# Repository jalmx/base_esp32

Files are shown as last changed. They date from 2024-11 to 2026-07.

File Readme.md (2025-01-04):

# Base for ESP32 for DevKit V4

## Schematic

This board is a base to connect different components to test. Make easy life

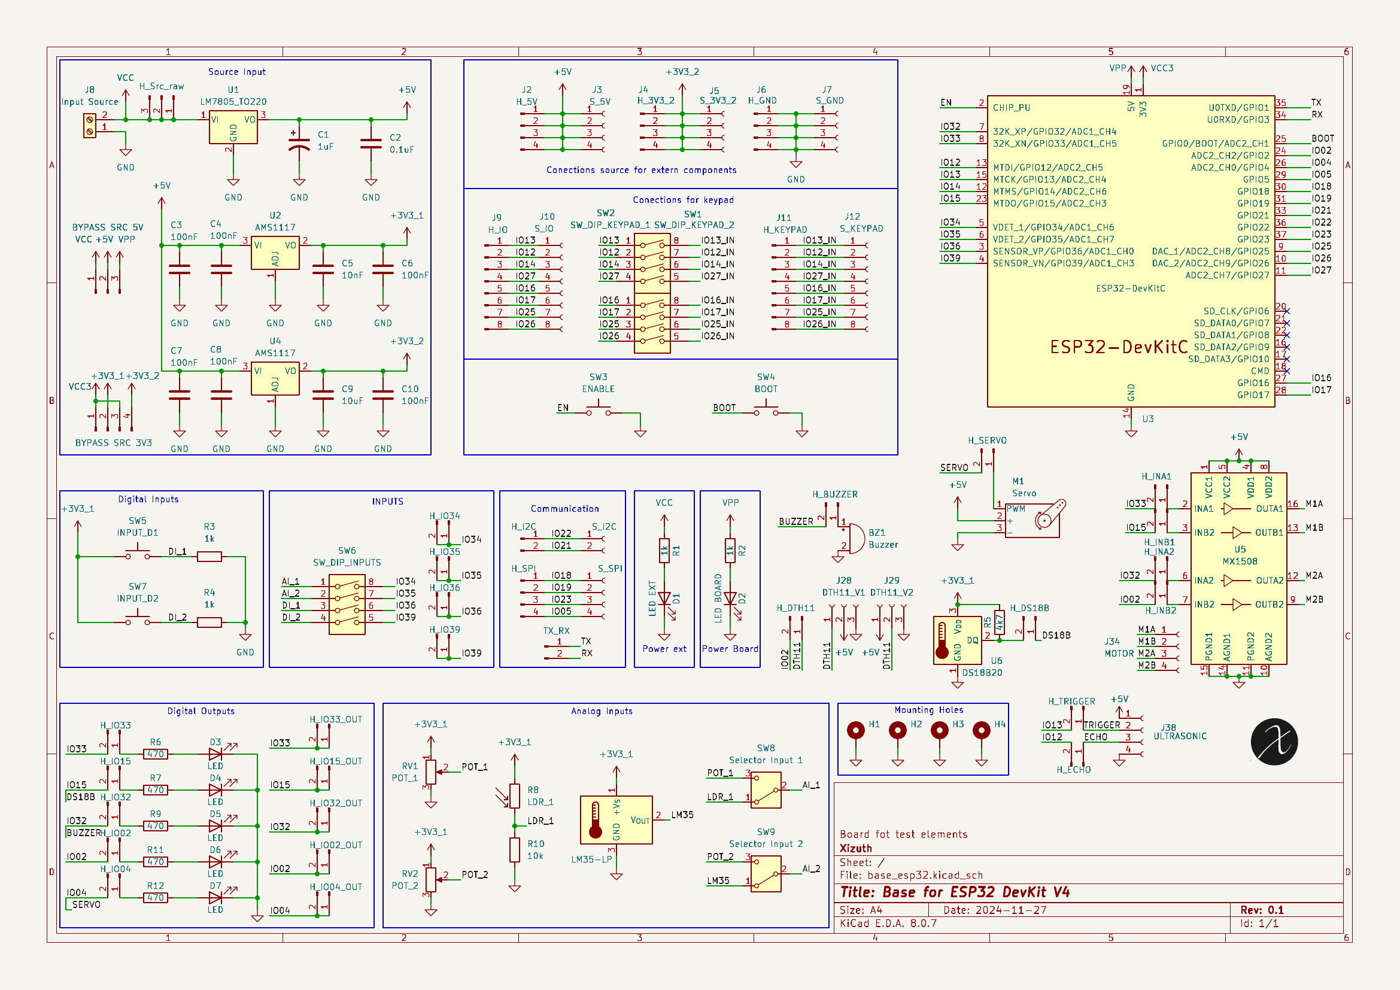
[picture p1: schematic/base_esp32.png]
schematic


## Silkscreen

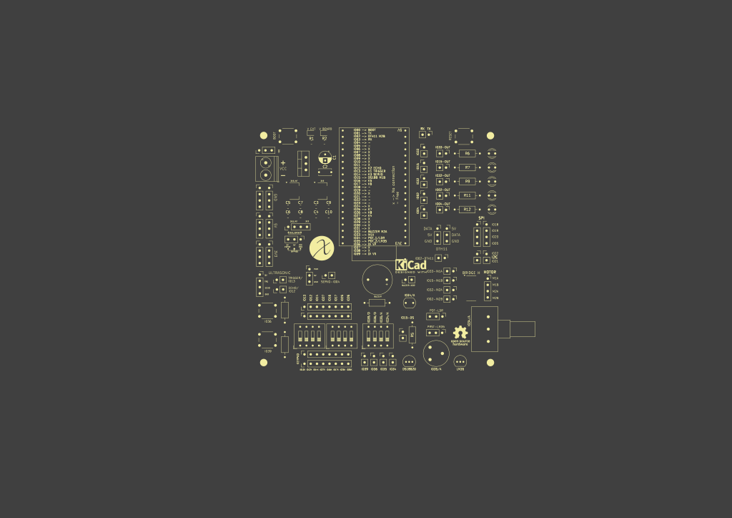
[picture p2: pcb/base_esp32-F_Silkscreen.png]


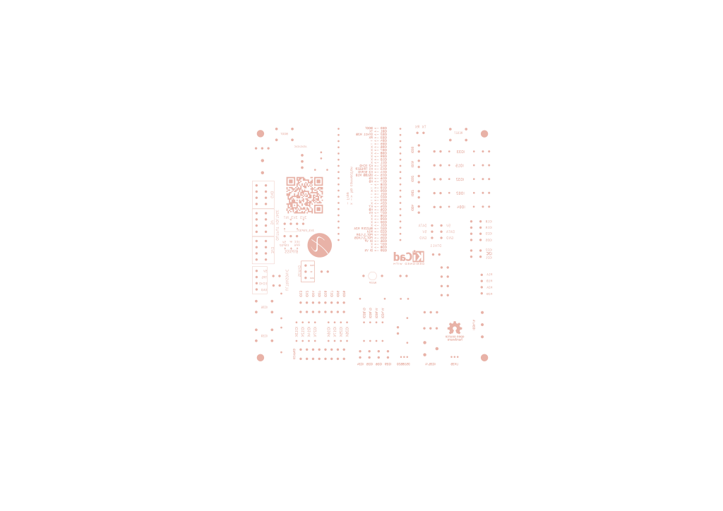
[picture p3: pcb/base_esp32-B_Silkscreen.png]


## 3D

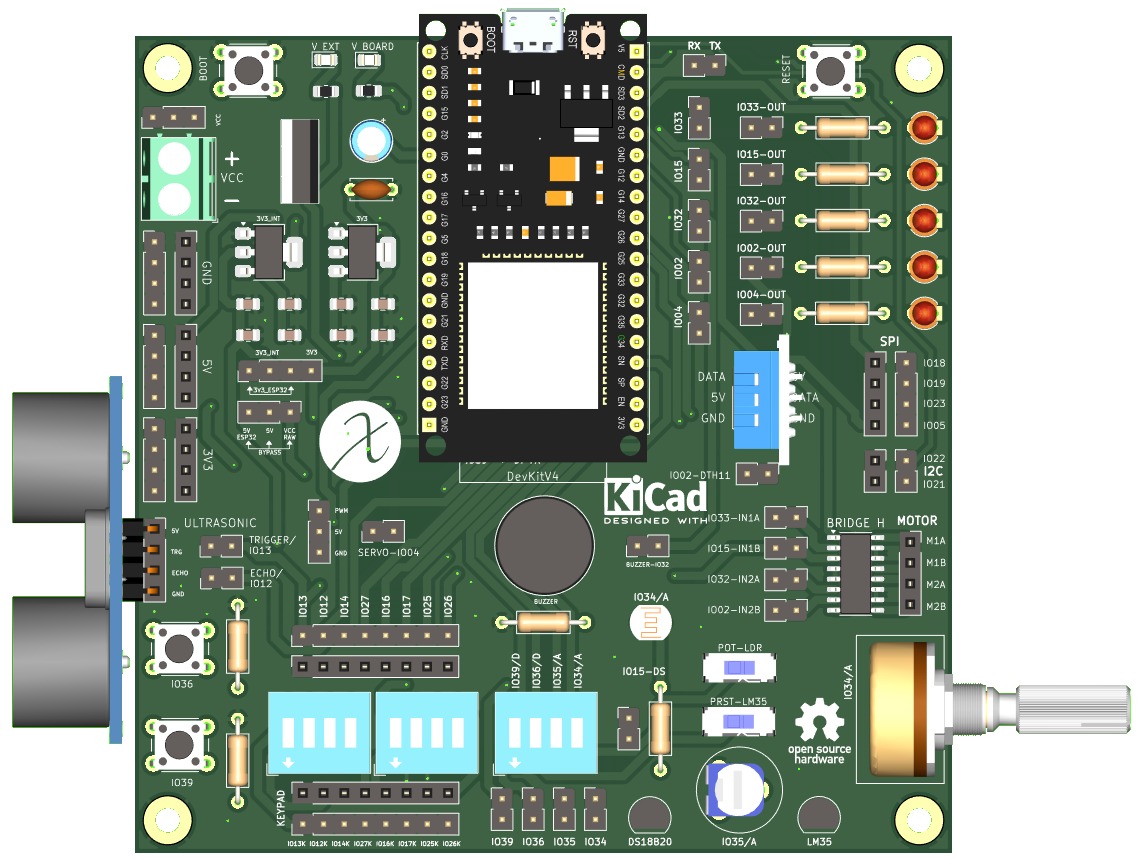
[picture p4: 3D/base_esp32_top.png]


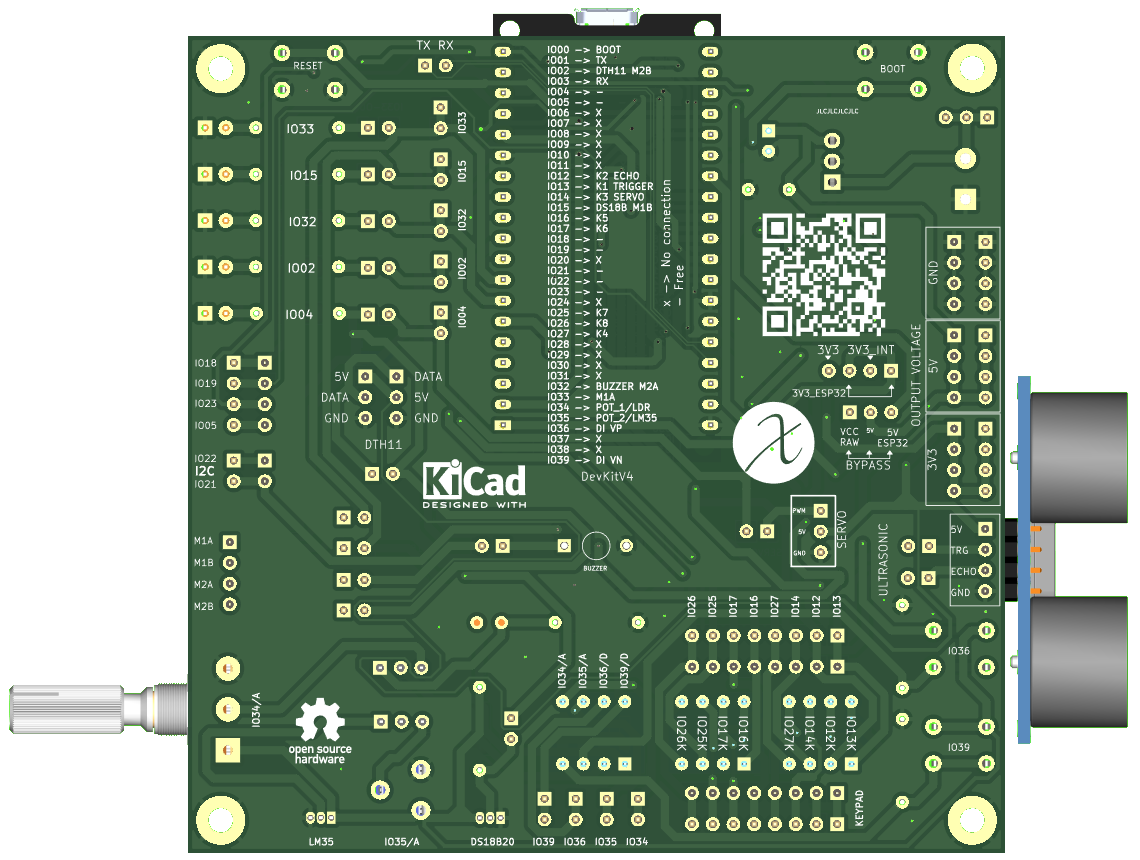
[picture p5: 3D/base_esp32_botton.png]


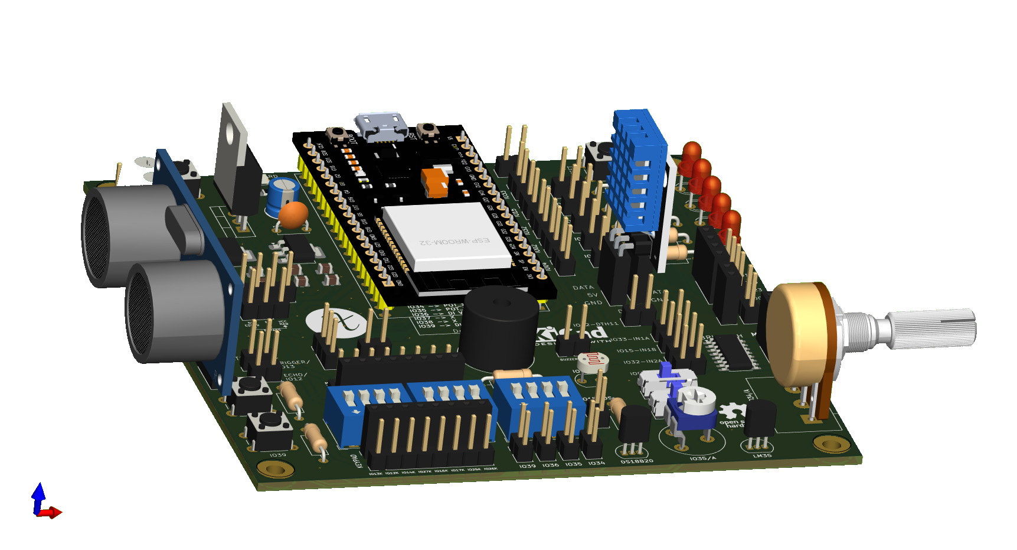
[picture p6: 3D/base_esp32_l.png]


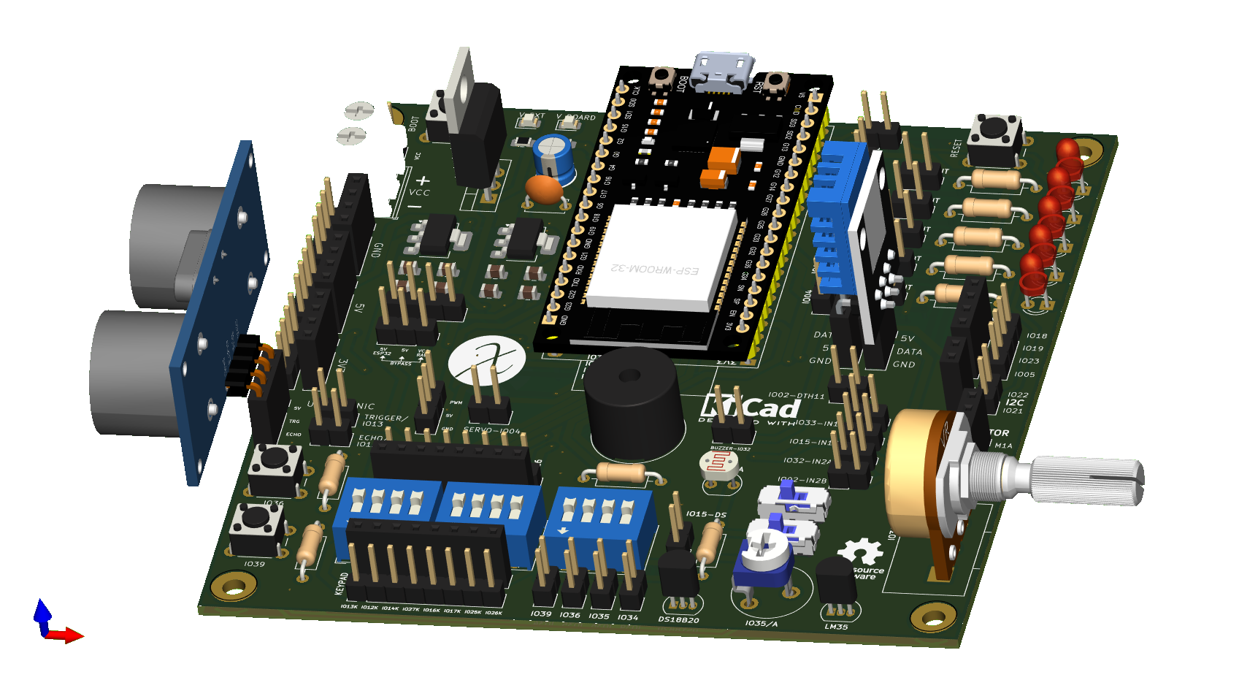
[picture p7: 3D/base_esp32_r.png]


## Ray

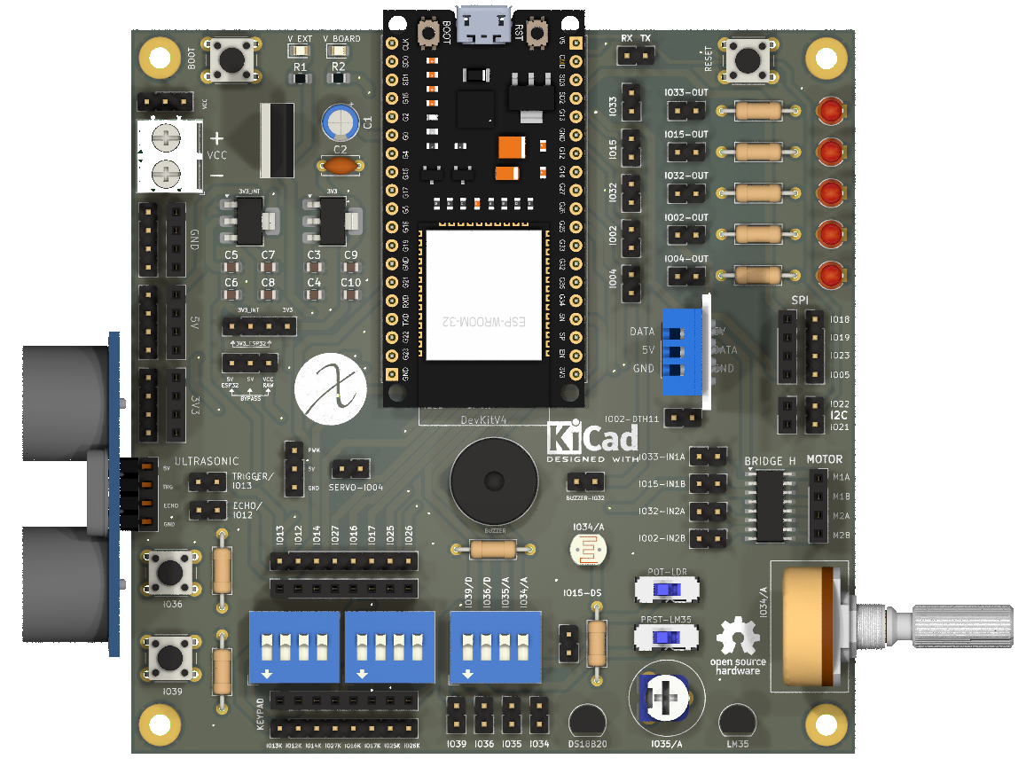
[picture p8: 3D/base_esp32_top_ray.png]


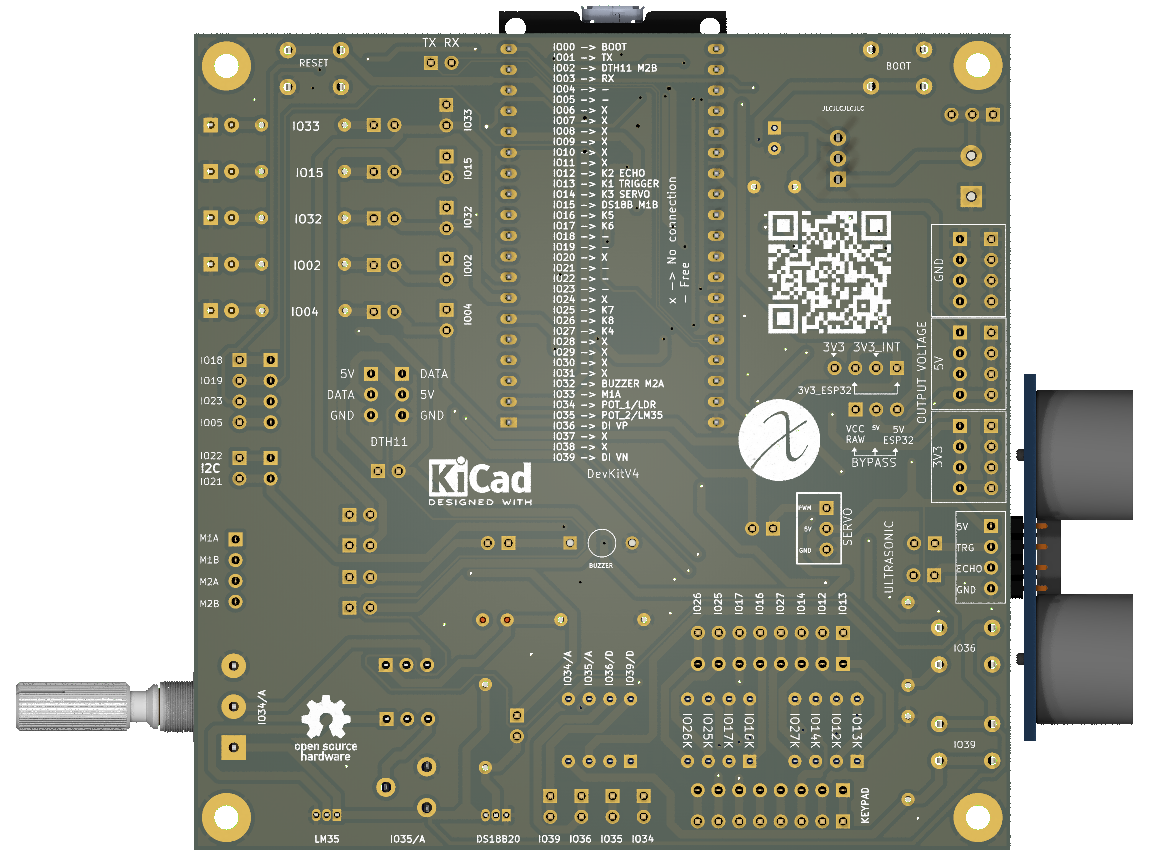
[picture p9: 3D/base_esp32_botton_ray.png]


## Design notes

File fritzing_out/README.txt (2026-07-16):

KiCad2Fritzing conversion output
Source board: /media/data/Projects/base_esp32/base_esp32.kicad_pcb

Generated files:
  Intermediate model: board_model.json
  Connector model: fritzing_connectors.json
  Fritzing part definition: base_esp32.fzp
  SVG views: icon.svg, breadboard.svg, schematic.svg, pcb.svg
  Fritzing shareable part: base_esp32.fzpz (ready to import)
  Validation report: artifact_validation.json

To import into Fritzing:
  1. Open Fritzing
  2. Right-click in the 'Mine' bin → Import...
  3. Select base_esp32.fzpz

Next step: refine SVG geometry from real board footprint data.

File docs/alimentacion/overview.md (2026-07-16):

# Visión general - Alimentación

## Árbol de potencia (Power Tree)

```
                    ┌─────────────────┐
                    │   ENTRADAS      │
                    │  ┌───────────┐  │
                    │  │ Jack DC   │  │  7-12V DC
                    │  │ 2.1mm     │──┤
                    │  └───────────┘  │
                    │        │        │
                    │  ┌───────────┐  │
                    │  │ USB Micro │  │  5V USB
                    │  │    -B     │──┤
                    │  └───────────┘  │
                    └────────┬────────┘
                             │
                    ┌────────▼────────┐
                    │  Diodo ORing    │  1N5819 Schottky
                    │  (Protección    │  Evita backfeed
                    │   polaridad)    │
                    └────────┬────────┘
                             │
                    ┌────────▼────────┐
                    │   LM7805CT      │  Regulador lineal 5V
                    │   TO-220        │  1.5A max
                    │  + Disipador    │  Dropout ~2V
                    └────────┬────────┘
                             │
              ┌──────────────┼──────────────┐
              │              │              │
       ┌──────▼──────┐ ┌─────▼─────┐ ┌─────▼─────┐
       │  +5V Rail   │ │  A9013    │ │  MX1508   │
       │  (Main)     │ │  Current  │ │  VMotor   │
       │             │ │  Sense    │ │           │
       └──────┬──────┘ └─────┬─────┘ └─────┬─────┘
              │              │             │
       ┌──────▼──────┐       │       ┌─────▼─────┐
       │ AMS1117-3.3 │       │       │ Terminal  │
       │  3.3V 800mA │       │       │  Block    │
       └──────┬──────┘       │       │  (Motor   │
              │              │       │  Power)   │
       ┌──────▼──────┐       │       └───────────┘
       │  +3.3V Rail │       │
       │  (Logic)    │       │
       └─────────────┘       │
                             │
                    ┌────────▼────────┐
                    │     SERVO       │  5V directo
                    │   Connector     │  (desde +5V Rail)
                    └─────────────────┘
```

## Rails de alimentación

| Rail | Voltaje | Corriente max | Origen | Consumidores |
|---|---|---|---|---|
| **VIN** | 7-12V | 1.5A | Jack/USB | LM7805 input |
| **+5V** | 5.0V | 1.5A | LM7805 | MX1508, Servo, Terminal, A9013, LED 5V |
| **+3.3V** | 3.3V | 800mA | AMS1117 | ESP32, Sensores, LEDs 3.3V, Pull-ups |
| **VMOTOR** | 5.0V | 2A | +5V Rail | MX1508 VM pin (separado por track ancho) |

## Esquema de protecciones

```
VIN (7-12V)
    │
    ├─► D1 (1N5819) ──► LM7805 ──► +5V
    │                    │
    │                    ├─► C_bulk 100µF
    │                    ├─► C_dec 100nF
    │                    ├─► LED_5V + 1kΩ
    │                    ├─► A9013 VCC
    │                    ├─► MX1508 VM
    │                    ├─► Servo VCC
    │                    └─► Terminal Block
    │
    └─► D2 (1N5819) ──► USB 5V ──► (Diodo ORing con Jack)
```

## Cálculos térmicos

### LM7805 (TO-220)

| Parámetro | Valor |
|---|---|
| V_in max | 12V |
| V_out | 5V |
| I_out max | 1.5A (datasheet) |
| I_typical | 500mA (ESP32 + sensores + LEDs) |
| P_dis = (Vin-Vout)×I | (12-5)×0.5 = **3.5W** |
| θ_JA (sin heatsink) | ~50°C/W |
| ΔT (sin heatsink) | 3.5×50 = **175°C** ❌ |
| θ_JA (con heatsink 10°C/W) | 3.5×10 = **35°C** ✅ |
| θ_JA (4 vias térmicas + pour) | ~25°C/W = **87.5°C** ⚠️ |

**Recomendación**: Usar disipador pequeño o limitar Vin a 9V max para uso continuo.

### AMS1117-3.3 (SOT-223)

| Parámetro | Valor |
|---|---|
| V_in | 5V |
| V_out | 3.3V |
| I_out max | 800mA |
| I_typical | 200mA (ESP32 TX + sensores) |
| P_dis | (5-3.3)×0.2 = **0.34W** |
| θ_JA (SOT-223 + vias) | ~40°C/W |
| ΔT | 0.34×40 = **13.6°C** ✅ |

### MX1508

- Pad térmico expuesto soldado a polygon VCC_MOTOR + vias a GND
- Corriente motor típica: 500mA-1A
- Protección térmica interna (150°C shutdown)

## Secuencia de encendido

```
1. VIN aplicado (Jack o USB)
         │
         ▼
2. Diodo ORing conduce
         │
         ▼
3. LM7805 enciende → +5V sube
         │
         ├─► LED 5V enciende
         ├─► A9013 alimentado
         ├─► MX1508 VM alimentado
         └─► Servo VCC alimentado
         │
         ▼
4. AMS1117 enciende → +3.3V sube
         │
         ├─► LED 3.3V enciende
         ├─► ESP32 sale de reset (EN HIGH)
         └─► Sensores alimentados
         │
         ▼
5. ESP32 boot → firmware inicia
```

## Puntos de test (Test Points)

| TP | Net | Ubicación | Uso |
|----|-----|---|-----|
| TP1 | VIN | Cerca Jack | Verificar entrada |
| TP2 | +5V | Cerca LM7805 out | Verificar 5V |
| TP3 | +3.3V | Cerca AMS1117 out | Verificar 3.3V |
| TP4 | GND | Múltiples | Referencia |
| TP5 | IMON_OUT | Cerca A9013 | Medir corriente |
| TP6 | VMOTOR | Cerca MX1508 | Verificar motor power |

## Medidas típicas (multímetro)

| Punto | Esperado | Tolerancia |
|---|---|---|
| Jack DC | 7-12V | ±5% |
| USB 5V | 4.75-5.25V | ±5% |
| +5V Rail | 4.9-5.1V | ±2% |
| +3.3V Rail | 3.25-3.35V | ±1.5% |
| Dropout LM7805 | ~2V | - |
| Dropout AMS1117 | ~1.1V | - |
| Corriente reposo (+5V) | ~50mA | - |
| Corriente reposo (+3.3V) | ~80mA | - |
| Corriente WiFi TX (+3.3V) | +150mA pico | - |

## Mejoras planificadas (v0.5)

Ver [Cambios planificados](../contribuir/guia.md#cambios-planificados)

- [ ] Añadir PTC/Polyfuse en entrada VIN
- [ ] TVS diodo en entrada (protección ESD/surge)
- [ ] LED indicador "Power Good" (AND de 5V y 3.3V)
- [ ] Jumper medición corriente serie en +5V/+3.3V

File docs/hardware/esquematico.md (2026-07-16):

# Esquemático

## Visión general

El esquemático está organizado en **hojas jerárquicas** por bloques funcionales:

```
base_esp32.kicad_sch
├── Portada (Title Block)
├── Hoja principal: Conexiones ESP32
├── Power_5V: LM7805 + entrada DC/USB
├── Power_3V3: AMS1117 3.3V
├── Power_Monitor: A9013 current sense
├── Motor_Driver: MX1508
├── Sensors: DS18B20, LM35, LDR
├── Actuators: Buzzer, LEDs, Servo, RGB
├── Inputs: DIP, Push, SPDT, Pot
├── Connectors: Headers, Terminal, Servo
└── Mounting: 4× Mounting holes
```

## Hoja principal: ESP32 DevKit V4

### Socket pinout (J1-J2, headers 2×19)

| Pin ESP32 | Función Base | Componente conectado |
|---|---|---|
| **GPIO0** | Boot/LED | LED D1 (pull-up) |
| **GPIO2** | LED Built-in / RGB | LED D2 + RGB WS2812B |
| **GPIO4** | User LED | LED D3 |
| **GPIO5** | User LED | LED D4 |
| **GPIO12** | Motor IN1 | MX1508 IN1 |
| **GPIO13** | Motor IN2 | MX1508 IN2 |
| **GPIO14** | Motor IN3 | MX1508 IN3 |
| **GPIO15** | Motor IN4 / ADC2_CH3 | MX1508 IN4 + Pot |
| **GPIO16** | Buzzer | Buzzer pasivo |
| **GPIO17** | DS18B20 | 1-Wire temp sensor |
| **GPIO18** | Servo PWM | Conector servo |
| **GPIO19** | I2C SCL | Header expansion |
| **GPIO21** | I2C SDA | Header expansion |
| **GPIO22** | SPI MISO | Header expansion |
| **GPIO23** | SPI MOSI | Header expansion |
| **GPIO25** | ADC2_CH8 / DAC1 | LM35 / User |
| **GPIO26** | ADC2_CH9 / DAC2 | LDR / User |
| **GPIO27** | ADC2_CH7 | User |
| **GPIO32** | ADC1_CH4 | User |
| **GPIO33** | ADC1_CH5 | User |
| **GPIO34** | ADC1_CH6 (input only) | Potenciómetro |
| **GPIO35** | ADC1_CH7 (input only) | User |
| **GPIO36** | ADC1_CH0 (input only) | LM35 |
| **GPIO39** | ADC1_CH3 (input only) | LDR |

> **Nota**: GPIO6-11 conectados a flash interno (no usar). GPIO34-39 solo entrada.

## Hoja Power_5V: LM7805

```
VIN (7-12V) ──┬──┬──► Jack DC (J_PWR)
              │  └──► USB 5V (via diodo Schottky)
              ▼
         ┌─────────┐
         │ LM7805  │──► +5V Rail
         │ TO-220  │     │
         └────┬────┘     ├─► Motor Driver (MX1508 VCC)
              │          ├─► Servo VCC
              │          ├─► Terminal Block (Motor Power)
              │          └─► A9013 Sense Input
              ▼
           GND
```

**Componentes clave:**
- **C1**: 470µF electrolítico (bulk input)
- **C2**: 100nF cerámico (decoupling input)
- **C3**: 100µF electrolítico (bulk output)
- **C4**: 100nF cerámico (decoupling output)
- **D1**: Diodo Schottky 1N5819 (protección USB/Jack)
- **D2**: LED Power 5V + R (1kΩ)
- **JP1**: Jumper selección fuente (Jack vs USB)

## Hoja Power_3V3: AMS1117

```
+5V Rail ──┬──► AMS1117-3.3 ──► +3.3V Rail
           │        │
           │        ├─► C5: 100µF (output bulk)
           │        └─► C6: 100nF (decoupling)
           │
           └──► LED 3.3V + R (1kΩ)
```

**Salida**: 800mA max (suficiente para ESP32 + sensores)

## Hoja Power_Monitor: A9013

```
+5V Rail ──► A9013 (Hall Effect) ──► GPIO34 (ADC1_CH6)
                    │
                    └─► Sensitivity: 400mV/A
                        Offset: 2.5V @ 0A
                        Range: ±5A
```

**Fórmula conversión:**
```cpp
float current = (adc_voltage - 2.5) / 0.4;  // Amperios
```

## Hoja Motor_Driver: MX1508

```
GPIO12 ──► IN1 ──┐
GPIO13 ──► IN2 ──┤   MX1508 (Dual H-Bridge)
GPIO14 ──► IN3 ──┤   │ OUT1+OUT2 = Motor A
GPIO15 ──► IN4 ──┘   │ OUT3+OUT4 = Motor B
                     ▼
              +5V Rail (VM)
              GND
              Terminal Block: MOT_A+, MOT_A-, MOT_B+, MOT_B-
```

**Especificaciones MX1508:**
- Voltaje: 2-10V
- Corriente: 1.5A cont / 2.5A pico por canal
- PWM: Hasta 20kHz
- Protección: Térmica, under-voltage

## Hoja Sensors

### DS18B20 (1-Wire)
```
GPIO17 ──► Data (pull-up 4.7kΩ a 3.3V)
VDD ──► 3.3V
GND ──► GND
```
**Dirección**: Parasite power o VDD mode (configurable por jumper)

### LM35 (Analógico)
```
GPIO36 (ADC1_CH0) ──► Vout
VDD ──► 3.3V
GND ──► GND
```
**Fórmula**: `Temp(°C) = ADC_mV / 10`

### LDR + Divisor tensión
```
GPIO39 (ADC1_CH3) ──► Punto medio
              ┌─────┴─────┐
              ▼           ▼
           LDR          10kΩ
              │           │
             3.3V        GND
```

## Hoja Actuators

### Buzzer pasivo
```
GPIO16 ──► Buzzer (+)
GND ─────► Buzzer (-)
```
**Frecuencia**: Control por PWM/tone()

### LEDs Usuario (×4)
```
GPIO0  ──► LED D1 (R=330Ω) ──► GND  (Boot indicator)
GPIO2  ──► LED D2 (R=330Ω) ──► GND  (Built-in / RGB)
GPIO4  ──► LED D3 (R=330Ω) ──► GND
GPIO5  ──► LED D4 (R=330Ω) ──► GND
```

### LED RGB (WS2812B)
```
GPIO2 ──► DIN (data)
3.3V ───► VDD
GND ────► VSS
```
**Nota**: Comparte GPIO2 con LED D2 - usar uno a la vez

### Conector Servo (3 pines estándar)
```
GPIO18 ──► Signal
5V  ─────► VCC (from 5V rail)
GND ─────► GND
```

## Hoja Inputs

### DIP Switch ×4 (SW1)
```
GPIO27 ──► SW1-1
GPIO32 ──► SW1-2
GPIO33 ──► SW1-3
GPIO35 ──► SW1-4
Común ───► GND (pull-up interno ESP32)
```

### Push Button (SW2)
```
GPIO25 ──► SW2 (momentary)
Común ───► GND (pull-up interno)
```

### SPDT Switch (SW3)
```
GPIO26 ──► SW3-COM
        ├──► SW3-NO (3.3V via R pull-up)
        └──► SW3-NC (GND)
```

### Potenciómetro 10k (RV1)
```
GPIO34 (ADC1_CH6) ──► Wiper
3.3V ────────────────► End 1
GND ────────────────► End 2
```

## Hoja Connectors

### Headers ESP32 (J1, J2 - 2×19)
- Pitch 2.54mm
- Macho en PCB, Hembra en DevKit
- Todas las señales GPIO, Power, GND

### Terminal Block 2×2 (J_TERM)
```
Pin 1: Motor A+
Pin 2: Motor A-
Pin 3: Motor B+
Pin 4: Motor B-
```
**Rating**: 10A, 250V, wire 12-24 AWG

### Conector Servo (J_SERVO)
- 3 pines 2.54mm (Signal, VCC, GND)
- Compatible estándar Futaba/JR

### Mounting Holes (×4)
- Diámetro 3.2mm (M3)
- Plated para conexión GND opcional
- Esquinas PCB (100×80mm)

## Referencias cruzadas

- [PCB Layout](pcb.md) - Implementación física
- [Componentes](componentes.md) - BOM completa
- [Pinout ESP32](pinout.md) - Mapeo detallado
- [Alimentación](../alimentacion/overview.md) - Análisis power tree

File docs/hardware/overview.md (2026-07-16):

# Visión general del hardware

## Arquitectura del sistema

```
┌─────────────────────────────────────────────────────────────┐
│                      ESP32 DevKit V4                        │
│  ┌─────────┐  ┌─────────┐  ┌─────────┐  ┌─────────┐        │
│  │  GPIO   │  │  ADC    │  │  PWM    │  │  Comm   │        │
│  │  0-39   │  │  18 ch  │  │  16 ch  │  │ I2C/SPI │        │
│  └────┬────┘  └────┬────┘  └────┬────┘  └────┬────┘        │
└───────┼────────────┼────────────┼────────────┼──────────────┘
        │            │            │            │
  ┌─────┴─────┐ ┌────┴────┐ ┌─────┴─────┐ ┌────┴────┐
  │  Power    │ │ Sensors │ │ Actuators │ │  I/O    │
  │  5V/3.3V  │ │ DS18B20 │ │ MX1508    │ │ Switches│
  │  Monitor  │ │ LM35    │ │ Servo     │ │ Potenci │
  │  A9013    │ │ LDR     │ │ Buzzer    │ │ LEDs    │
  └───────────┘ └─────────┘ └───────────┘ └─────────┘
```

## Vista 3D de la placa

=== "Superior"
    Top

=== "Inferior"
    Bottom

=== "Lateral Izquierda"
    Left

=== "Lateral Derecha"
    Right

=== "Render Superior"
    Ray Top

=== "Render Inferior"
    Ray Bottom

## Bloques funcionales

| Bloque | Componentes clave | Página |
|---|---|---|
| **Alimentación** | LM7805, AMS1117, A9013, jack DC, USB | [Alimentación](../alimentacion/overview.md) |
| **MCU** | ESP32 DevKit V4 socket | [Pinout](pinout.md) |
| **Motor DC** | MX1508 (2 canales H-bridge) | [Actuadores](../perifericos/actuadores.md) |
| **Sensores** | DS18B20, LM35, LDR | [Sensores](../perifericos/sensores.md) |
| **Actuadores** | Buzzer, 4×LED, Servo, LED RGB | [Actuadores](../perifericos/actuadores.md) |
| **Entradas** | DIP×4, Push, SPDT, Pot 10k | [Entradas](../perifericos/entradas.md) |
| **Conectividad** | Headers ESP32, Terminal tornillo, Servo | [Pinout](pinout.md) |

## Esquemático completo

Esquemático

## PCB Layout

=== "Capa Superior (F.Cu)"
    Top Copper

=== "Capa Inferior (B.Cu)"
    Bottom Copper

=== "Silkscreen Superior"
    Top Silk

=== "Silkscreen Inferior"
    Bottom Silk

=== "Máscara Superior"
    Top Mask

=== "Máscara Inferior"
    Bottom Mask

## Decisiones de diseño clave

1. **Alimentación dual**: 5V para motor/servo, 3.3V para ESP32 y sensores
2. **Monitor corriente**: A9013 en rail principal para protección
3. **Driver MX1508**: SMD, compacto, 1.5A/canal, PWM hasta 20kHz
4. **Socket ESP32**: Permite cambio de módulo, reduce riesgo soldadura
5. **Headers estándar**: Pitch 2.54mm compatible breadboard/dupont
6. **Terminal tornillo**: Conexión robusta para motor/alimentación externa
7. **Test points**: Verificación rails de alimentación sin soldar

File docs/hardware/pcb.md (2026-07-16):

# PCB Layout

## Especificaciones físicas

| Parámetro | Valor |
|---|---|
| **Dimensiones** | 100mm × 80mm |
| **Capas** | 2 (Top/Bottom) |
| **Material** | FR-4, 1.6mm |
| **Cobre** | 35µm (1oz) |
| **Via mínimo** | 0.3mm / 0.6mm pad |
| **Track mínimo** | 0.15mm (6mil) |
| **Clearance** | 0.15mm (6mil) |
| **Huecos montaje** | 4× M3 (3.2mm plated) |

## Stackup

```
┌─────────────────────────────────────┐
│  Top Silkscreen (F.SilkS)           │
│  Top Solder Mask (F.Mask)           │
│  Top Copper (F.Cu) ◄── Señales + Power │
├─────────────────────────────────────┤  Core FR-4 1.4mm
│  Bottom Copper (B.Cu) ◄── GND Pour  │
│  Bottom Solder Mask (B.Mask)        │
│  Bottom Silkscreen (B.SilkS)        │
└─────────────────────────────────────┘
```

## Capas de cobre

=== "Top Copper (F.Cu)"
    Top Copper
    - Ruteo principal señales
    - Polygons: +3.3V, +5V, VCC_MOTOR
    - Pads SMD componentes

=== "Bottom Copper (B.Cu)"
    Bottom Copper
    - **Ground Pour** completa (GND net)
    - Algunas señales de cruce
    - Pads THT

## Planos de alimentación (Polygons)

### Top Layer Polygons

| Net | Área | Props |
|-----|---|---|
| **+5V** | Zona inferior izq | Thermal relief vias |
| **+3.3V** | Zona central | Zona central | Thermal relief |
| **VCC_MOTOR** | Debajo MX1508 | Direct pour, sin relief |
| **GND** | Relleno resto | Via stitching |

### Bottom Layer
- **GND Pour** completo con **via stitching** cada 5mm
- Conecta a GND pads THT y vias térmicas

## Reglas de diseño (Design Rules)

| Regla | Valor | Aplicación |
|---|---|---|
| Clearance | 0.15mm (6mil) | General |
| Track width (signal) | 0.2mm (8mil) | GPIO, comms |
| Track width (power 5V) | 0.5mm (20mil) | LM7805, MX1508 |
| Track width (power 3.3V) | 0.4mm (16mil) | AMS1117, ESP32 |
| Track width (motor) | 1.0mm (40mil) | Terminal block ↔ MX1508 |
| Via size | 0.3/0.6mm | Signal |
| Via power | 0.5/1.0mm | Power polygons |
| Thermal relief | 0.25mm gap, 4 spokes | Polygon connects |

## Decisiones de layout críticas

### 1. Separación dominios de potencia
```
┌────────────────────────────────────────┐
│  +5V (Motor)    │  +3.3V (Logic)       │
│  ┌──────────┐   │  ┌──────────┐        │
│  │ LM7805   │   │  │ AMS1117  │        │
│  │ MX1508   │   │  │ ESP32    │        │
│  │ Terminal │   │  │ Sensors  │        │
│  └──────────┘   │  └──────────┘        │
│        │        │        │             │
│        └────────┴────────┘             │
│                 GND (common)           │
└────────────────────────────────────────┘
```
- **GND común** (star ground en conector alimentación)
- Polygons separados en Top, unidos por vias en GND
- Evita loops de corriente motor en ground logic

### 2. Ruteo señales sensibles
- **ADC traces** (LM35, LDR, Pot): Cortas, lejos de PWM motor
- **1-Wire (DS18B20)**: Pull-up cerca GPIO, track ancho 0.3mm
- **I2C/SPI**: Paralelas, ground guard entre líneas
- **PWM Motor**: Tracks anchas, ground shield adyacente

### 3. Disipación térmica
- **LM7805**: Pad TO-220 con 4 vias térmicas a GND pour bottom
- **AMS1117**: Pad SOT-223 con vias térmicas
- **MX1508**: Pad expuesto conectado a VCC_MOTOR polygon + vias a GND

### 4. Conector ESP32
- Headers 2×19 alineados borde PCB
- Señales GPIO ruteadas perpendicular al conector
- Minimiza longitud stubs

## Silkscreen (F.SilkS / B.SilkS)

=== "Top Silkscreen"
    Top Silk

=== "Bottom Silkscreen"
    Bottom Silk

**Elementos clave:**
- ✅ Referencias componentes (R1, C1, U1, J1...)
- ✅ Polaridad LED, diodos, electrolíticos
- ✅ Pin 1 en conectores e ICs
- ✅ Etiquetas funcionales: "5V", "3.3V", "GND", "MOTOR", "SERVO"
- ✅ **NUEVO v0.4**: Nombres reguladores junto a footprint
- ✅ Logo Xizuth + QR code repositorio
- ✅ Versión PCB (v0.4) y fecha

## Solder Mask & Paste

=== "Top Mask"
    Top Mask

=== "Bottom Mask"
    Bottom Mask

=== "Top Paste"
    Top Paste

=== "Bottom Paste"
    Bottom Paste

## Edge Cuts

Edge Cuts

- Rectángulo 100×80mm
- Esquinas redondeadas R=2mm
- 4 cutouts para mounting holes M3
- Sin cutouts internos

## Fabricación - Archivos Gerber

Ver [Fabricación > Archivos Gerber](../fabricacion/gerber.md) para lista completa y visualizador.

## Validación DRC

```bash
# Ejecutar DRC en KiCad 8/9
# Inspect > Design Rule Checker
# Run DRC
# Errors: 0 | Warnings: 0 (esperado)
```

**Checks críticos:**
- [ ] Clearance violations
- [ ] Track width vs current
- [ ] Via count thermal relief
- [ ] Unconnected nets
- [ ] Footprint courtyard overlaps
- [ ] Silk over pads
- [ ] Missing thermal reliefs

## Exportaciones disponibles

| Formato | Ubicación | Uso |
|---|---|-----|
| **KiCad PCB** | `base_esp32.kicad_pcb` | Edición |
| **Gerber ZIP** | `gerber/base_esp32_v4.zip` | Fabricación |
| **STEP 3D** | `step/base_esp32.step` | Mechanical CAD |
| **SVG Layers** | `pcb/*.svg` | Documentación |
| **PNG Renders** | `3D/*.png` | Visualización |
| **BOM** | `fabricacion/bom.csv` | Compras |
| **Pick&Place** | `fabricacion/pnp.csv` | Assembly SMT |

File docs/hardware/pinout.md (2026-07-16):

# Pinout ESP32 DevKit V4

## Pinout visual

ESP32 DevKit V4 Pinout

## Mapeo Base ESP32 → ESP32 DevKit V4

| Base ESP32 Pin | GPIO | Función Base | Tipo | Notas |
|---|---|---|---|---|
| **J1-1** | GPIO36 (VP) | ADC1_CH0 | Input only | LM35 Temp |
| **J1-2** | GPIO39 (VN) | ADC1_CH3 | Input only | LDR |
| **J1-3** | GPIO34 | ADC1_CH6 | Input only | Potenciómetro |
| **J1-4** | GPIO35 | ADC1_CH7 | Input only | SW_DIP-4 |
| **J1-5** | GPIO32 | ADC1_CH4 / Touch | I/O | SW_DIP-2, LED_USR? |
| **J1-6** | GPIO33 | ADC1_CH5 / Touch | I/O | SW_DIP-3 |
| **J1-7** | GPIO25 | ADC2_CH8 / DAC1 | I/O | Buzzer |
| **J1-8** | GPIO26 | ADC2_CH9 / DAC2 | I/O | SW_SPDT, LDR alt |
| **J1-9** | GPIO27 | ADC2_CH7 / Touch | I/O | SW_DIP-1 |
| **J1-10** | GPIO14 | ADC2_CH6 / Touch | I/O | Motor IN3 |
| **J1-11** | GPIO12 | ADC2_CH5 / Touch | I/O | Motor IN1 (boot strapping!) |
| **J1-12** | GPIO13 | ADC2_CH4 / Touch | I/O | Motor IN2 |
| **J1-13** | GPIO15 | ADC2_CH3 / Touch | I/O | Motor IN4, Pot alt (strap!) |
| **J1-14** | GPIO2 | ADC2_CH2 / Touch | I/O | LED Built-in / RGB DIN |
| **J1-15** | GPIO0 | ADC2_CH1 / Touch | I/O | LED D1 / Boot (strap!) |
| **J1-16** | GPIO4 | ADC2_CH0 / Touch | I/O | LED D3 |
| **J1-17** | GPIO16 | - | I/O | (Libre) |
| **J1-18** | GPIO17 | - | I/O | DS18B20 1-Wire |
| **J1-19** | GPIO5 | - | I/O | LED D4 |
| **J1-20** | GPIO18 | - | I/O | Servo PWM |
| **J1-21** | GPIO19 | - | I/O | I2C SCL / SPI MISO |
| **J1-22** | GPIO21 | - | I/O | I2C SDA |
| **J1-23** | GPIO22 | - | I/O | Libre / SPI MISO alt |
| **J1-24** | GPIO23 | - | I/O | SPI MOSI |
| **J1-25** | GND | - | Power | Ground |
| **J1-26** | VIN | - | Power | 5V Input (from LM7805) |
| **J1-27** | 3V3 | - | Power | 3.3V Output (from AMS1117) |
| **J1-28** | EN | - | Input | Enable (reset) |
| **J1-29** | GPIO3 (RX0) | UART0_RX | I/O | Serial Debug |
| **J1-30** | GPIO1 (TX0) | UART0_TX | I/O | Serial Debug |
| **J1-31** | GPIO18 | - | I/O | (Duplicate J1-20) |
| **J1-32** | GPIO19 | - | I/O | (Duplicate J1-21) |
| **J1-33** | GPIO21 | - | I/O | (Duplicate J1-22) |
| **J1-34** | GPIO22 | - | I/O | (Duplicate J1-23) |
| **J1-35** | GPIO23 | - | I/O | (Duplicate J1-24) |
| **J1-36** | GND | - | Power | Ground |
| **J1-37** | VIN | - | Power | 5V Input |
| **J1-38** | 3V3 | - | Power | 3.3V Output |

## Strapping Pins (¡Cuidado al arranque!)

| GPIO | Estado por defecto | Función strap | Uso en Base | Precaución |
|---|---|---|---|---|
| **GPIO0** | Pull-up | Boot mode | LED D1 | **LOW = Download boot** - LED pull-up OK |
| **GPIO2** | Pull-down | Boot/SDIO | LED Built-in / RGB | **HIGH = SDIO boot** - Pull-down interno OK |
| **GPIO12** | Pull-down | Flash voltage | Motor IN1 | **HIGH = 1.8V flash** - Motor driver pull-down OK |
| **GPIO15** | Pull-up | Boot logging | Motor IN4 / Pot | **LOW = Silent boot** - Pot divider cuidado |

> ⚠️ **Regla de oro**: No conectar cargas que fuercen estado contrario al strap en estos pines durante reset.

## Pines solo entrada (Input Only)

| GPIO | ADC Canal | Uso en Base |
|---|---|---|
| **GPIO34** | ADC1_CH6 | Potenciómetro |
| **GPIO35** | ADC1_CH7 | SW_DIP-4 |
| **GPIO36** | ADC1_CH0 | LM35 |
| **GPIO39** | ADC1_CH3 | LDR |

*No tienen pull-up/pull-down interno. Usar resistencias externas si necesario.*

## Pines con funciones especiales

| GPIO | Función especial | Uso Base |
|---|---|---|
| **GPIO25** | DAC1 | Buzzer (PWM/tone) |
| **GPIO26** | DAC2 | Libre / SW_SPDT |
| **GPIO17** | - | DS18B20 (1-Wire) |
| **GPIO18** | - | Servo (PWM 50Hz) |
| **GPIO19** | SPI0_MISO / I2C | I2C SCL |
| **GPIO21** | I2C_SDA | I2C SDA |
| **GPIO22** | SPI0_MISO | Libre |
| **GPIO23** | SPI0_MOSI | Libre |

## Periféricos disponibles (no usados en Base)

| Periférico | Pines disponibles | Notas |
|---|---|---|
| **UART1** | GPIO9/10 (flash) / GPIO16/17 | GPIO16/17 libres |
| **UART2** | GPIO16/17 | GPIO16 libre, GPIO17 = DS18B20 |
| **I2C** | Cualquier GPIO | GPIO19/21 usados, otros libres |
| **SPI** | Cualquier GPIO (VSPI/HSPI) | GPIO18/19/21/22/23 parcialmente usados |
| **PWM** | 16 canales (cualquier GPIO) | 4 usados motor, 1 servo, 1 buzzer |
| **ADC2** | GPIO0,2,4,12-15,25-27 | **No usable con WiFi activo** |
| **Touch** | GPIO0,2,4,12-15,25-27,32-33 | 10 canales disponibles |

## Headers de expansión en Base

### J_I2C (4 pines)
| Pin | Señal |
|-----|---|
| 1 | 3.3V |
| 2 | GND |
| 3 | SDA (GPIO21) |
| 4 | SCL (GPIO19) |

### J_SPI (6 pines)
| Pin | Señal |
|-----|---|
| 1 | 3.3V |
| 2 | GND |
| 3 | MOSI (GPIO23) |
| 4 | MISO (GPIO19/22) |
| 5 | SCK (GPIO18) |
| 6 | CS (GPIO5/22) |

### J_GPIO (10 pines)
| Pin | GPIO | Nota |
|-----|---|---|
| 1 | 3.3V | |
| 2 | GND | |
| 3 | GPIO16 | Libre |
| 4 | GPIO17 | DS18B20 |
| 5 | GPIO22 | Libre |
| 6 | GPIO23 | Libre |
| 7 | GPIO25 | Buzzer |
| 8 | GPIO26 | SW_SPDT |
| 9 | GPIO27 | SW_DIP-1 |
| 10 | GPIO32 | SW_DIP-2 |

## Referencia rápida Programación

```cpp
// Definiciones pines Base ESP32
#define PIN_LED_D1       0   // Boot LED
#define PIN_LED_BUILTIN  2   // Built-in / RGB
#define PIN_LED_D3       4
#define PIN_LED_D4       5
#define PIN_MOTOR_IN1    12
#define PIN_MOTOR_IN2    13
#define PIN_MOTOR_IN3    14
#define PIN_MOTOR_IN4    15
#define PIN_BUZZER       25
#define PIN_DS18B20      17
#define PIN_SERVO        18
#define PIN_I2C_SDA      21
#define PIN_I2C_SCL      19
#define PIN_SW_DIP1      27
#define PIN_SW_DIP2      32
#define PIN_SW_DIP3      33
#define PIN_SW_DIP4      35
#define PIN_SW_PUSH      25  // Comparte con Buzzer!
#define PIN_SW_SPDT      26
#define PIN_POT          34
#define PIN_LM35         36
#define PIN_LDR          39
#define PIN_IMON         34  // Comparte con Pot!

// ADC2 pins (no usar con WiFi)
#define ADC2_PINS {0, 2, 4, 12, 13, 14, 15, 25, 26, 27}
```

## Recursos adicionales

- [Espressif ESP32 Datasheet](https://www.espressif.com/sites/default/files/documentation/esp32_datasheet_en.pdf)
- [ESP32 Technical Reference Manual](https://www.espressif.com/sites/default/files/documentation/esp32_technical_reference_manual_en.pdf)
- [Pinout interactivo](https://www.espressif.com/sites/default/files/documentation/esp32-wroom-32e_esp32-wrover-32e_datasheet_en.pdf)

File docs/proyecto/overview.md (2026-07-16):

# Visión general del proyecto

## ¿Qué es Base ESP32?

**Base ESP32** es una placa de desarrollo (shield/baseboard) diseñada específicamente para el módulo **ESP32 DevKit V4** (ESP32-WROOM-32E). Su objetivo es proporcionar una plataforma completa y lista para usar que permita:

- **Aprender** programación de sistemas embebidos e IoT
- **Prototipar** rápidamente proyectos con sensores y actuadores
- **Enseñar** conceptos de electrónica y firmware en entornos educativos
- **Desarrollar** proof-of-concepts sin necesidad de breadboards

## Público objetivo

| Perfil | Uso |
|---|-----|
| **Estudiantes** | Prácticas de laboratorio, TFG, proyectos finales |
| **Makers** | Prototipado rápido, domótica, robótica ligera |
| **Docentes** | Material didáctico para asignaturas de IoT/embebidos |
| **Ingenieros** | Validación de conceptos, testing de firmware |

## Especificaciones rápidas

| Parámetro | Valor |
|---|---|
| **Dimensiones PCB** | 100mm × 80mm (aprox) |
| **Capas** | 2 capas (FR-4) |
| **Alimentación entrada** | 7-12V DC (jack) / 5V USB |
| **Corriente máxima 5V** | 1.5A (LM7805) |
| **Corriente máxima 3.3V** | 800mA (AMS1117) |
| **Temperatura operación** | -40°C a +85°C |

## Versiones de hardware

| Versión | Fecha | Cambios principales |
|---|---|---|
| **v0.1** | Nov 2024 | Diseño inicial, componentes básicos |
| **v0.2** | Ene 2025 | Añadido monitor corriente, ajustes silkscreen |
| **v0.3** | Abr 2025 | Cambio driver motor a MX1508, LED RGB |
| **v0.4** | Jul 2026 | Optimización layout, nuevos footprints |

> **Nota**: Ver [Historia y versiones](historia.md) para changelog detallado.

## Repositorio y archivos

```
base_esp32/
├── *.kicad_sch          # Esquemático KiCad
├── *.kicad_pcb          # Layout PCB KiCad
├── *.kicad_pro          # Proyecto KiCad
├── gerber/              # Archivos de fabricación
├── 3D/                  # Renders 3D
├── pcb/                 # Exportaciones capas PCB
├── assets/              # Imágenes, pinouts, logos
├── datasheets/          # Datasheets componentes
├── models/              # Modelos 3D STEP
├── docs/                # Esta documentación
└── README.md            # README principal
```

## Comunidad y soporte

- **Issues**: [GitHub Issues](https://github.com/Xizuth/base_esp32/issues)
- **Discusiones**: [GitHub Discussions](https://github.com/Xizuth/base_esp32/discussions)
- **Email**: jalm_x@hotmail.com (Josef Leyva)

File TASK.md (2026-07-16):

# Tareas pendientes - Documentación Base ESP32

## Completado

- [x] Instalar mkdocs-material 9.7.6
- [x] Crear `mkdocs.yml` (Material theme, nav completa, extensions)
- [x] Crear symlinks imágenes (`docs/images/`)
- [x] Crear estructura directorios (`proyecto/`, `hardware/`, `alimentacion/`, `perifericos/`, `practicas/`, `ensamblaje/`, `fabricacion/`, `kicad/`, `recursos/`, `contribuir/`, `about/`)
- [x] **docs/index.md** - Página principal
- [x] **docs/proyecto/** - overview.md, historia.md, licencia.md
- [x] **docs/hardware/** - overview.md, esquematico.md, pcb.md, componentes.md, pinout.md
- [x] **docs/alimentacion/** - overview.md, reguladores.md, proteccion.md
- [x] **docs/perifericos/** - leds.md, buzzer.md, sensores.md, actuadores.md, entradas.md, monitoreo.md
- [x] **docs/practicas/** - index.md + 12 prácticas (beginner 01-04, intermediate 05-08, advanced 09-12)
- [x] **docs/ensamblaje/** - index.md, componentes.md, soldadura.md, paso-a-paso.md, verificacion.md
- [x] **docs/fabricacion/** - gerber.md, fabricacion.md, fritzing.md
- [x] **docs/kicad/** - instalacion.md, estructura.md, modificacion.md, librerias.md

---

## Pendiente

### Páginas de docs faltantes

- [ ] **docs/recursos/datasheets.md** - Tabla con datasheets de cada componente, enlaces oficiales
- [ ] **docs/recursos/enlaces.md** - Enlaces útiles: tutoriales, herramientas, comunidades ESP32
- [ ] **docs/recursos/tools.md** - Herramientas: IDE, multímetro, osciloscopio, programadores
- [ ] **docs/contribuir/guia.md** - Guía de contribución: fork, branch naming, PRs, convenciones commits
- [ ] **docs/about/creditos.md** - Créditos, autores, licencias de dependencias, logos

### Archivos raíz

- [ ] **Readme.md** - Reescribir completamente:
  - Badges (License, Build Status, Spanish)
  - Descripción en español + inglés
  - Sección Features (componentes, periféricos, prácticas)
  - Imágenes destacadas (3D top, schematic)
  - Quick Start (cómo clonar, abrir en KiCad, fabricar)
  - Link a documentación (`https://xizuth.github.io/base_esp32/`)
  - Dev section (mkdocs build, preview)
  - Tabla de contenidos

- [ ] **.gitignore** - Reescribir con reglas completas:
  - KiCad: `*.kicad_sch-bak`, `*.kicad_pcb-bak`, `fp-info-cache`, `*-backups/`, `*.bak`, `*.lck`, `*.tmp`, `_autosave-*`
  - Python: `venv/`, `__pycache__/`, `*.pyc`, `.env`
  - MkDocs: `site/`
  - OS: `.DS_Store`, `Thumbs.db`, `Desktop.ini`
  - IDEs: `.vscode/`, `.idea/`, `*.swp`, `*.swo`, `*~`
  - Build: `*.o`, `*.elf`, `*.bin`, `build/`

### Verificación

- [ ] Ejecutar `mkdocs build --strict -d /tmp/mkdocs-test` para verificar que no hay errores de compilación

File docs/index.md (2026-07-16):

# Base ESP32 DevKit V4

!!! info "Placa de entrenamiento para IoT y sistemas embebidos"
    Una placa base diseñada para facilitar el aprendizaje y prototipado con el módulo **ESP32 DevKit V4**. Incluye reguladores de voltaje, drivers de motor, sensores, actuadores y múltiples conectores para expansión.

## Características principales

| Categoría | Detalles |
|---|---|
| **MCU** | ESP32 DevKit V4 (ESP32-WROOM-32E) |
| **Alimentación** | 5V (LM7805) + 3.3V (AMS1117) con protección |
| **Motor** | Driver MX1508 dual H-bridge (2 canales) |
| **Sensores** | DS18B20 (temp), LM35 (temp), LDR (luz) |
| **Actuadores** | Buzzer, 4 LEDs, conector servo |
| **Entradas** | 4× DIP switch, pulsador, SPDT, potenciómetro |
| **Conectores** | 40+ pines header, terminal tornillo, servo |
| **Monitoreo** | Sensor de corriente A9013 |

## Vistas de la placa

=== "3D Superior"
    3D Top

=== "3D Inferior"
    3D Bottom

=== "3D Lateral"
    3D Side

=== "Render Raytraced"
    3D Ray

## Silkscreen PCB

=== "Frontal"
    Silkscreen Top

=== "Trasera"
    Silkscreen Bottom

## Esquemático

Esquemático

## Inicio rápido

```bash
# Clonar repositorio
git clone https://github.com/Xizuth/base_esp32.git
cd base_esp32

# Instalar dependencias de documentación
pip install -r requirements.txt

# Ver documentación local
mkdocs serve
```

## Enlaces útiles

- [Documentación completa](https://xizuth.github.io/base_esp32)
- [Repositorio GitHub](https://github.com/Xizuth/base_esp32)
- [Reportar issue](https://github.com/Xizuth/base_esp32/issues)
- [Datasheet ESP32](https://www.espressif.com/sites/default/files/documentation/esp32-wroom-32e_esp32-wrover-32e_datasheet_en.pdf)

## Licencia

Este proyecto está bajo licencia **MIT**. Ver [LICENSE.md](../LICENSE.md) para detalles.

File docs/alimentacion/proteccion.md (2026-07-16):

# Alimentación - Protecciones

## Protecciones implementadas

| Protección | Componente | Ubicación | Función |
|---|---|---|---|
| **Polaridad inversa** | 1N5819 (D1) | Entrada Jack DC | Bloquea Vin negativo |
| **Oring USB/Jack** | 1N5819 (D2) | Entrada USB 5V | Previene backfeed |
| **Descarga C_OUT** | 1N5819 (D3) | LM7805 OUT→IN | Protege regulador al apagar |
| **Térmica LM7805** | Interno | Silicio | Shutdown @ 150°C |
| **Térmica AMS1117** | Interno | Silicio | Shutdown @ 150°C |
| **Térmica MX1508** | Interno | Silicio | Shutdown @ 150°C |
| **Límite corriente MX1508** | Interno | Driver | ~2.5A peak/canal |

---

## Esquemas de protección

### 1. Diodo polaridad inversa (Jack DC)
```
JACK DC (+) ──►│──► Vin_net
         D1 (1N5819)
JACK DC (-) ──────► GND

Si Vin inverso: D1 bloqueado → 0V en circuito → Sin daño
Caída: Vf ≈ 0.3V (Schottky) vs 0.7V (Si)
```

### 2. ORing USB / Jack DC
```
JACK DC (+) ──►│──┐
         D1     │
               ├──► Vin_net → LM7805 IN
USB 5V (+) ──►│──┘
         D2 (1N5819)

Comportamiento:
- Solo Jack (9-12V): D1 ON, D2 OFF (5V USB < Vin - Vf)
- Solo USB (5V): D2 ON, D1 OFF (Jack = 0V)
- Ambos: El de mayor voltaje gana (típicamente Jack)
```

### 3. Diodo descarga capacitor salida (LM7805)
```
LM7805 OUT ──►│──► LM7805 IN
         D3 (1N5819)

Al apagar Vin:
- C_OUT (100µF) se descarga por D3 hacia IN
- Evita que V_OUT > V_IN + Vf (daña regulador)
- Crítico si C_OUT grande y carga inductiva
```

---

## Protecciones NO implementadas (planificadas v0.5+)

| Protección | Componente sugerido | Ubicación | Prioridad |
|---|---|---|---|
| **PTC Resettable Fuse** | 500mA-1A (0805/1206) | Serie Vin | Alta |
| **TVS Diode** | SMAJ12A / SMAJ5.0A | Entrada Vin / +5V Rail | Alta |
| **Power Good LED** | AND lógico (5V && 3.3V) | Indicador visual | Media |
| **Current Sense Jumper** | 0Ω / Header 2p | Serie +5V, +3.3V | Media |
| **Reverse USB** | MOSFET ideal diode | Entrada USB | Baja |

### PTC Fuse (Polyswitch) - Recomendado
```
Vin ──► [PTC 1A] ──► LM7805 IN

Ejemplos:
- 0.5A hold / 1A trip: 0ZCG0050FF2C (1206)
- 1A hold / 2A trip: 0ZCG0100FF2C (1206)
- 1.5A hold / 3A trip: 0ZCG0150FF2C (1206)

Auto-rearme tras enfriar. Sin reemplazar fusible.
```

### TVS Diode (Protección transitorios/ESD)
```
Entrada Jack:
Vin ──►┬──► LM7805 IN
       │
      TVS (SMAJ12A para 12V max, o SMAJ5.0A para 5V USB)
       │
      GND

Rail +5V:
+5V ──►┬──► Carga
       │
      TVS (SMAJ5.0A o SMAJ6.0A)
       │
      GND

Especificaciones TVS:
- VRWM (Stand-off): ≥ Voltaje nominal rail
- VBR (Breakdown): VRWM × 1.1-1.2
- Vc (Clamping): < 2× VRWM
- Ppk (Pico potencia): ≥ 400W (SMA) / 600W (SMB)
```

---

## Análisis fallos (FMEA)

| Modo fallo | Causa | Efecto | Detección | Mitigación actual | Mejora |
|---|---|---|---|---|---|
| Vin polaridad inversa | Usuario error | Quema LM7805, MCU | D1 bloquea | 1N5819 Serie | ✅ OK |
| USB backfeed a Jack | PC conectada + Jack | Daña fuente Jack | D2 bloquea | 1N5819 ORing | ✅ OK |
| C_OUT descarga en LM7805 | Apagado brusco | Daña regulador | D3 descarga | 1N5819 OUT→IN | ✅ OK |
| Sobrecorriente +5V | Cortocircuito carga | Caída voltaje, calor | Térmica LM7805 | Interno 150°C | ⚠️ Lento |
| Pico corriente motor | Arranque motor | Brownout ESP32 | Monitor A9013 | Cap 100µF + 100nF | ⚠️ Margen |
| ESD conector usuario | Manipulación | Daña GPIO/ESD | Ninguna | Diodos internos ESP32 | ❌ Falta TVS |
| Sobretensión Vin | Fuente errónea | Quema LM7805 | Ninguna | Ninguna | ❌ Falta TVS |

---

## Mejoras v0.5 planificadas

```mermaid
graph LR
    A[Jack DC] --> B[TVS SMAJ12A]
    B --> C[PTC 1.5A]
    C --> D[D1 1N5819]
    D --> E[LM7805]
    E --> F[+5V Rail]
    F --> G[TVS SMAJ5.0A]
    F --> H[MX1508]
    F --> I[Servo]
    F --> J[Terminal Block]
    E --> K[D3 1N5819]
    K --> C
    USB_5V --> L[D2 1N5819]
    L --> C
    
    F --> M[+5V Monitor LED + AND Gate]
    GND --> N[GND Monitor]
    M & N --> O[PG LED Verde]
```

---

## Testing protecciones

### Test polaridad inversa
```bash
# 1. Conectar Jack con polaridad inversa (centro negativo)
# 2. Medir Vin_net → Debe ser 0V
# 3. Verificar LM7805 no calienta
# 4. Reconectar correcto → Funciona normal
```

### Test ORing
```bash
# 1. Solo Jack 9V → +5V Rail = 5V ✓
# 2. Solo USB → +5V Rail = ~4.7V (drop D2) ✓
# 3. Jack 9V + USB → +5V Rail = 5V (Jack gana) ✓
# 4. Desconectar Jack → Transición suave a USB ✓
```

### Test térmico LM7805
```bash
# 1. Cargar +5V Rail con 1A (resistencia 5Ω 5W)
# 2. Medir temp LM7805 (termocupla o IR)
# 3. Debe estabilizarse < 100°C con disipador PCB
# 4. Sin disipador → Apagado térmico ~2-3 min
```

### Test brownout motor
```cpp
void testMotorBrownout() {
  float v5v_before = readV5V();  // Divisor tensión + ADC
  motorA(255);  // Full PWM
  delay(100);
  float v5v_during = readV5V();
  motorA(0);
  
  Serial.printf("5V: %.2fV → %.2fV (drop %.2fV)\n", 
                v5v_before, v5v_during, v5v_before - v5v_during);
  // Drop > 0.3V = riesgo brownout ESP32
}
```

---

## Referencias

- [1N5819 Datasheet](https://www.onsemi.com/pdf/datasheet/1n5819-d.pdf)
- [LM7805 Thermal Design](https://www.ti.com/lit/an/slva118/slva118.pdf)
- [TVS Diode Selection Guide](https://www.littelfuse.com/~/media/electronics/datasheets/tvs_diode_arrays/littelfuse_tvs_selection_guide.pdf)
- [PTC Resettable Fuses](https://www.littelfuse.com/products/circuit-protection/ptc-resettable-fuses.aspx)

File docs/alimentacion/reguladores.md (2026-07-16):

# Reguladores de voltaje

## LM7805CT - Regulador 5V

### Datos técnicos

| Parámetro | Valor |
|---|---|
| **Tipo** | Regulador lineal positivo (LDO no) |
| **Voltaje salida** | 5.0V fijo |
| **Corriente máxima** | 1.5A |
| **Voltaje entrada** | 7-35V (recomendado 7-12V) |
| **Dropout voltage** | ~2.0V @ 1A |
| **Regulación línea** | 10mV típico |
| **Regulación carga** | 50mV típico |
| **Corriente quiescente** | 4-8mA |
| **Protecciones** | Térmica, cortocircuito, SOA |
| **Encapsulado** | TO-220-3 (vertical) |
| **Temperatura** | 0-125°C (junction) |

### Circuito en la Base ESP32

```
           ┌──────────────┐
VIN (7-12V)─►│ IN     OUT │──► +5V Rail
           │  LM7805CT   │
           │     GND     │
           └──────┬──────┘
                  │
                  ▼
              GND Plane
```

**Componentes asociados:**
- **C_IN1**: 470µF 25V Electrolítico (bulk, cerca pin IN)
- **C_IN2**: 100nF 0805 Cerámico (decoupling HF, pegado a pin IN)
- **C_OUT1**: 100µF 10V Electrolítico (bulk, cerca pin OUT)
- **C_OUT2**: 100nF 0805 Cerámico (decoupling HF, pegado a pin OUT)
- **D_PROT**: 1N5819 Schottky (pin OUT → IN, protección descarga C_OUT)
- **LED_5V**: LED 3mm Rojo + 1kΩ (indicador visual)

### Disipación térmica

**Cálculo potencia disipada:**
```
P_D = (V_IN - V_OUT) × I_OUT + V_IN × I_Q
```

| Escenario | V_IN | I_OUT | P_D | ΔT (θ_JA=25°C/W) |
|---|---|---|-----|---|
| **Typical** | 9V | 300mA | 1.2W | 30°C |
| **Worst case** | 12V | 800mA | 5.6W | 140°C ❌ |
| **USB only** | 5V | 500mA | 0W (dropout) | - |

**Soluciones implementadas:**
1. **4 vias térmicas** bajo pad GND del TO-220 → GND pour bottom
2. **Copper pour** +5V en top layer actúa como heatsink lateral
3. **Recomendación**: Vin ≤ 9V para uso continuo, disipador externo si >500mA sostenido

### Selección de capacitores

| Posición | Valor | Tipo | Por qué |
|---|---|---|---|
| Input Bulk | 470µF | Electrolítico 25V | Reservorio energía, ripple bajo |
| Input HF | 100nF | X7R 0805 25V | Filtro ruido alta frecuencia |
| Output Bulk | 100µF | Electrolítico 10V | Estabilidad, respuesta transitoria |
| Output HF | 100nF | X7R 0805 10V | Ruido switching, ESP32 TX bursts |

> **Nota**: LM7805 requiere capacitor salida ≥ 0.1µF para estabilidad. 100µF + 100nF da margen amplio.

---

## AMS1117-3.3 - Regulador 3.3V

### Datos técnicos

| Parámetro | Valor |
|---|---|
| **Tipo** | Regulador lineal LDO (Low Dropout) |
| **Voltaje salida** | 3.3V fijo (versión adjustable existe) |
| **Corriente máxima** | 800mA (1A peak) |
| **Voltaje entrada** | 3.8-12V (max 15V) |
| **Dropout voltage** | 1.1V típico @ 800mA |
| **Regulación línea** | 0.2% típico |
| **Regulación carga** | 0.4% típico |
| **Corriente quiescente** | 5mA típico |
| **Protecciones** | Térmica, current limit |
| **Encapsulado** | SOT-223-4 (Tab = GND) |
| **Temperatura** | -40 a +125°C |

### Circuito en la Base ESP32

```
       +5V Rail ──►│ IN    OUT │──► +3.3V Rail
                   │ AMS1117  │
                   │  GND TAB │
                   └────┬─────┘
                        │
                        ▼
                    GND Plane (tab soldered)
```

**Componentes asociados:**
- **C_IN**: 10µF 0805 + 100nF 0805 (cerca pin IN)
- **C_OUT**: 100µF 6.3V Electrolítico + 100nF 0805 (cerca pin OUT)
- **LED_3V3**: LED 3mm Verde + 1kΩ

### Disipación térmica

| Escenario | V_IN | I_OUT | P_D | ΔT (θ_JA=40°C/W) |
|---|---|---|-----|---|
| **Typical** | 5V | 200mA | 0.34W | 14°C ✅ |
| **WiFi TX** | 5V | 500mA | 0.85W | 34°C ✅ |
| **Max** | 5V | 800mA | 1.36W | 54°C ⚠️ |

**Gestión térmica SOT-223:**
- **Tab (pin 2)** = GND, soldado a **GND pour** top + bottom
- **4 vias térmicas** bajo tab → GND plane bottom
- Copper pour +3.3V en top actúa como spreader lateral
- Suficiente para 500mA continuo sin heatsink externo

### ¿Por qué AMS1117 y no otro LDO?

| LDO | I_max | Dropout @500mA | Costo | Disponibilidad |
|-----|---|---|---|---|
| **AMS1117-3.3** | 800mA | 1.1V | $0.15 | Muy alta (LCSC/JLC) |
| LM1117-3.3 | 800mA | 1.2V | $0.20 | Alta |
| MCP1700-3.3 | 250mA | 1.7V | $0.30 | Media |
| AP2112-3.3 | 600mA | 0.9V | $0.25 | Media |
| TPS7A47 | 1A | 0.3V | $1.50 | Baja |

**Ganador**: AMS1117 por relación costo/rendimiento/disponibilidad en fabricantes chinos.

---

## Comparativa y selección

```
                    LM7805 (5V)          AMS1117 (3.3V)
                    ┌─────────────┐      ┌─────────────┐
Topología           │ Lineal std  │      │ LDO         │
Dropout             │ ~2V         │      │ ~1.1V       │
Eficiencia @9V→5V   │ 55%         │      │ N/A         │
Eficiencia @5V→3.3V │ N/A         │      │ 66%         │
Corriente max       │ 1.5A        │      │ 800mA       │
Costo unitario      │ $0.10       │      │ $0.15       │
Encapsulado         │ TO-220 THT  │      │ SOT-223 SMD │
Disipación          │ Fácil (THT) │      │ Requiere PCB│
Ruido salida        │ Bajo        │      │ Muy bajo    │
```

## Datasheets

- [LM7805 Datasheet (TI)](https://www.ti.com/lit/ds/symlink/lm7805.pdf)
- [AMS1117 Datasheet (Advanced Monolithic)](https://www.diodes.com/assets/Datasheets/AMS1117.pdf)
- [MX1508 Datasheet](../datasheets/MX1515H_C5119046.pdf)

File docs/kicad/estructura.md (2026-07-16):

# KiCad - Estructura del proyecto

## Archivos principales

```
base_esp32/
├── base_esp32.kicad_pro      # Configuración proyecto
├── base_esp32.kicad_sch      # Esquemático
├── base_esp32.kicad_pcb      # PCB Layout
├── base_esp32.kicad_prl      # Reglas locales (DRC)
├── sym-lib-table             # Tabla librerías símbolos
├── fp-lib-table              # Tabla librerías footprints
├── fp-info-cache             # Cache footprints (auto)
├── ESP32_devkit_v1.bak       # Backup librería símbolos
├── ESP32_devkit_v1.kicad_sym # Librería símbolos ESP32
├── MX1508.kicad_sym          # Símbolo MX1508
├── MX1508.kicad_mod          # Footprint MX1508
└── logo_footprint/           # Footprints branding
    ├── logo_x.kicad_mod
    └── qr.kicad_mod
```

---

## `base_esp32.kicad_pro` (Configuración)

```json
{
  "board": {
    "design_settings": {
      "defaults": {
        "board_outline_line_width": 0.15,
        "copper_line_width": 0.2,
        "copper_text_size": 1.5,
        "copper_text_thickness": 0.3,
        "courtyard_line_width": 0.05,
        "dimension_precision": 4,
        "dimension_units": 3,
        "edge_cut_line_width": 0.15,
        "fabrication_line_width": 0.15,
        "fabrication_text_size": 1,
        "fabrication_text_thickness": 0.15,
        "other_line_width": 0.15,
        "other_text_size": 1,
        "other_text_thickness": 0.15,
        "pads_to_mask_clearance": 0.051,
        "pcb_text_size": 1.5,
        "pcb_text_thickness": 0.3,
        "silk_line_width": 0.15,
        "silk_text_size": 1,
        "silk_text_thickness": 0.15,
        "solder_mask_clearance": 0.051,
        "solder_mask_min_width": 0.25,
        "zone_45_only": false,
        "zone_clearance": 0.508,
        "zone_line_width": 0.15
      },
      "diff_pair_dimensions": [],
      "drc_exclusions": [],
      "net_classes": [
        {"name": "Default", "bus_width": 12, "clearance": 0.15, "diff_pair_gap": 0.25, "diff_pair_via_gap": 0.25, "diff_pair_width": 0.2, "line_style": 0, "microvia_diameter": 0.3, "microvia_drill": 0.15, "pcb_color": "rgba(0, 0, 0, 0.000)", "schematic_color": "rgba(0, 0, 0, 0.000)", "track_width": 0.2, "via_diameter": 0.6, "via_drill": 0.3, "wire_width": 0.2},
        {"name": "Power_5V", "bus_width": 12, "clearance": 0.2, "diff_pair_gap": 0.25, "diff_pair_via_gap": 0.25, "diff_pair_width": 0.2, "line_style": 0, "microvia_diameter": 0.3, "microvia_drill": 0.15, "pcb_color": "rgba(255, 0, 0, 0.000)", "schematic_color": "rgba(255, 0, 0, 0.000)", "track_width": 0.5, "via_diameter": 1.0, "via_drill": 0.5, "wire_width": 0.2},
        {"name": "Power_3V3", "bus_width": 12, "clearance": 0.2, "diff_pair_gap": 0.25, "diff_pair_via_gap": 0.25, "diff_pair_width": 0.2, "line_style": 0, "microvia_diameter": 0.3, "microvia_drill": 0.15, "pcb_color": "rgba(0, 255, 0, 0.000)", "schematic_color": "rgba(0, 255, 0, 0.000)", "track_width": 0.4, "via_diameter": 1.0, "via_drill": 0.5, "wire_width": 0.2},
        {"name": "Motor_Power", "bus_width": 12, "clearance": 0.3, "diff_pair_gap": 0.25, "diff_pair_via_gap": 0.25, "diff_pair_width": 0.2, "line_style": 0, "microvia_diameter": 0.3, "microvia_drill": 0.15, "pcb_color": "rgba(255, 128, 0, 0.000)", "schematic_color": "rgba(255, 128, 0, 0.000)", "track_width": 1.0, "via_diameter": 1.0, "via_drill": 0.5, "wire_width": 0.2}
      ],
      "rule_area": 100000000,
      "rule_severity": {
        "clearance": "error",
        "copper_edge_clearance": "error",
        "courtyards_overlap": "warning",
        "diff_pair_gap_out_of_range": "error",
        "diff_pair_unbalanced_length": "error",
        "drill_out_of_range": "error",
        "duplicate_footprints": "warning",
        "extra_footprint": "warning",
        "footprint_courtyard_overlap": "warning",
        "footprint_type_mismatch": "warning",
        "hole_clearance": "error",
        "hole_near_hole": "error",
        "invalid_outline": "error",
        "item_on_disabled_layer": "error",
        "items_not_allowed": "error",
        "length_out_of_range": "error",
        "malformed_courtyard": "error",
        "microvia_drill_out_of_range": "error",
        "missing_courtyard": "ignore",
        "missing_footprint": "error",
        "net_conflict": "error",
        "no_connect_connected": "warning",
        "npth_inside_courtyard": "warning",
        "padstack_zero_drill": "error",
        "silkscreen_over_copper": "warning",
        "skew_out_of_range": "error",
        "through_hole_pad_without_hole": "error",
        "too_many_vias": "warning",
        "track_width": "error",
        "unconnected_items": "error",
        "unresolved_variable": "error",
        "via_dangling": "warning",
        "zone_has_no_outline": "warning"
      },
      "technology": 0,
      "track_widths": [0.2, 0.25, 0.3, 0.4, 0.5, 0.6, 0.8, 1.0, 1.2, 1.5, 2.0],
      "via_diameters": [0.6, 0.8, 1.0, 1.2, 1.5],
      "via_drills": [0.3, 0.4, 0.5, 0.6],
      "zone_clearances": [0.508, 0.254, 0.2, 0.15]
    },
    "layer_presets": [],
    "layers": {
      "0": {"name": "F.Cu", "type": 0, "visible": true},
      "31": {"name": "B.Cu", "type": 0, "visible": true},
      "32": {"name": "B.Adhes", "type": 1, "visible": false},
      "33": {"name": "F.Adhes", "type": 1, "visible": false},
      "34": {"name": "B.Paste", "type": 2, "visible": true},
      "35": {"name": "F.Paste", "type": 2, "visible": true},
      "36": {"name": "B.SilkS", "type": 3, "visible": true},
      "37": {"name": "F.SilkS", "type": 3, "visible": true},
      "38": {"name": "B.Mask", "type": 4, "visible": true},
      "39": {"name": "F.Mask", "type": 4, "visible": true},
      "40": {"name": "Dwgs.User", "type": 5, "visible": true},
      "41": {"name": "Cmts.User", "type": 5, "visible": true},
      "42": {"name": "Eco1.User", "type": 5, "visible": false},
      "43": {"name": "Eco2.User", "type": 5, "visible": false},
      "44": {"name": "Edge.Cuts", "type": 6, "visible": true},
      "45": {"name": "Margin", "type": 7, "visible": false},
      "46": {"name": "B.CrtYd", "type": 8, "visible": false},
      "47": {"name": "F.CrtYd", "type": 8, "visible": false},
      "48": {"name": "B.Fab", "type": 9, "visible": false},
      "49": {"name": "F.Fab", "type": 9, "visible": false},
      "50": {"name": "In1.Cu", "type": 0, "visible": false},
      "51": {"name": "In2.Cu", "type": 0, "visible": false}
    },
    "physical_stackup": {
      "copper_finish": "HASL",
      "copper_finishes": ["HASL", "ENIG", "OSP", "Immersion Tin", "Immersion Silver"],
      "dielectric_constraints": [],
      "board_thickness": 1.6,
      "board_thicknesses": [0.8, 1.0, 1.2, 1.6, 2.0, 2.4],
      "copper_thickness": 35,
      "copper_thicknesses": [17, 35, 70, 105],
      "material": "FR4",
      "materials": ["FR4", "FR4 High Tg", "Rogers", "Aluminum"],
      "solder_mask": "Green",
      "solder_masks": ["Green", "Red", "Blue", "Black", "White", "Yellow", "Matte Green", "Matte Black"],
      "silkscreen": "White",
      "silkscreens": ["White", "Black", "Yellow"],
      "finished_copper_thickness": 42,
      "finished_copper_thicknesses": [35, 42, 70, 105],
      "prepreg_thicknesses": [],
      "core_thicknesses": []
    }
  },
  "libraries": {
    "symbol_lib_table": [],
    "footprint_lib_table": []
  },
  "metadata": {
    "version": 1,
    "generator": "KiCad Schematic Editor",
    "generator_version": "9.0"
  },
  "project": {
    "files": [],
    "meta": {
      "filename": "base_esp32.kicad_pro",
      "version": 1
    },
    "name": "base_esp32"
  },
  "schematic": {
    "annotation": {
      "annotate_start_num": 1,
      "direction": 0,
      "hierarchical_prefix_separator": "/",
      "hierarchical_sheet_prefix": "1",
      "use_hierarchical_reference": true
    },
    "drawing": {
      "default_text_size": 1.27,
      "inter_sheet_ref_prefix": "#",
      "inter_sheet_ref_suffix": "",
      "inter_sheet_ref_size": 1.27,
      "label_size_ratio": 0.375,
      "pin_symbol_size": 1.27,
      "text_offset": 0.0
    },
    "legacy_lib_order": false,
    "net_name_format": "",
    "ngspice": {
      "fix_sim_value": false,
      "model_mode": 1,
      "use_ngspice": false
    },
    "page_settings": [
      {"page": "1", "width": 297, "height": 210, "left_margin": 20, "right_margin": 10, "top_margin": 10, "bottom_margin": 10, "orientation": "L"}
    ],
    "text_variables": {}
  }
}
```

---

## `sym-lib-table` (Librerías símbolos)

```
(sym_lib_table
  (lib (name "project_symbols") (type "KiCad") (uri "${KIPRJMOD}/ESP32-DevKitC.kicad_sym") (options "") (descr "Project symbols"))
  (lib (name "MX1508") (type "KiCad") (uri "${KIPRJMOD}/MX1508.kicad_sym") (options "") (descr "MX1508 Motor Driver"))
  (lib (name "power") (type "KiCad") (uri "${KICAD_SYMBOL_DIR}/power.kicad_sym") (options "") (descr "Power symbols"))
  (lib (name "Device") (type "KiCad") (uri "${KICAD_SYMBOL_DIR}/Device.kicad_sym") (options "") (descr "Passive devices"))
  (lib (name "Connector") (type "KiCad") (uri "${KICAD_SYMBOL_DIR}/Connector.kicad_sym") (options "") (descr "Connectors"))
  (lib (name "Regulator") (type "KiCad") (uri "${KICAD_SYMBOL_DIR}/Regulator.kicad_sym") (options "") (descr "Voltage regulators"))
  (lib (name "Sensor") (type "KiCad") (uri "${KICAD_SYMBOL_DIR}/Sensor.kicad_sym") (options "") (descr "Sensors"))
  (lib (name "Switch") (type "KiCad") (uri "${KICAD_SYMBOL_DIR}/Switch.kicad_sym") (options "") (descr "Switches"))
  (lib (name "LED") (type "KiCad") (uri "${KICAD_SYMBOL_DIR}/LED.kicad_sym") (options "") (descr "LEDs"))
  (lib (name "Buzzer") (type "KiCad") (uri "${KICAD_SYMBOL_DIR}/Buzzer.kicad_sym") (options "") (descr "Buzzers"))
  (lib (name "Motor") (type "KiCad") (uri "${KICAD_SYMBOL_DIR}/Motor.kicad_sym") (options "") (descr "Motor drivers"))
  (lib (name "MCU_ESP32") (type "KiCad") (uri "${KICAD_SYMBOL_DIR}/MCU_ESP32.kicad_sym") (options "") (descr "ESP32 MCU"))
  (lib (name "Interface_USB") (type "KiCad") (uri "${KICAD_SYMBOL_DIR}/Interface_USB.kicad_sym") (options "") (descr "USB interfaces"))
  (lib (name "Amplifier") (type "KiCad") (uri "${KICAD_SYMBOL_DIR}/Amplifier.kicad_sym") (options "") (descr "Amplifiers"))
  (lib (name "Opto") (type "KiCad") (uri "${KICAD_SYMBOL_DIR}/Opto.kicad_sym") (options "") (descr "Optocouplers"))
  (lib (name "Transistor") (type "KiCad") (uri "${KICAD_SYMBOL_DIR}/Transistor.kicad_sym") (options "") (descr "Transistors"))
  (lib (name "Diode") (type "KiCad") (uri "${KICAD_SYMBOL_DIR}/Diode.kicad_sym") (options "") (descr "Diodes"))
  (lib (name "Crystal") (type "KiCad") (uri "${KICAD_SYMBOL_DIR}/Crystal.kicad_sym") (options "") (descr "Crystals"))
```

---

## `fp-lib-table` (Librerías footprints)

```
(fp_lib_table
  (lib (name "project_footprints") (type "KiCad") (uri "${KIPRJMOD}/my_symbols.pretty") (options "") (descr "Project footprints"))
  (lib (name "logo_footprint") (type "KiCad") (uri "${KIPRJMOD}/logo_footprint") (options "") (descr "Logo and QR footprints"))
  (lib (name "Connector") (type "KiCad") (uri "${KICAD_FOOTPRINT_DIR}/Connector.pretty") (options "") (descr "Connectors"))
  (lib (name "Package_TO_SOT_THT") (type "KiCad") (uri "${KICAD_FOOTPRINT_DIR}/Package_TO_SOT_THT.pretty") (options "") (descr "TO/SOT THT"))
  (lib (name "Package_TO_SOT_SMD") (type "KiCad") (uri "${KICAD_FOOTPRINT_DIR}/Package_TO_SOT_SMD.pretty") (options "") (descr "TO/SOT SMD"))
  (lib (name "Package_DIP") (type "KiCad") (uri "${KICAD_FOOTPRINT_DIR}/Package_DIP.pretty") (options "") (descr "DIP packages"))
  (lib (name "Package_SO") (type "KiCad") (uri "${KICAD_FOOTPRINT_DIR}/Package_SO.pretty") (options "") (descr "SO packages"))
  (lib (name "Package_QFP") (type "KiCad") (uri "${KICAD_FOOTPRINT_DIR}/Package_QFP.pretty") (options "") (descr "QFP packages"))
  (lib (name "Resistor_SMD") (type "KiCad") (uri "${KICAD_FOOTPRINT_DIR}/Resistor_SMD.pretty") (options "") (descr "SMD Resistors"))
  (lib (name "Resistor_THT") (type "KiCad") (uri "${KICAD_FOOTPRINT_DIR}/Resistor_THT.pretty") (options "") (descr "THT Resistors"))
  (lib (name "Capacitor_SMD") (type "KiCad") (uri "${KICAD_FOOTPRINT_DIR}/Capacitor_SMD.pretty") (options "") (descr "SMD Capacitors"))
  (lib (name "Capacitor_THT") (type "KiCad") (uri "${KICAD_FOOTPRINT_DIR}/Capacitor_THT.pretty") (options "") (descr "THT Capacitors"))
  (lib (name "LED_SMD") (type "KiCad") (uri "${KICAD_FOOTPRINT_DIR}/LED_SMD.pretty") (options "") (descr "SMD LEDs"))
  (lib (name "LED_THT") (type "KiCad") (uri "${KICAD_FOOTPRINT_DIR}/LED_THT.pretty") (options "") (descr "THT LEDs"))
  (lib (name "Diode_SMD") (type "KiCad") (uri "${KICAD_FOOTPRINT_DIR}/Diode_SMD.pretty") (options "") (descr "SMD Diodes"))
  (lib (name "Diode_THT") (type "KiCad") (uri "${KICAD_FOOTPRINT_DIR}/Diode_THT.pretty") (options "") (descr "THT Diodes"))
  (lib (name "Potentiometer") (type "KiCad") (uri "${KICAD_FOOTPRINT_DIR}/Potentiometer.pretty") (options "") (descr "Potentiometers"))
  (lib (name "Switch") (type "KiCad") (uri "${KICAD_FOOTPRINT_DIR}/Switch.pretty") (options "") (descr "Switches"))
  (lib (name "Buzzer") (type "KiCad") (uri "${KICAD_FOOTPRINT_DIR}/Buzzer.pretty") (options "") (descr "Buzzers"))
  (lib (name "Terminal_Block") (type "KiCad") (uri "${KICAD_FOOTPRINT_DIR}/Terminal_Block.pretty") (options "") (descr "Terminal blocks"))
  (lib (name "MountingHole") (type "KiCad") (uri "${KICAD_FOOTPRINT_DIR}/MountingHole.pretty") (options "") (descr "Mounting holes"))
  (lib (name "Mechanical") (type "KiCad") (uri "${KICAD_FOOTPRINT_DIR}/Mechanical.pretty") (options "") (descr "Mechanical"))
  (lib (name "TestPoint") (type "KiCad") (uri "${KICAD_FOOTPRINT_DIR}/TestPoint.pretty") (options "") (descr "Test points"))
  (lib (name "RF_Module") (type "KiCad") (uri "${KICAD_FOOTPRINT_DIR}/RF_Module.pretty") (options "") (descr "RF Modules"))
  (lib (name "Housings_DIP") (type "KiCad") (uri "${KICAD_FOOTPRINT_DIR}/Housings_DIP.pretty") (options "") (descr "DIP housings"))
```

---

## Hoja esquemática principal (Jerarquía)

```
base_esp32.kicad_sch
├── Portada (Title Block)
├── Main Sheet
│   ├── Power_Input (Jack DC, USB, ORing)
│   ├── Power_5V (LM7805)
│   ├── Power_3V3 (AMS1117)
│   ├── Power_Monitor (A9013)
│   ├── MCU_ESP32 (Socket 2x19)
│   ├── Motor_Driver (MX1508)
│   ├── Sensors (DS18B20, LM35, LDR)
│   ├── Actuators (Buzzer, LEDs, RGB, Servo)
│   ├── Inputs (DIP, Push, SPDT, Pot)
│   ├── Connectors (Headers, Term Block, Servo)
│   └── Mounting (4x M3)
```

---

## Net naming convention

| Patrón | Ejemplo | Uso |
|---|---|-----|
| `+5V` | `+5V` | Rail potencia 5V |
| `+3V3` | `+3V3` | Rail potencia 3.3V |
| `GND` | `GND` | Tierra |
| `GPIO<num>` | `GPIO12` | Pines GPIO directos |
| `<FUNC>_<num>` | `MOT_A_IN1` | Función específica |
| `ADC<num>` | `ADC1_CH0` | Canales ADC |
| `I2C_<SIG>` | `I2C_SDA` | Bus I2C |
| `SPI_<SIG>` | `SPI_MOSI` | Bus SPI |
| `UART_<SIG>` | `UART_TX` | Bus UART |

---

## Versionado KiCad

| Archivo | Formato | Compatibilidad |
|---|---|---|
| `.kicad_pro` | JSON | KiCad 7+ |
| `.kicad_sch` | S-expr | KiCad 6+ |
| `.kicad_pcb` | S-expr | KiCad 6+ |
| `.kicad_sym` | S-expr | KiCad 6+ |
| `.kicad_mod` | S-expr | KiCad 6+ |

> **Nota**: KiCad 9 (2024) usa mismo formato. Compatible hacia adelante.

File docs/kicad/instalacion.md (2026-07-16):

# KiCad - Instalación y configuración

## Instalación

### Windows
```bash
# Chocolatey
choco install kicad

# O instalador oficial
# https://kicad.org/download/windows/
```

### Linux (Ubuntu/Debian)
```bash
# PPA oficial (versión estable)
sudo add-apt-repository ppa:kicad/kicad-8.0-releases
sudo apt update
sudo apt install kicad

# Flatpak (última versión)
flatpak install flathub org.kicad.KiCad
```

### macOS
```bash
# Homebrew
brew install --cask kicad

# O descargar .dmg desde kicad.org
```

### Verificar versión
```bash
kicad --version
# Requerido: 8.0+ (para este proyecto)
# Recomendado: 9.0 (actual estable 2024)
```

---

## Estructura del proyecto KiCad

```
base_esp32/
├── base_esp32.kicad_pro        # Configuración proyecto
├── base_esp32.kicad_sch        # Esquemático
├── base_esp32.kicad_pcb        # PCB Layout
├── base_esp32.kicad_prl        # Reglas locales (DRC, net classes)
├── sym-lib-table               # Tabla librerías símbolos (global)
├── fp-lib-table                # Tabla librerías footprints (global)
├── ESP32_devkit_v1.kicad_sym   # Símbolo custom ESP32 DevKit
├── MX1508.kicad_sym            # Símbolo custom MX1508
├── logo_x.kicad_mod            # Footprint logo Xizuth
├── qr.kicad_mod                # Footprint QR code
└── my_symbols.pretty/          # Librería footprints local
```

---

## Abrir proyecto

1. **KiCad → File → Open Project** → `base_esp32.kicad_pro`
2. Se abren: **Project Manager**, **Schematic Editor**, **PCB Editor**

### Ventanas principales
| Editor | Atajo | Uso |
|---|---|-----|
| Schematic | `Ctrl+E` | Esquemático |
| PCB | `Ctrl+P` | Layout PCB |
| Symbol Editor | - | Crear/editar símbolos |
| Footprint Editor | - | Crear/editar footprints |
| 3D Viewer | `Alt+3` | Vista 3D PCB |

---

## Librerías personalizadas

### Símbolos (`.kicad_sym`)

**ESP32-DevKitC-V4** (`assets/ESP32-DEVKIT-V1/ESP32-DevKitC.kicad_sym`):
- 38 pines (2×19)
- Unidades separadas: Power, GPIO, ADC, Comm, Strapping
- Campos: Reference, Value, Footprint, Datasheet, ki_keywords

**MX1508** (`MX1508.kicad_sym`):
- 8 pines SOP-8
- Unidades: Power, Logic, H-Bridge A, H-Bridge B
- Pin thermal pad marcado

### Footprints (`.kicad_mod`)

**Logo Xizuth** (`logo_footprint/logo_x.kicad_mod`):
- Gráficos vectoriales en silkscreen
- Posición: Esquina PCB

**QR Code** (`logo_footprint/qr.kicad_mod`):
- Enlaza a GitHub repo
- Generado: `qrencode -o qr.svg "https://github.com/Xizuth/base_esp32"`

### Añadir al proyecto
```
Preferences → Manage Symbol Libraries → Project Specific Libraries → +
  → Nickname: "project_symbols" → Path: "${KIPRJMOD}/ESP32-DevKitC.kicad_sym"

Preferences → Manage Footprint Libraries → Project Specific Libraries → +
  → Nickname: "project_footprints" → Path: "${KIPRJMOD}/my_symbols.pretty"
```

---

## Modificar el diseño

### 1. Cambiar componente (ej. Driver motor)

**Esquemático:**
1. Abrir `base_esp32.kicad_sch`
2. Seleccionar `U_MOT` (MX1508) → `Delete`
3. `A` (Add Symbol) → Buscar "L293D" o nuevo driver
4. Colocar → Conectar pines (wires `W`)
5. Anotar: `Tools → Annotation → Annotate Schematic`

**PCB:**
1. Abrir `base_esp32.kicad_pcb`
2. `Tools → Update PCB from Schematic` (`F8`)
   - ✓ Re-link footprints to schematic symbols
   - ✓ Update net classes
   - ✓ Delete footprints with no symbols
3. Nuevo footprint aparece en "Unplaced" → Colocar → Routear

### 2. Añadir conector (ej. Qwiic I2C)

**Esquemático:**
1. `A` → "Connector:Conn_01x04" → Colocar cerca I2C
2. Conectar: SDA→GPIO21, SCL→GPIO19, 3.3V, GND
3. Valor: "QWIIC" → Referencia: "J_QWIIC"

**PCB:**
1. `F8` → Update PCB
2. Footerprint: "Connector_PinHeader_2.54mm:PinHeader_1x04_P2.54mm_Vertical"
3. Colocar borde PCB → Routear pistas 0.2mm

### 3. Cambiar regulador (ej. AMS1117 → LM1117)

**Esquemático:**
1. Cambiar Value: "AMS1117" → "LM1117-3.3"
2. Verificar footprint compatible (SOT-223)
3. Si distinto: `E` (Properties) → Footprint → Seleccionar correcto

**PCB:**
1. `F8` → Update
2. Si footprint cambió: `Delete` viejo → Colocar nuevo → Routear

---

## Reglas de diseño (Design Rules)

### Net Classes (Clases de red)
```
Design Rules → Net Classes:
  Default:        Clearance 0.15mm, Track 0.2mm, Via 0.3/0.6mm
  Power_5V:       Clearance 0.2mm,  Track 0.5mm,  Via 0.5/1.0mm
  Power_3V3:      Clearance 0.2mm,  Track 0.4mm,  Via 0.5/1.0mm
  Motor_Power:    Clearance 0.3mm,  Track 1.0mm,  Via 0.5/1.0mm
  High_Speed:     Clearance 0.2mm,  Track 0.2mm,  Via 0.3/0.6mm, Diff 100Ω
```

### Reglas personalizadas (`.kicad_prl`)
- Via sizes por net class
- Track widths por net class
- Clearances custom (ej. HV > 2mm)
- Min annular ring, min microvia

---

## DRC (Design Rule Check)

```bash
# En PCB Editor:
Inspect → Design Rule Checker → Run DRC

# Errores típicos a cero:
✓ Clearance violations: 0
✓ Track width violations: 0
✓ Via size violations: 0
✓ Annular ring violations: 0
✓ Unconnected items: 0 (except mounting holes)
✓ Footprint courtyard overlaps: 0
✓ Silkscreen over pads: 0
✓ Edge cuts: 1 closed contour
```

---

## Generar archivos fabricación

### Gerbers
```
File → Fabrication Outputs → Gerbers (.gbr)
  Layers:
    ☑ F.Cu, B.Cu
    ☑ F.SilkS, B.SilkS
    ☑ F.Mask, B.Mask
    ☑ F.Paste, B.Paste (para stencil)
    ☑ Edge.Cuts
  Options:
    ☑ Use Protel filename extensions
    ☑ Generate drill files (separate)
    ☑ Drill origin: Absolute
    ☑ Drill units: Millimeters
    ☑ Drill format: Excellon (decimal)
  Output: gerber/
```

### Drill Files
```
Generate Drill Files:
  ☑ PTH (Plated)
  ☑ NPTH (Non-plated)
  Format: Excellon
  Units: Millimeters
  Zeros format: Decimal
  Map: Gerber + Drill map
```

### BOM
```
Tools → Generate BOM
  Plugin: bom_csv_grouped_by_value
  Output: fabricacion/bom.csv
```

### Pick & Place
```
File → Fabrication Outputs → Footprint Position (.csv)
  ☑ Only SMD
  ☑ Units: mm
  ☑ Format: JLCPCB / PCBWay
  Output: fabricacion/pnp.csv
```

### STEP 3D
```
File → Export → STEP
  ☑ Include: All layers
  ☑ Origin: PCB center
  Output: step/base_esp32.step
```

---

## Atajos útiles

| Acción | Esquemático | PCB |
|---|---|-----|
| Zoom fit | `Home` | `Home` |
| Zoom selection | `Ctrl+Home` | `Ctrl+Home` |
| Grid 0.1/0.5/1mm | `N` / `Shift+N` | `N` / `Shift+N` |
| Add wire | `W` | - |
| Add symbol | `A` | - |
| Add footprint | - | `O` (Footprint) |
| Route track | - | `X` |
| Via while routing | - | `V` |
| Switch layer | - | `PgUp`/`PgDn` |
| Flip selection | - | `F` |
| Rotate 90° | `R` | `R` |
| Move exactly | `Ctrl+M` | `Ctrl+M` |
| Duplicate | `Ctrl+D` | `Ctrl+D` |
| Delete | `Del` | `Del` |
| Undo/Redo | `Ctrl+Z`/`Ctrl+Y` | `Ctrl+Z`/`Ctrl+Y` |
| DRC | - | `F11` |
| Update PCB from Sch | - | `F8` |
| 3D Viewer | - | `Alt+3` |

---

## Buenas prácticas

1. **Commit menudo**: Cada cambio lógico = commit
2. **Net labels**: Usar labels jerárquicos (`GPIO12`, `+5V`, `I2C_SDA`)
3. **Net classes**: Asignar al crear nets nuevos
4. **Polygons**: `B` para regenerar GND pours tras cambios
5. **DRC frecuente**: Cada sesión de routing
6. **3D Viewer**: Verificar clearances mecánicos (connectors, tall components)
7. **Documentación**: Comentar cambios en `to_changes.md`

---

## Proyectos KiCad

### Configuración del proyecto ESP32

```
base_esp32/
├── base_esp32.kicad_pro        # Configuración proyecto
├── base_esp32.kicad_sch        # Esquemático
├── base_esp32.kicad_pcb        # PCB Layout
├── base_esp32.kicad_prl        # Reglas locales (DRC, net classes)
├── sym-lib-table               # Tabla librerías símbolos (global)
├── fp-lib-table                # Tabla librerías footprints (global)
├── ESP32_devkit_v1.kicad_sym   # Símbolo custom ESP32 DevKit
├── MX1508.kicad_sym            # Símbolo custom MX1508
├── logo_x.kicad_mod            # Footprint logo Xizuth
├── qr.kicad_mod                # Footprint QR code
└── my_symbols.pretty/          # Librería footprints local
```

### Configuración de librerías

**Biblioteca específica del proyecto (subdirectorio):**

```bash
mkdir -p kicad_libs/symbols
mkdir -p kicad_libs/footprints

# Añadir en KiCad
Preferences → Manage Symbol Libraries → + → Project Specific Libraries
  Nickname: "my_symbols"
  Path: "${KIPRJMOD}/kicad_libs/symbols"

Preferences → Manage Footprint Libraries → + → Project Specific Libraries
  Nickname: "my_footprints"
  Path: "${KIPRJMOD}/kicad_libs/footprints"
```

**Librería compartida (submódulo git):**

```bash
git submodule add https://github.com/tu-usuario/kicad-common-lib.git kicad_libs/project
```

### Archivos de configuración KiCad

| Archivo | Propósito |
|---|---|
| `kicad.rc` | Config global (colores, atajos) |
| `common.sch` | Símbolos compartidos entre esquemas |
| `common.fp` | Footprints compartidos |

---

## Atajos de teclado esenciales

| Acción | Atajo (Linux/Windows) | Atajo (macOS) |
|---|---|---|
| Nuevo esquema | `Ctrl+N` | `Cmd+N` |
| Abrir esquema | `Ctrl+O` | `Cmd+O` |
| Guardar | `Ctrl+S` | `Cmd+S` |
| Insertar símbolo | `A` (Add) | `A` (Add) |
| Rotar | `R` | `R` |
| Mover | `M` | `M` |
| Escalar | `S` | `S` |
| Eliminar | `Del` | `Del` |
| Conectar pistas | `X` (Track) | `X` (Track) |
| Añadir vía | `V` | `V` |
| Ajustar Board | `Ctrl+B` | `Cmd+B` |
| Design Rule Check | `Ctrl+Shift+C` | `Cmd+Shift+C` |
| 3D Viewer | `Alt+3` | `Ctrl+3` |

---

## Resolución de problemas

### Error: "Failed to load symbol file"
```bash
# Ajustar PATH usando variables de entorno
export KISYSMOD="${KIPRJMOD}/kicad_libs"
```

### Error: "Footprint not found"
```bash
# Repetir con los cuatro entresijos del haystack
 ls -la ${KIPRJMOD}/*

# Ejecutar "Update PCB from Schematic"
F8 → Update
castear
```

### Error: "Symbol library empty"
```bash
# Importar símbolos originales
Preferences → Manage Symbol Libraries → + → Archivo --> choose CSV/JSON
```

### Error: "La capa está bloqueada"
```bash
Design → Layer Settings → desbloquear F.SilkS, F.Cu
```

---

## Administración de librerías

### Exportar librerías del proyecto
```bash
#!/bin/bash

PROJECT_ROOT="/media/data/Projects/base_esp32"
BACKUP_DIR="${PROJECT_ROOT}/backups/kicad"
mkdir -p "${BACKUP_DIR}"

# Exportar símbolos
kicad-cli -p "${PROJECT_ROOT}/base_esp32.kicad_prj" -s "${PROJECT_ROOT}/kicad_libs/symbols" -e "${BACKUP_DIR}/symbols_${DATE}.lib"

# Exportar footprints
kicad-cli -p "${PROJECT_ROOT}/base_esp32.kicad_prj" -f "${PROJECT_ROOT}/kicad_libs/footprints" -e "${BACKUP_DIR}/footprints_${DATE}.mod"

# Exportar esquema y PCB en formato netlist
cd "${PROJECT_ROOT}"
/kicad-cli/sch_export -o "${BACKUP_DIR}/export_${DATE}.net" base_esp32
```

### Importar librerías a nuevo proyecto
```bash
#!/bin/bash

# Desde una librería compartida en otra máquina
cd nuevo_proyecto
cp "${SOURCE}/kicad_libs/symbols/*.sym" "${KIPRJMOD}/"
cp "${SOURCE}/kicad_libs/footprints/*.mod" "${KIPRJMOD}/"

# Actualizar KiCad
kicad --expert -p nuevo
```

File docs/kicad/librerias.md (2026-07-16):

# KiCad - Librerías personalizadas

## Librerías del proyecto

### 1. `ESP32-DevKitC.kicad_sym` - Símbolo ESP32 DevKit V4

**Ubicación:** `assets/ESP32-DEVKIT-V1/ESP32-DevKitC.kicad_sym`

**Estructura:**
```
ESP32-DevKitC (Root)
├── Unit A: Power (Pins 1-6, 25-28, 37-38)
│   VIN, 3V3, GND, EN, VP, VN
├── Unit B: GPIO 0-17
│   GPIO0-17 (Strapping notes)
├── Unit C: GPIO 18-39
│   GPIO18-39 (ADC, Touch, Input-only)
├── Unit D: ADC / Analog
│   ADC1_CH0-7, ADC2_CH0-9
├── Unit E: Communication
│   SPI, I2C, UART, I2S, SDIO
└── Unit F: Special / Strapping
    BOOT, Strapping pins highlighted
```

**Propiedades clave:**
- `Reference`: "U"
- `Value`: "ESP32-DevKitC-V4"
- `Footprint`: "ESP32-DevKitC:ESP32-DevKitC"
- `Datasheet`: "https://www.espressif.com/sites/default/files/documentation/esp32-wroom-32e_esp32-wrover-32e_datasheet_en.pdf"
- `ki_keywords`: "esp32 devkit wifi bluetooth mcu"
- `ki_fp_filters`: "ESP32*"

**Pines strapping marcados** (propiedad `Description`):
- GPIO0: "Boot mode select (LOW=Download)"
- GPIO2: "Boot mode (HIGH=SDIO), MTDI"
- GPIO12: "Flash voltage (LOW=3.3V, HIGH=1.8V)"
- GPIO15: "Boot logging (HIGH=Silent)"

---

### 2. `MX1508.kicad_sym` - Símbolo Driver Motor

**Ubicación:** `MX1508.kicad_sym`

**Unidades:**
```
Unit 1: Power
  VM (Pin 8) - Motor supply
  VCC (Pin 1) - Logic supply
  GND (Pin 4,5) - Ground (2 pines)

Unit 2: Channel A (H-Bridge 1)
  IN1 (Pin 2) - Input A1
  IN2 (Pin 3) - Input A2
  OUT1 (Pin 7) - Output A1
  OUT2 (Pin 6) - Output A2

Unit 3: Channel B (H-Bridge 2)
  IN3 (Pin 9) - Input B1
  IN4 (Pin 10) - Input B2
  OUT3 (Pin 13) - Output B1
  OUT4 (Pin 12) - Output B2

Unit 4: Thermal
  EPAD (Pad central) - Thermal pad (GND/VM)
```

**Footprint asignado:** `MX1508_SOP8` (custom)

---

### 3. `MX1508.kicad_mod` - Footprint MX1508

**Ubicación:** `MX1508.kicad_mod`

**Características:**
- SOP-8 estándar + pad térmico central expuesto
- Pads: 0.65mm pitch, 0.4×0.6mm
- Thermal pad: 3.2×2.2mm (centrado)
- Courtyard: 6.5×5.5mm
- 3D model: `mx1508.step` (opcional)

**Zona térmica PCB:**
```
En PCB: Polygon en F.Cu (VCC_MOTOR) + B.Cu (GND)
  Vías térmicas: 0.3mm drill, 0.6mm pad
  Grid: 1mm bajo pad térmico
  Conectado a: GND pour (Bottom) + VCC_MOTOR pour (Top)
```

---

### 4. `logo_x.kicad_mod` - Logo Xizuth

**Ubicación:** `logo_footprint/logo_x.kicad_mod`

**Contenido:**
- Gráficos vectoriales en `F.SilkS` (Top Silkscreen)
- Dimensiones: ~15×15mm
- Origen: Centro logo
- Layer: `F.SilkS` (visible en PCB)

**Uso:**
1. PCB Editor → `O` (Add Footprint) → "logo_x"
2. Colocar esquina PCB (ej. superior derecha)
3. `F` (Flip) si necesita en Bottom

---

### 5. `qr.kicad_mod` - QR Code GitHub

**Ubicación:** `logo_footprint/qr.kicad_mod`

**Generación:**
```bash
# Generar QR SVG
qrencode -o qr.svg -s 10 -l M "https://github.com/Xizuth/base_esp32"

# Convertir a footprint KiCad
# Opcional: Script python svg2mod.py
```

**Contenido:**
- Módulos en `F.SilkS` (puntos QR)
- Versión compacta 21×21 módulos
- Tamaño: ~10×10mm
- Quiet zone: 4 módulos

---

## Añadir librería al proyecto

### Símbolos (`.kicad_sym`)
```
Preferences → Manage Symbol Libraries
  → Project Specific Libraries tab
  → + (Add)
  → Nickname: "project_symbols"
  → Library Path: "${KIPRJMOD}/ESP32-DevKitC.kicad_sym"
  → Plugin: "KiCad"
  → OK
```

### Footprints (`.kicad_mod` en `.pretty`)
```
Preferences → Manage Footprint Libraries
  → Project Specific Libraries tab
  → + (Add)
  → Nickname: "project_footprints"
  → Library Path: "${KIPRJMOD}/my_symbols.pretty"
  → Plugin: "KiCad"
  → OK
```

> `${KIPRJMOD}` = variable = carpeta del proyecto `.kicad_pro`

---

## Crear nuevo símbolo

### Desde cero (Symbol Editor)
```
1. File → New Symbol Library → "my_lib.kicad_sym"
2. Create new symbol → Name: "Mi_IC"
3. Add pins (Pin tool `P`):
   - Number, Name, Type (Input/Output/Power/Passive)
   - Graphic style: Line/Inverted/Clock/Low level
4. Draw body (Rectangle `R`, Circle `C`, Arc `A`)
5. Add properties (Property tool `P`):
   Reference: "U"
   Value: "Mi_IC"
   Footprint: "Mi_IC_Footprint"
   Datasheet: "URL"
   ki_keywords: "palabras clave"
6. Save library → Add to project
```

### Desde datasheet (Import)
```
1. Symbol Editor → File → Import → "KiCad Symbol" / "Eagle" / "Altium"
2. Seleccionar archivo → Import
3. Revisar pines, asignar footprint
4. Guardar en librería proyecto
```

---

## Crear nuevo footprint

### Desde cero (Footprint Editor)
```
1. File → New Footprint Library → "my_lib.pretty"
2. New Footprint → Name: "Mi_Footprint"
3. Pads (Pad tool `P`):
   - SMD: Type SMD, Shape Rect/Round, Size X/Y
   - THT: Type Through-hole, Shape Circular/Oval, Drill size
   - Number: 1, 2, 3... (match symbol)
4. Courtyard (Draw → Polygon `Ctrl+Shift+P`):
   - Layer: F.CrtYd / B.CrtYd
   - Clearance IPC: 0.25mm (Nivel 1) / 0.5mm (Nivel 2)
5. Silkscreen (Layer F.SilkS):
   - Outline, Pin 1 marker, Reference designator
5. Properties:
   - Description: "Mi footprint description"
   - Tags: "palabras clave"
   - 3D Model: Add .step/.wrl (opcional)
6. Save → Add library to project
```

### Estándares IPC-7351 (Niveles)

| Nivel | Densidad | Clearance courtyard | Uso |
|---|---|---|-----|
| **L (Least)** | Baja | 0.50mm | Prototipos, mano |
| **N (Nominal)** | Media | 0.25mm | **Producción estándar** |
| **M (Most)** | Alta | 0.10mm | Alta densidad, automático |

**Recomendado:** Nivel N (Nominal)

---

## 3D Models

### Formatos soportados
- `.step` / `.stp` (STEP AP214 - preferido)
- `.wrl` (VRML 2.0 - legacy)
- `.stl` (Solo visualización, sin colores)

### Añadir a footprint
```
Footprint Editor → Footprint Properties → 3D Models → +
  → File: "model.step"
  → Offset X/Y/Z: 0, 0, 0 (ajustar)
  → Rotation X/Y/Z: 0, 0, 0
  → Scale: 1, 1, 1
  → Opacity: 1.0
```

### Fuentes modelos 3D
| Fuente | URL | Licencia |
|---|-----|---|
| **KiCad 3D Models** | https://github.com/KiCad/kicad-packages3D | CC-BY-SA 4.0 |
| **SnapEDA** | https://www.snapeda.com/ | Gratis registro |
| **LCSC/JLCPCB** | https://lcsc.com/ | Gratis |
| **GrabCAD** | https://grabcad.com/ | Varias |
| **Fabricante** | Web del fabricante | Ver datasheet |

---

## Mejores prácticas librerías

| Práctica | Por qué |
|---|---|
| **Nombres descriptivos** | `Conn_01x04_P2.54mm_Vertical` vs `J1` |
| **Prefijos consistentes** | `Resistor_`, `Capacitor_`, `IC_`, `Conn_` |
| **Unidades métricas** | mm para todo (KiCad nativo mm) |
| **Origen en centro** | Para SMD: centro cuerpo; THT: pin 1 o centro |
| **Pin 1 marcado** | Círculo, muesca, chanfle en silkscreen |
| **Courtyard IPC** | Nivel N para producción |
| **3D model aligned** | Verificar en 3D Viewer (`Alt+3`) |
| **Versionar librerías** | Commit `.kicad_sym` y `.pretty` en repo |

---

## Compartir librerías

### Git submodule (recomendado)
```bash
git submodule add https://github.com/tu-usuario/kicad-libs.git libs/kicad-libs
# En proyecto:
Preferences → Libraries → ${KIPRJMOD}/../libs/kicad-libs/symbols
```

### Copia local (simple)
```bash
cp -r /ruta/a/librerias/* ./mis_libs/
# En KiCad: ${KIPRJMOD}/mis_libs/
```

### KiCad Library Convention (KLC)
Seguir [KLC](https://github.com/KiCad/kicad-library-conventions) para contribuir upstream:
- Nomenclatura, estructura, metadatos, 3D models
- Requerido para merge en librería oficial KiCad

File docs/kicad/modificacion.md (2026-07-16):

# KiCad - Modificar el diseño

## Flujo de trabajo típico

```
1. Esquemático → 2. PCB → 3. DRC → 4. Fabricación
     ↑              ↑
     └──────────────┘ (Iterar)
```

---

## Cambios comunes

### 1. Cambiar valor componente (ej. R 1k → 4.7k)

**Esquemático:**
1. Click derecho en R → `E` (Properties)
2. Cambiar `Value`: `1k` → `4.7k`
3. `OK`

**PCB:** *No requiere cambio* (footprint mismo)

---

### 2. Cambiar componente por otro equivalente (ej. LM7805 → L7805CV)

**Esquemático:**
1. Click en U_5V → `E` → Change Symbol
3. Buscar "L7805" / "LM7805" → Seleccionar
4. Verificar pines coinciden (IN/GND/OUT)
5. `OK`

**PCB:**
1. `F8` (Update PCB from Schematic)
2. `Update` → Footprint debe ser mismo (TO-220)
3. Si footprint distinto: `Delete` viejo → colocar nuevo → `X` (route)

---

### 3. Añadir nuevo componente (ej. Sensor BMP280 I2C)

**Esquemático:**
1. `A` → Buscar "BMP280" (o genérico "Sensor_I2C")
2. Colocar cerca J_I2C
3. Conectar: SDA→GPIO21, SCL→GPIO19, 3.3V, GND
4. `Value`: "BMP280" → `Reference`: "U_BMP"
5. Anotar: `Tools → Annotation → Annotate`

**PCB:**
1. `F8` → Update PCB
2. Footprint aparece en "Unplaced" (lista derecha)
3. Click → `M` (Move) → Colocar cerca J_I2C
3. `X` (Route) → Conectar pistas 0.2mm
4. `B` → Regenerar GND pour

---

### 4. Cambiar footprint (ej. 0805 → 0603)

**Esquemático:**
1. Click componente → `E` → `Footprint` → Browse
2. Filtrar "0603" → Seleccionar `Resistor_SMD:R_0603_1608Metric`
3. `OK`

**PCB:**
1. `F8` → Update
2. KiCad detecta cambio → Pregunta "Replace footprint?"
3. `Update` → Componente se mueve a "Unplaced"
4. Colocar nuevo → Routear

---

### 5. Mover conector / añadir header

**Esquemático:**
1. Añadir símbolo `Conn_01x04` → Conectar nets
3. Valor: "J_I2C_EXT" → Ref: "J_I2C_EXT"

**PCB:**
1. `F8` → Update
2. Footprint: `Connector_PinHeader_2.54mm:PinHeader_1x04_P2.54mm_Vertical`
3. Colocar en borde PCB (Edge.Cuts margin 5mm)
4. Routear: `X` → pistas 0.2mm → `V` (via si cruza)

---

## Edición de pistas y zonas

### Ampliar pista potencia
```
1. Click pista → `E` (Properties)
2. Net Class: "Power_5V" (0.5mm) → OK
3. O: `Ctrl+E` (Global Edit) → Tracks → Width → 0.5mm → Filter: Net="+5V"
```

### Añadir via stitching GND
```
1. Route track GND → `V` (add via) → continua en B.Cu
2. O: `Place → Add Filled Zone` → GND → dibuja área → `B` (fill)
```

### Modificar zone GND pour
```
1. Click zone outline → `E`
3. Net: GND → Layer: B.Cu (o F.Cu)
4. Clearance: 0.5mm → Min width: 0.2mm
5. Thermal relief: 0.25mm gap, 4 spokes
6. `B` (Fill zones) para regenerar
```

---

## Cambios estructurales

### Añadir capa (4 capas → requiere PCB nuevo)
```
File → Board Setup → Board Stackup
  Layers: 4 → Add In1.Cu, In2.Cu
  Materials: FR4, 1.6mm total
  Impedance controlled: configure diff pairs
```
> **Nota**: Cambio mayor, requiere re-routeo completo

### Cambiar tamaño PCB
```
1. Edge.Cuts layer activo
2. Click línea borde → `E` → Edit coordinates
3. O: `Ctrl+M` (Move Exact) → ΔX, ΔY
4. `B` → Regenerar zones
5. Revisar DRC (mounting holes, connectores)
```

### Añadir mounting hole
```
PCB Editor:
  Place → Footprint → "MountingHole" → "MountingHole_3.2mm_M3"
  Colocar 4 esquinas (5mm margen)
  Properties → Net: "GND" (opcional, plated)
```

---

## Validación post-cambios

### Checklist obligatorio
```
□ DRC: 0 Errors, 0 Warnings (except courtyards opcional)
□ Netlist: Esquemático ↔ PCB coinciden (F8 → no cambios)
□ ERC: Esquemático sin errores (Inspect → ERC)
□ BOM: Genera sin warnings (Tools → Generate BOM)
□ 3D Viewer: No colisiones mecánicas (Alt+3)
□ Gerbers: Visualizar en gerber-viewer (online)
```

### Test eléctrico mental
```
□ Power nets: +5V, +3V3, GND separados, sin shorts
□ MCU: Todos GPIOs usados tienen net asignada
□ Strapping pins: GPIO0,2,12,15 no forzados a nivel incorrecto
□ Decoupling: 100nF cerca cada IC VCC/GND
□ High current: Pistas motor ≥1mm, vias stitching
□ Analog: ADC traces lejos de PWM/Clock
□ Mounting: Holes no tocan pistas (clearance 1mm)
```

---

## Git workflow para cambios

```bash
# 1. Rama para cambio
git checkout -b feat/nuevo-sensor-bmp280

# 2. Editar en KiCad, commit frecuente
git add base_esp32.kicad_sch base_esp32.kicad_pcb
git commit -m "feat: add BMP280 I2C sensor
- Added U_BMP symbol connected to I2C bus
- Footprint: LGA-8 2x2mm
- Routed on top layer near J_I2C"

# 3. Generar fabricación
# File → Fabrication Outputs → Gerbers → gerber_v0.5.zip

# 4. Commit artefacts (opcional, o en release)
git add fabricacion/gerber_v0.5.zip fabricacion/bom_v0.5.csv
git commit -m "chore: fab files v0.5"

# 5. Push y PR
git push origin feat/nuevo-sensor-bmp280
# Crear PR → Review → Merge → Tag v0.5
```

---

## Backup y recuperación

### Backup automático (KiCad)
```
Preferences → Preferences → Common → Auto-save
  ✓ Create backup files
  ✓ Auto-save interval: 5 min
  ✓ Max backup files: 10
```

### Backup manual (antes de cambios grandes)
```bash
cp base_esp32.kicad_sch base_esp32.kicad_sch.backup
cp base_esp32.kicad_pcb base_esp32.kicad_pcb.backup
cp base_esp32.kicad_pro base_esp32.kicad_pro.backup
```

### Restaurar
```bash
# Si corrupto:
cp base_esp32.kicad_sch.backup base_esp32.kicad_sch
# O desde git:
git restore base_esp32.kicad_sch
```

---

## Migración versiones KiCad

| De → A | Acción |
|---|---|
| 6 → 7 | Abrir → Guardar (auto-migra) |
| 7 → 8 | Abrir → Guardar (auto-migra) |
| 8 → 9 | Abrir → Guardar (auto-migra) |
| 5 → 6+ | Exportar netlist → Importar en nuevo |

> **Siempre**: Backup antes de abrir en versión mayor

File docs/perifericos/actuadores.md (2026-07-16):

# Actuadores

## Motor DC - MX1508

### Hardware
```
MX1508 Dual H-Bridge
┌─────────────────────────────────────────────────────────────┐
│  GPIO12 ──► IN1 ──┐                                        │
│  GPIO13 ──► IN2 ──┤       Canal A (Motor 1)                │
│                   ├──── OUT1 ──► MOT_A+                     │
│                   ├──── OUT2 ──► MOT_A-                     │
│  GPIO14 ──► IN3 ──┤                                        │
│  GPIO15 ──► IN4 ──┤       Canal B (Motor 2)                │
│                   ├──── OUT3 ──► MOT_B+                     │
│                   ├──── OUT4 ──► MOT_B-                     │
│                      VM ──► +5V Rail (desde LM7805)        │
│                      VCC ──► +5V Rail (lógica)             │
│                      GND ──► GND                            │
└─────────────────────────────────────────────────────────────┘

Terminal Block (J_TERM):
Pin 1: MOT_A+  │  Pin 2: MOT_A-
Pin 3: MOT_B+  │  Pin 4: MOT_B-
```

### Control básico (un motor)
```cpp
#define MOT_A_IN1 12
#define MOT_A_IN2 13

void motorA(int speed) {  // -255 a 255
  if(speed > 0) {
    analogWrite(MOT_A_IN1, speed);
    analogWrite(MOT_A_IN2, 0);
  } else if(speed < 0) {
    analogWrite(MOT_A_IN1, 0);
    analogWrite(MOT_A_IN2, -speed);
  } else {
    analogWrite(MOT_A_IN1, 0);
    analogWrite(MOT_A_IN2, 0);  // Coast
  }
  // Para brake: analogWrite ambos = 255 (o 128 para brake suave)
}

void setup() {
  pinMode(MOT_A_IN1, OUTPUT);
  pinMode(MOT_A_IN2, OUTPUT);
  // PWM setup
  ledcAttachPin(MOT_A_IN1, 0);
  ledcAttachPin(MOT_A_IN2, 1);
  ledcSetup(0, 20000, 8);  // 20kHz, 8-bit
  ledcSetup(1, 20000, 8);
}

void loop() {
  motorA(200);  delay(2000);  // Forward
  motorA(0);    delay(500);   // Stop
  motorA(-200); delay(2000);  // Reverse
  motorA(0);    delay(500);
}
```

### Control dos motores (diferencial)
```cpp
#define MOT_A_IN1 12
#define MOT_A_IN2 13
#define MOT_B_IN3 14
#define MOT_B_IN4 15

// Canales PWM: 0,1,2,3
void setMotor(int motor, int speed) {  // motor: 0=A, 1=B
  int in1 = motor ? 2 : 0;
  int in2 = motor ? 3 : 1;
  
  if(speed > 0) { ledcWrite(in1, speed); ledcWrite(in2, 0); }
  else if(speed < 0) { ledcWrite(in1, 0); ledcWrite(in2, -speed); }
  else { ledcWrite(in1, 0); ledcWrite(in2, 0); }
}

void moveRobot(int left, int right) {  // -255 a 255
  setMotor(0, left);
  setMotor(1, right);
}

// Movimientos básicos
void forward(int s) { moveRobot(s, s); }
void backward(int s) { moveRobot(-s, -s); }
void turnLeft(int s) { moveRobot(-s, s); }
void turnRight(int s) { moveRobot(s, -s); }
void stopRobot() { moveRobot(0, 0); }
```

### PWM Frequency - Importante!
```cpp
// MX1508 soporta hasta ~20-50kHz
// ESP32: 20kHz buen compromiso (audible whisper vs eficiencia)

#define PWM_FREQ 20000  // 20 kHz - fuera rango auditivo humano
#define PWM_RES 8       // 8-bit = 0-255

ledcSetup(channel, PWM_FREQ, PWM_RES);
```

### Corriente y protección
- **Límite interno**: ~2.5A pico por canal
- **Térmico**: Shutdown @ 150°C
- **Medir corriente**: Usar A9013 en rail +5V (ver [Monitoreo](../perifericos/monitoreo.md))

---

## Servo - Control directo

### Hardware
```
GPIO18 ──► Signal (Naranja/Blanco)
+5V Rail ──► VCC (Rojo)  ← Desde LM7805 (terminal block)
GND ─────► GND (Marrón/Negro)

Header 3 pines estándar (pitch 2.54mm)
Compatible: SG90, MG90S, MG996R, etc.
```

### Control con ESP32Servo
```cpp
#include <ESP32Servo.h>

Servo myservo;
#define SERVO_PIN 18

void setup() {
  myservo.setPeriodHertz(50);  // 50Hz estándar
  myservo.attach(SERVO_PIN, 500, 2500);  // min/max µs
}

void loop() {
  // Barrido
  for(int pos=0; pos<=180; pos++) {
    myservo.write(pos);
    delay(15);
  }
  for(int pos=180; pos>=0; pos--) {
    myservo.write(pos);
    delay(15);
  }
  
  // Posiciones específicas
  myservo.write(0);   delay(1000);
  myservo.write(90);  delay(1000);
  myservo.write(180); delay(1000);
}
```

### Control sin librería (PWM directo)
```cpp
#define SERVO_PIN 18
#define PWM_CH 4

void setup() {
  ledcAttachPin(SERVO_PIN, PWM_CH);
  ledcSetup(PWM_CH, 50, 16);  // 50Hz, 16-bit (0-65535)
}

void servoWrite(int angle) {  // 0-180
  // 0.5ms = 0°, 2.5ms = 180° @ 50Hz (periodo 20ms)
  // duty = (pulse_ms / 20ms) * 65535
  int pulse_us = map(angle, 0, 180, 500, 2500);
  uint32_t duty = (pulse_us * 65535) / 20000;
  ledcWrite(PWM_CH, duty);
}
```

### Múltiples servos
```cpp
// ESP32 soporta hasta 16 canales PWM independientes
Servo servo[4];
int pins[4] = {18, 19, 21, 22};  // GPIOs disponibles

void setup() {
  for(int i=0; i<4; i++) {
    servo[i].setPeriodHertz(50);
    servo[i].attach(pins[i]);
  }
}
```

---

## Buzzer
Ver [Buzzer](../perifericos/buzzer.md) - GPIO25

---

## LEDs
Ver [LEDs](../perifericos/leds.md) - GPIO0,2,4,5 + RGB en GPIO2

---

## Resumen pines actuadores

| Función | GPIO | PWM Channel | Notas |
|---|---|---|---|
| Motor A IN1 | 12 | 0 | PWM 20kHz |
| Motor A IN2 | 13 | 1 | PWM 20kHz |
| Motor B IN3 | 14 | 2 | PWM 20kHz |
| Motor B IN4 | 15 | 3 | PWM 20kHz |
| Servo | 18 | 4 | 50Hz |
| Buzzer | 25 | 5 | tone()/PWM |
| LED D1 | 0 | 6 | PWM opcional |
| LED D2 | 2 | 7 | Compartido RGB |
| LED D3 | 4 | 8 | PWM opcional |
| LED D4 | 5 | 9 | PWM opcional |
| RGB | 2 | - | FastLED/NeoPixel (GPIO bit-bang) |

> **Total canales PWM usados**: 10 de 16 disponibles (ESP32)

---

## Prácticas sugeridas

| Práctica | Actuadores | Nivel |
|---|---|---|
| **06-Motor Control** | Motor DC velocidad/dirección | Intermediate |
| **10-Servo** | Servo barrido/posiciones | Intermediate |
| **07-Buzzer** | Buzzer melodías | Beginner |
| **12-Communication** | Motor + Servo coordinados | Advanced |
| **Robot Chasis** | 2 Motores diferencial + Servo sensor | Advanced |

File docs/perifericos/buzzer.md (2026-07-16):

# Buzzer

## Especificaciones

| Parámetro | Valor |
|---|---|
| **Tipo** | Buzzer pasivo (piezoeléctrico) |
| **Modelo** | SS-12D1305-G2 (o equivalente) |
| **Voltaje** | 3-5V (drive directo GPIO) |
| **Corriente** | ~15mA @ 3.3V |
| **Frecuencia resonante** | ~2.7 kHz |
| **SPL** | 85dB @ 10cm |
| **Encapsulado** | THT 12mm, pitch 7.5mm |
| **Pines** | 2 pines (sin polaridad) |

## Conexión en la Base

```
GPIO25 (DAC1) ──► Buzzer Pin 1
GND ─────────────► Buzzer Pin 2
```

**Nota**: GPIO25 también es DAC1 y ADC2_CH8. Compartido con sensor LM35 (ADC).

## Teoría: Buzzer pasivo vs activo

| Tipo | Drive | Frecuencia | Control |
|---|---|---|---|
| **Activo** | DC (HIGH/LOW) | Fija interna | Solo ON/OFF |
| **Pasivo** | AC (PWM/tonos) | Variable | Control total frecuencia |

**El nuestro es PASIVO** → Requiere señal alterna (PWM, tone(), DAC)

## Programación

### Método 1: `tone()` - Arduino core (Recomendado)
```cpp
#define BUZZER_PIN 25

void setup() {
  // tone() usa hardware timer, no bloquea
}

void loop() {
  // Nota única
  tone(BUZZER_PIN, 440, 500); // 440Hz (La4) por 500ms
  delay(600);
  
  // Melodía simple
  int melody[] = {262, 294, 330, 349, 392, 440, 494, 523}; // Do Re Mi Fa Sol La Si Do
  for(int n : melody) {
    tone(BUZZER_PIN, n, 200);
    delay(250);
  }
  noTone(BUZZER_PIN);
  delay(1000);
}
```

### Método 2: PWM con `ledc` (Más control)
```cpp
#define BUZZER_PIN 25
#define PWM_CHANNEL 0

void playTone(uint16_t freq, uint16_t duration_ms) {
  if(freq == 0) {
    ledcWrite(PWM_CHANNEL, 0);
    return;
  }
  ledcSetup(PWM_CHANNEL, freq, 8); // 8-bit resolution
  ledcWrite(PWM_CHANNEL, 128);     // 50% duty cycle
  delay(duration_ms);
  ledcWrite(PWM_CHANNEL, 0);
}

void setup() {
  ledcAttachPin(BUZZER_PIN, PWM_CHANNEL);
}

void loop() {
  playTone(440, 300);  // La4
  playTone(523, 300);  // Do5
  playTone(659, 300);  // Mi5
  delay(1000);
}
```

### Método 3: DAC (Waveform arbitraria)
```cpp
#define BUZZER_PIN 25  // DAC1

void playSineWave(uint16_t freq, uint16_t duration_ms) {
  const uint16_t samples = 100;
  uint32_t period_us = 1000000 / freq;
  uint32_t start = micros();
  
  while(micros() - start < duration_ms * 1000) {
    for(int i=0; i<samples; i++) {
      // Seno: 0-255 centrado en 127
      uint8_t val = 127 + 127 * sin(2 * PI * i / samples);
      dacWrite(BUZZER_PIN, val);
      delayMicroseconds(period_us / samples);
    }
  }
  dacWrite(BUZZER_PIN, 0);
}
```

### Melodía completa (RTTTL / notas)
```cpp
#include "pitches.h"  // Definiciones NOTE_C4, NOTE_D4, etc.

#define BUZZER_PIN 25

// Melodía: Star Wars Imperial March (simplificada)
int melody[] = {
  NOTE_G3, NOTE_G3, NOTE_G3, NOTE_DS3, NOTE_AS3,
  NOTE_G3, NOTE_DS3, NOTE_AS3, NOTE_G3,
  NOTE_D4, NOTE_D4, NOTE_D4, NOTE_DS4, NOTE_AS3,
  NOTE_FS3, NOTE_DS3, NOTE_AS3, NOTE_G3
};

int durations[] = {
  500, 500, 500, 350, 150,
  500, 350, 150, 1000,
  500, 500, 500, 350, 150,
  500, 350, 150, 1000
};

void playMelody() {
  for(int i=0; i<sizeof(melody)/sizeof(int); i++) {
    tone(BUZZER_PIN, melody[i], durations[i] * 0.9);
    delay(durations[i]);
  }
  noTone(BUZZER_PIN);
}
```

## Prácticas sugeridas

| Práctica | Descripción | Nivel |
|---|---|---|
| **01-Beep** | Beep simple 1s on/off | Beginner |
| **02-Scale** | Tocar escala mayor | Beginner |
| **03-Melody** | Tocar canción completa | Intermediate |
| **04-Alarm** | Alarma con sensor (temp > 30°C) | Intermediate |
| **05-Morse** | Código morse por buzzer | Intermediate |
| **06-DTMF** | Tonos teléfono (DTMF) | Advanced |
| **07-Synthesis** | Síntesis aditiva simple | Advanced |

## Consideraciones de hardware

### Driver transistor (opcional, para más volumen)
```
GPIO25 ──[1kΩ]──► Base (BC547/2N2222)
          Colector ──► Buzzer ──► 5V
          Emisor ──────► GND
```
- Permite usar 5V rail → más volumen
- Aísla GPIO de corriente inductiva buzzer
- **No implementado en v0.4** (drive directo GPIO suficiente)

### Filtrado EMI
- Buzzer piezoeléctrico = carga capacitiva ~10-20nF
- No genera EMI significativa
- Si se usa transistor: añadir diodo flyback en colector

## Datasheet

- [SS-12D1305-G2 Datasheet](../datasheets/SS-12D1305-G2.PDF)
- [Buzzer Pasivo Genérico](https://components101.com/sites/default/files/component_pin/Piezo-Buzzer.pdf)

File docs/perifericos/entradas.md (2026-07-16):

# Entradas

## Resumen

| Entrada | Tipo | GPIO | Pull | Activo | Notas |
|---|---|---|---|---|---|
| **DIP Switch ×4** | Digital | GPIO27,32,33,35 | Interno ↑ | LOW | Configuración modo |
| **Push Button** | Digital | GPIO25 | Interno ↑ | LOW | Usuario / Reset sw |
| **SPDT Switch** | Digital | GPIO26 | Externo | HIGH/LOW | 3 posiciones |
| **Potenciómetro** | Analógico | GPIO34 (ADC1_CH6) | - | 0-3.3V | 10kΩ lineal |

---

## DIP Switch 4 posiciones (SW_DIP)

### Hardware
```
GPIO27 ──► SW1-1 ──► GND
GPIO32 ──► SW1-2 ──► GND
GPIO33 ──► SW1-3 ──► GND
GPIO35 ──► SW1-4 ──► GND

Pull-up: Interno ESP32 (GPIO_PULLUP_ENABLE)
```

### Lectura
```cpp
#define DIP1 27
#define DIP2 32
#define DIP3 33
#define DIP4 35

void setup() {
  pinMode(DIP1, INPUT_PULLUP);
  pinMode(DIP2, INPUT_PULLUP);
  pinMode(DIP3, INPUT_PULLUP);
  pinMode(DIP4, INPUT_PULLUP);
  // GPIO34,35,36,39 son INPUT_ONLY - no tienen pull-up interno
  // Para GPIO35: usar pull-up EXTERNO 10kΩ a 3.3V si necesario
}

uint8_t readDIP() {
  uint8_t val = 0;
  val |= (!digitalRead(DIP1)) << 0;  // Bit 0
  val |= (!digitalRead(DIP2)) << 1;  // Bit 1
  val |= (!digitalRead(DIP3)) << 2;  // Bit 2
  val |= (!digitalRead(DIP4)) << 3;  // Bit 3
  return val;  // 0x00 a 0x0F
}

// Uso: seleccionar modo programa
void loop() {
  uint8_t mode = readDIP();
  switch(mode) {
    case 0x01: modoBlink(); break;
    case 0x02: modoPWM(); break;
    case 0x03: modoSensor(); break;
    case 0x0F: modoTest(); break;
    default: modoDefault(); break;
  }
}
```

### Aplicaciones típicas
| Valor DIP (binario) | Hex | Función sugerida |
|---|-----|---|
| 0000 | 0x0 | Modo normal / Usuario |
| 0001 | 0x1 | Blink LED test |
| 0010 | 0x2 | PWM Demo |
| 0011 | 0x3 | Leer sensores |
| 0100 | 0x4 | Motor test |
| 0101 | 0x5 | Servo test |
| 0110 | 0x6 | Buzzer melodía |
| 0111 | 0x7 | Comunicación serial |
| 1000 | 0x8 | Deep sleep test |
| 1111 | 0xF | Factory test completo |

---

## Push Button (SW_PUSH)

### Hardware
```
GPIO25 ──► SW_PUSH ──► GND
           │
           └── Pull-up interno (INPUT_PULLUP)
```

**¡Comparte GPIO25 con BUZZER!**
- No usar buzzer y botón simultáneamente
- O diseñar firmware que alterne

### Lectura con debounce
```cpp
#define BTN_PIN 25

// Debounce simple
bool readButton() {
  static uint32_t lastPress = 0;
  static bool lastState = HIGH;
  bool current = digitalRead(BTN_PIN);
  
  if(current != lastState) {
    if(millis() - lastPress > 50) {  // 50ms debounce
      lastPress = millis();
      lastState = current;
      return !current;  // true = presionado (LOW)
    }
  }
  return false;
}

// Detectar flanco (press event)
bool buttonPressed() {
  static bool lastReading = HIGH;
  bool current = digitalRead(BTN_PIN);
  bool pressed = (lastReading == HIGH && current == LOW);
  lastReading = current;
  return pressed;
}
```

### Interrupción (wake from sleep)
```cpp
#define BTN_PIN 25

void IRAM_ATTR buttonISR() {
  // Mínimo código en ISR
  buttonFlag = true;
}

void setup() {
  pinMode(BTN_PIN, INPUT_PULLUP);
  attachInterrupt(BTN_PIN, buttonISR, FALLING);
  
  // Configurar wake-up desde deep sleep
  esp_sleep_enable_ext0_wakeup(GPIO_NUM_25, 0); // LOW = wake
}

void loop() {
  if(buttonFlag) {
    buttonFlag = false;
    Serial.println("Botón presionado!");
    // Acción...
  }
  
  // Deep sleep ejemplo
  if(shouldSleep) {
    esp_deep_sleep_start();
  }
}
```

---

## SPDT Switch (SW_SPDT)

### Hardware
```
        3.3V (via 10kΩ pull-up)
           │
           ▼
GPIO26 ───┼───► SW_SPDT Centro (COM)
           │
      ┌────┴────┐
      ▼         ▼
   NO (NC)   NC (NO)
      │         │
     GND       3.3V (via pull-down 10kΩ)
```

**Estados:**
| Posición | GPIO26 | Descripción |
|---|---|---|
| **Arriba** | HIGH (3.3V) | Conectado a 3.3V vía pull-down |
| **Centro** | FLOAT (evitar) | No conectado - ruido |
| **Abajo** | LOW (GND) | Conectado a GND |

### Implementación recomendada (evitar float)
```
Usar SPDT "ON-ON" (sin centro) o leer solo extremos:

        3.3V
         │
      10kΩ
         │
GPIO26 ───┼───► SW_SPDT Pin 1
         │
        SW_SPDT Pin 2 ───► GND
         │
        SW_SPDT Pin 3 ───► (no conectado)
```
Con ON-ON: Pos1=HIGH, Pos2=LOW, sin estado float.

### Lectura
```cpp
#define SPDT_PIN 26

// Con pull-up interno + switch a GND (configuración simple)
pinMode(SPDT_PIN, INPUT_PULLUP);
// Pos1 (switch abierto): HIGH
// Pos2 (switch a GND): LOW

bool readSPDT() {
  return digitalRead(SPDT_PIN);  // true = Pos1, false = Pos2
}
```

---

## Potenciómetro 10kΩ (RV_POT)

### Hardware
```
3.3V ────────► Pin 1 (Extremo)
              │
GPIO34 (ADC1_CH6) ──► Pin 2 (Cursor/Wiper)
              │
GND ─────────► Pin 3 (Extremo)
```

**GPIO34 = ADC1_CH6 = INPUT ONLY** (sin pull-up/down, sin output)

### Lectura
```cpp
#define POT_PIN 34  // ADC1_CH6

void setup() {
  Serial.begin(115200);
  analogReadResolution(12);    // 0-4095
  analogSetAttenuation(ADC_11db); // Rango ~0-3.3V
}

void loop() {
  int raw = analogRead(POT_PIN);
  float voltage = raw * 3.3 / 4095.0;
  float percentage = (raw / 4095.0) * 100.0;
  
  Serial.printf("Pot: raw=%d V=%.2f %%%.1f\n", raw, voltage, percentage);
  delay(100);
}
```

### Filtrado (ruido ADC)
```cpp
// Promedio móvil simple
#define POT_SAMPLES 16
int potBuffer[POT_SAMPLES];
int potIndex = 0;
long potSum = 0;

int readPotFiltered() {
  potSum -= potBuffer[potIndex];
  potBuffer[potIndex] = analogRead(POT_PIN);
  potSum += potBuffer[potIndex];
  potIndex = (potIndex + 1) % POT_SAMPLES;
  return potSum / POT_SAMPLES;
}
```

### Mapeo a rangos útiles
```cpp
// Map a 0-255 (PWM)
int pwmVal = map(readPotFiltered(), 0, 4095, 0, 255);

// Map a 0-180 (Servo)
int servoAng = map(readPotFiltered(), 0, 4095, 0, 180);

// Map a frecuencia (Buzzer)
int freq = map(readPotFiltered(), 0, 4095, 100, 5000);

// Map a delay (Blink)
int delayMs = map(readPotFiltered(), 0, 4095, 50, 2000);
```

---

## Tabla completa GPIOs Entradas

| GPIO | Entrada | Tipo | Pull | ADC | Touch | Strapping |
|---|---|---|---|-----|---|---|
| 25 | Push Button / Buzzer | Digital/Out | ↑ | ADC2_CH8 | Sí | - |
| 26 | SPDT Switch | Digital | ↑/↓ | ADC2_CH9 | Sí | - |
| 27 | DIP-1 | Digital | ↑ | ADC2_CH7 | Sí | - |
| 32 | DIP-2 | Digital | ↑ | ADC1_CH4 | Sí | - |
| 33 | DIP-3 | Digital | ↑ | ADC1_CH5 | Sí | - |
| 34 | Potenciómetro | Analog | - | ADC1_CH6 | No | - |
| 35 | DIP-4 | Digital | Ext ↑ | ADC1_CH7 | No | - |

> **Nota**: GPIO34,35,36,39 son **INPUT ONLY**. No pueden ser output, no tienen pull-up/down interno.
> - GPIO35 (DIP-4): Requiere pull-up **externo** 10kΩ a 3.3V para lectura fiable
> - GPIO34 (Pot): No necesita pull, divisor de tensión del potenciómetro define voltaje

---

## Prácticas sugeridas

| Práctica | Entradas usadas | Nivel |
|---|---|---|
| **03-Analog Read** | Potenciómetro | Beginner |
| **04-Interrupts** | Push Button | Beginner |
| **08-Switches** | DIP Switch + SPDT | Intermediate |
| **11-Sensor Fusion** | Todas + Sensores | Advanced |

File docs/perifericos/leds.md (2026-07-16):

# LEDs

## Resumen

| LED | Referencia | GPIO | Color | Resistencia | Función |
|-----|---|---|---|---|---|
| **D1** | LED_USR1 | GPIO0 | Rojo | 330Ω | Usuario / Boot indicator |
| **D2** | LED_USR2 | GPIO2 | Azul | 330Ω | Built-in / RGB Data |
| **D3** | LED_USR3 | GPIO4 | Verde | 330Ω | Usuario |
| **D4** | LED_USR4 | GPIO5 | Amarillo | 330Ω | Usuario |
| **RGB** | LED_RGB | GPIO2 | WS2812B | - | Direccionable (comparte GPIO2) |
| **PWR5V** | LED_5V | - | Rojo | 1kΩ | Indicador rail 5V |
| **PWR3V3** | LED_3V3 | - | Verde | 1kΩ | Indicador rail 3.3V |

---

## LEDs Usuario (D1-D4)

### Hardware
```
GPIOx ──► [330Ω] ──► Ánodo LED ──► Cátodo ──► GND

GPIO0 ──► D1 (Rojo)
GPIO2 ──► D2 (Azul) ──┐
GPIO4 ──► D3 (Verde)  │
GPIO5 ──► D4 (Amarillo)│
                      └── Comparten GPIO2 con RGB
```
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

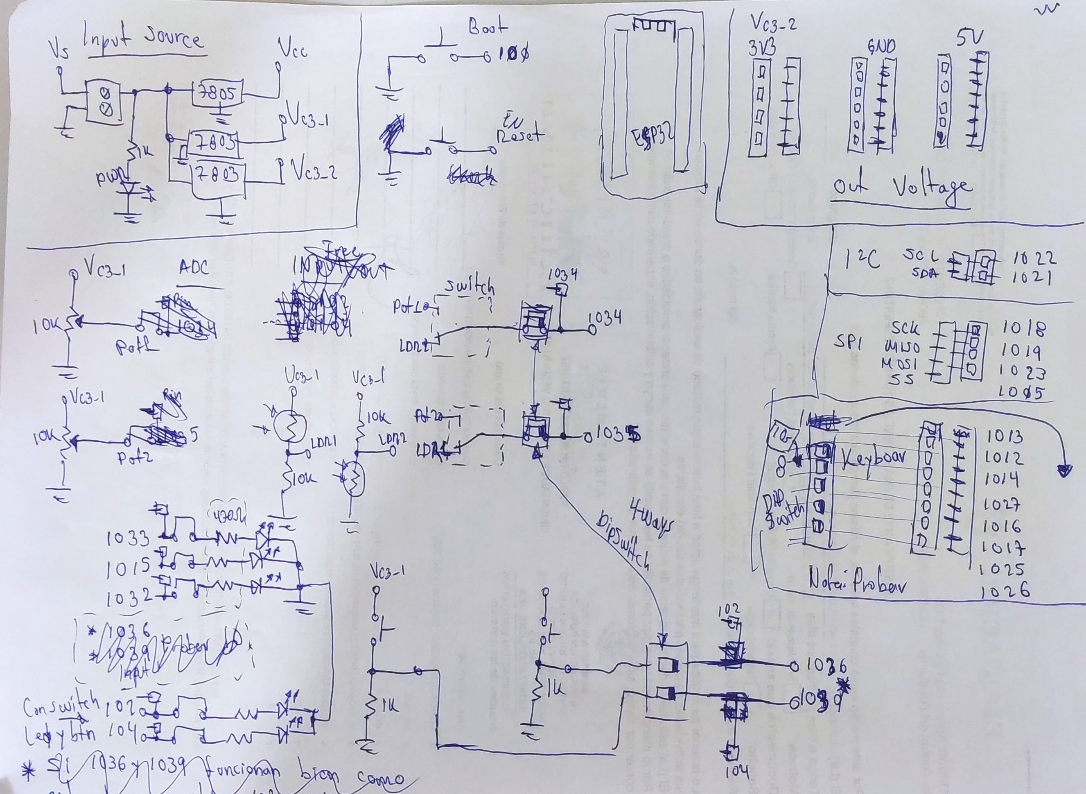
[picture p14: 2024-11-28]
assets/raw.jpg

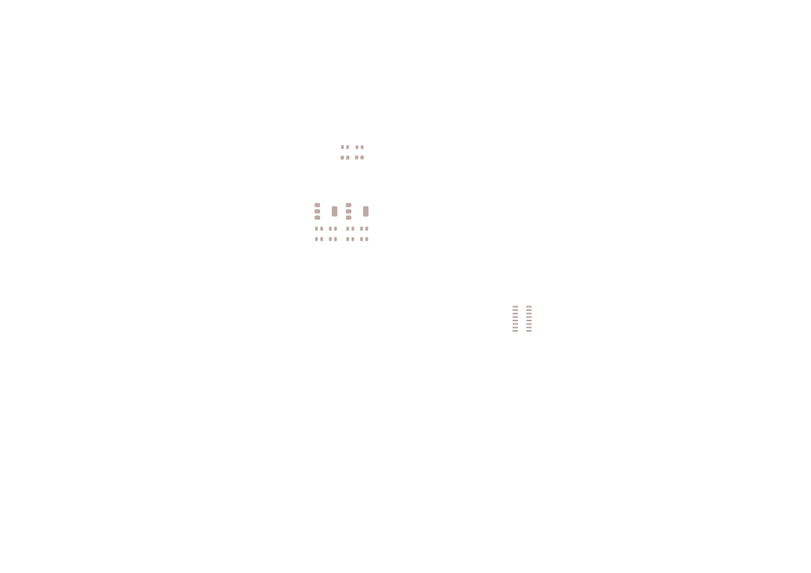
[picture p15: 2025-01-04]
pcb/base_esp32-F_Paste.png

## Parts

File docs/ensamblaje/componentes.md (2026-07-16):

# Ensamblaje - Lista de componentes (BOM)

## Dónde comprar

| Proveedor | Ventajas | Envío a España |
|---|---|---|
| **LCSC / JLCPCB** | Precios bajos, stock real, integra con JLCPCB | 5-10 días |
| **Mouser / DigiKey** | Stock garantizado, datasheets, rápido | 1-3 días |
| **Amazon / AliExpress** | Barato, envío rápido (Amazon) | 1-7 días |
| **Tiendas locales** | Soporte, sin aduanas | Inmediato |

> **Tip**: Haz pedido único en LCSC + JLCPCB para PCBs + componentes (ensamblaje opcional)

---

## BOM por categorías

### 1. MCU y Socket

| Ref | Cant | Descripción | Valor | Footprint | LCSC | Mouser |
|-----|---|---|---|---|---|---|
| U_ESP32 | 1 | ESP32 DevKit V4 (WROOM-32E) | - | ESP32-DevKitC (custom) | C132755 | 868-ESP32-DEVKITC-V4 |
| J1, J2 | 2 | Header hembra 2x19 | 2.54mm | Header_2x19_F | C110754 | 649-68000-136 |

### 2. Reguladores y protección

| Ref | Cant | Descripción | Valor | Footprint | LCSC | Mouser |
|-----|---|---|---|---|---|---|
| U_5V | 1 | Regulador lineal 5V 1.5A | LM7805CT | TO-220-3_Vertical | C17332 | 511-LM7805CT |
| U_3V3 | 1 | Regulador LDO 3.3V 800mA | AMS1117-3.3 | SOT-223-4 | C2882143 | 511-AMS1117-3.3 |
| D_PWR | 1 | Diodo Schottky 1A 40V | 1N5819 | SOD-123 | C23272 | 511-1N5819 |
| D_PROT | 1 | Diodo Schottky 1A 40V | 1N5819 | SOD-123 | C23272 | 511-1N5819 |
| D_DISC | 1 | Diodo Schottky 1A 40V | 1N5819 | SOD-123 | C23272 | 511-1N5819 |
| F_PTC | 0 | *Opcional v0.5* PTC 1A | 1206/2920 | 1206/2920 | C114542 | 652-MF-R1000 |

### 3. Driver Motor

| Ref | Cant | Descripción | Valor | Footprint | LCSC | Mouser |
|-----|---|---|---|---|---|---|
| U_MOT | 1 | Dual H-Bridge 1.5A | MX1508 / MX1515 | SOP-8 (custom) | C2882143 | - |

### 4. Monitor Corriente

| Ref | Cant | Descripción | Valor | Footprint | LCSC | Mouser |
|-----|---|---|---|---|---|---|
| U_IMON | 1 | Sensor Hall 400mV/A | A9013 | SIP-3 | C2882143 | 620-A9013 |

### 5. Sensores

| Ref | Cant | Descripción | Valor | Footprint | LCSC | Mouser |
|-----|---|---|---|---|---|---|
| U_TEMP1 | 1 | Temp digital 1-Wire | DS18B20 | TO-92 / Waterproof | C17829 | 700-DS18B20 |
| U_TEMP2 | 1 | Temp analógica 10mV/°C | LM35DZ | TO-92 | C2882143 | 511-LM35DZ |
| R_DS18B20 | 1 | Resistencia pull-up | 4.7kΩ | 0805 / Axial | C17434 | 660-ERJ-6ENF4701V |
| U_LDR | 1 | Fotoresistor | GL5528 / 5537 | 5mm THT | C17434 | - |
| R_LDR | 1 | Resistencia divisor | 10kΩ | 0805 / Axial | C17434 | 660-ERJ-6ENF1002V |

### 6. Actuadores

| Ref | Cant | Descripción | Valor | Footprint | LCSC | Mouser |
|-----|---|---|---|---|---|---|
| BZ1 | 1 | Buzzer pasivo 5V | 2.7kHz | 12mm THT | C17434 | 660-PKLS-1212E4001-R1 |
| LED_D1 | 1 | LED 3mm Rojo | 620nm | LED_THT_3mm | C17434 | 604-1080511000 |
| LED_D2 | 1 | LED 3mm Azul | 470nm | LED_THT_3mm | C17434 | 604-1080511000 |
| LED_D3 | 1 | LED 3mm Verde | 525nm | LED_THT_3mm | C17434 | 604-1080511000 |
| LED_D4 | 1 | LED 3mm Amarillo | 590nm | LED_THT_3mm | C17434 | 604-1080511000 |
| LED_RGB | 1 | LED RGB WS2812B | 5050 | LED_SMD_5050 | C2882143 | 604-1811 |
| R_LED1-4 | 4 | Resistencia limitación | 330Ω | 0805 / Axial | C17434 | 660-ERJ-6ENF3300V |
| R_LED5V | 1 | Resistencia LED 5V | 1kΩ | 0805 / Axial | C17434 | 660-ERJ-6ENF1001V |
| R_LED3V3 | 1 | Resistencia LED 3.3V | 1kΩ | 0805 / Axial | C17434 | 660-ERJ-6ENF1001V |

### 7. Entradas

| Ref | Cant | Descripción | Valor | Footprint | LCSC | Mouser |
|-----|---|---|---|---|---|---|
| SW_DIP | 1 | DIP Switch 4 posiciones | - | SW_DIP_4 | C17434 | 611-CTS-206-4 |
| SW_PUSH | 1 | Pulsador 6x6mm | - | SW_Push_6x6 | C17434 | 611-B3F-1000 |
| SW_SPDT | 1 | Switch deslizante 3 pos | ON-OFF-ON | SS-12D13 | C17434 | 611-SS-12D13-G2 |
| RV_POT | 1 | Potenciómetro 10k lineal | 10kΩ | Pot_THT_B10K | C17434 | 611-PTV09A-4020F |

### 8. Conectores

| Ref | Cant | Descripción | Valor | Footprint | LCSC | Mouser |
|-----|---|---|---|---|---|---|
| J_PWR | 1 | Jack DC 2.1mm | - | PJ-002AH | C17434 | 163-1637 |
| J_USB | 1 | USB Micro-B hembra | - | USB_Micro_B | C17434 | 475-1015-1 |
| J_TERM | 1 | Terminal block 4p | 5.08mm | Terminal_Block_4p | C17434 | 517-282836-4 |
| J_SERVO | 1 | Header 3p macho | 2.54mm | Header_3p_M | C17434 | 649-68000-136 |
| J_I2C | 1 | Header 4p macho | 2.54mm | Header_4p_M | C17434 | 649-68000-136 |
| J_SPI | 1 | Header 6p macho | 2.54mm | Header_6p_M | C17434 | 649-68000-136 |
| J_GPIO | 1 | Header 10p macho | 2.54mm | Header_10p_M | C17434 | 649-68000-136 |
| MH1-4 | 4 | Mounting hole M3 | 3.2mm | MountingHole_3.2mm | - | - |

### 9. Pasivos - Capacitores

| Ref | Cant | Valor | Tipo | Tensión | Footprint | LCSC |
|-----|---|---|---|---|---|---|
| C_IN_5V | 1 | 470µF | Electrolítico | 25V | Cap_THT_D8 | C17434 |
| C_IN_5V_S | 1 | 100nF | Cerámico X7R | 25V | 0805 | C17434 |
| C_OUT_5V | 1 | 100µF | Electrolítico | 10V | Cap_THT_D6 | C17434 |
| C_OUT_5V_S | 1 | 100nF | Cerámico X7R | 10V | 0805 | C17434 |
| C_OUT_3V3 | 1 | 100µF | Electrolítico | 6.3V | Cap_THT_D6 | C17434 |
| C_OUT_3V3_S | 1 | 100nF | Cerámico X7R | 6.3V | 0805 | C17434 |
| C_IMON | 1 | 100nF | Cerámico X7R | 6.3V | 0805 | C17434 |
| C_MOT_VM | 1 | 100µF | Electrolítico | 16V | Cap_THT_D6 | C17434 |
| C_MOT_VM_S | 1 | 100nF | Cerámico X7R | 16V | 0805 | C17434 |
| C_MOT_VCC | 1 | 10µF | Cerámico X5R | 10V | 0805 | C17434 |
| C_RGB | 1 | 100nF | Cerámico X7R | 6.3V | 0805 | C17434 |
| C_LDR | 1 | 100nF | Cerámico X7R | 6.3V | 0805 | C17434 |
| C_DEC_* | 10+ | 100nF | Cerámico X7R | 10-25V | 0805 | C17434 |

### 10. Pasivos - Resistencias

| Ref | Cant | Valor | Potencia | Tolerancia | Footprint | LCSC |
|-----|---|---|---|---|---|---|
| R_IMON | 1 | 10kΩ | 1/8W | 1% | 0805 | C17434 |
| R_PU_DIP | 4 | 10kΩ | 1/8W | 1% | 0805 | C17434 |
| R_LED_USR | 4 | 330Ω | 1/8W | 1% | 0805 | C17434 |
| R_LED_PWR | 2 | 1kΩ | 1/8W | 1% | 0805 | C17434 |
| R_*_0805 | 20+ | 10k, 4.7k, 1k, 330, 100 | 1/8W | 1% | 0805 | C17434 |
| R_*_AXIAL | 10+ | 1k, 330, 4.7k, 10k | 1/4W | 5% | Axial_0207 | C17434 |

### 11. Mecánicos

| Ref | Cant | Descripción | Especificación |
|-----|---|---|---|
| - | 4 | Tornillo M3x10 | Acero / Nylon |
| - | 4 | Separador M3x10mm | Nylon (aislante) |
| - | 4 | Tuerca M3 | Acero / Nylon |
| - | 1 | Disipador TO-220 | Para LM7805 |
| - | 1 | Pasta térmica | Silicone / Cerámica |

---

## Resumen coste estimado (precios 2024, unidades sueltas)

| Categoría | Coste EUR |
|---|---|
| MCU + Socket | ~€5.50 |
| Reguladores + Diodos | ~€1.50 |
| Driver Motor | ~€0.80 |
| Monitor Corriente | ~€1.20 |
| Sensores | ~€3.00 |
| Actuadores | ~€2.50 |
| Entradas | ~€1.50 |
| Conectores | ~€2.00 |
| Pasivos (C+R) | ~€2.00 |
| Mecánicos | ~€1.00 |
| **TOTAL** | **~€21.00** |

*PCB no incluido (~$2-5 por 5 uds en JLCPCB)*

---

## Alternativas / Sustituciones

| Original | Alternativa | Notas |
|---|---|---|
| LM7805CT | LM7805TO-220 / L7805CV | Mismo pinout |
| AMS1117-3.3 | LM1117-3.3 / LD1117-3.3 | SOT-223 compatible |
| MX1508 | MX1515 / L9110S | Verificar pinout |
| DS18B20 | DS18B20+ / DS18B20-PAR | Versión parasitica = 2 hilos |
| LM35DZ | LM35CAZ / TMP36 | TMP36 = 500mV offset |
| GL5528 | GL5537 / VT90N2 | Similares |
| WS2812B | SK6812 / WS2812C | Compatibles NeoPixel |
| 1N5819 | SS14 / SB140 | Schottky 1A 40V |
| Terminal Block 5.08 | 3.5mm / 5.0mm | Verificar footprint |

---

## Archivos BOM para fabricación

- `fabricacion/bom.csv` - Formato JLCPCB/LCSC (LCSC Part, Designator, Quantity)
- `fabricacion/bom.xlsx` - Con columnas extra (proveedor alternativo, precio, stock)
- `fabricacion/pnp.csv` - Pick & Place para SMT (Mid X, Mid Y, Rotation, Layer)

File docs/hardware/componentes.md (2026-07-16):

# Lista de materiales (BOM)

## Resumen por categorías

| Categoría | Componentes | Coste estimado |
|---|---|---|
| **MCU & Socket** | 2 | ~$4.50 |
| **Reguladores** | 5 | ~$2.00 |
| **Driver Motor** | 3 | ~$1.50 |
| **Sensores** | 6 | ~$3.00 |
| **Actuadores** | 8 | ~$2.50 |
| **Entradas** | 7 | ~$1.50 |
| **Conectores** | 12 | ~$3.00 |
| **Pasivos (R/C/D)** | 35+ | ~$2.00 |
| **Mecánicos** | 4 | ~$0.50 |
| **TOTAL** | ~82 | **~$20.50** |

> Precios orientativos (cantidades 1-10, proveedores chinos). PCB no incluido.

## BOM Detallada

### MCU y Socket

| Ref | Cantidad | Valor/PN | Footprint | Descripción | Datasheet |
|-----|---|---|---|---|---|
| U_ESP32 | 1 | ESP32-DevKitC-V4 | ESP32-DevKitC (custom) | Módulo ESP32-WROOM-32E | [PDF](https://www.espressif.com/sites/default/files/documentation/esp32-wroom-32e_esp32-wrover-32e_datasheet_en.pdf) |
| J_ESP32 | 2 | Header 2×19 F | Header_2x19_F | Socket hembra para DevKit | - |

### Reguladores de voltaje

| Ref | Cantidad | Valor/PN | Footprint | Descripción | Datasheet |
|-----|---|---|---|---|---|
| U_5V | 1 | LM7805CT | TO-220-3_Vertical | Regulador lineal 5V 1.5A | [PDF](../datasheets/LM7805.pdf) |
| U_3V3 | 1 | AMS1117-3.3 | SOT-223 | Regulador lineal 3.3V 800mA | [PDF](../datasheets/AMS1117.pdf) |
| D_PWR | 1 | 1N5819 | SOD-123 | Diodo Schottky 1A 40V (protección) | - |
| LED_5V | 1 | LED 3mm Red | LED_THT_3mm | Indicador 5V | - |
| LED_3V3 | 1 | LED 3mm Green | LED_THT_3mm | Indicador 3.3V | - |
| R_LED5V | 1 | 1kΩ | R_Axial_0207 | Limitación LED 5V | - |
| R_LED3V3 | 1 | 1kΩ | R_Axial_0207 | Limitación LED 3.3V | - |
| C_IN_5V | 1 | 470µF 25V | Cap_THT_D8 | Bulk input LM7805 | - |
| C_IN_5V_S | 1 | 100nF | C_0805 | Decoupling input | - |
| C_OUT_5V | 1 | 100µF 10V | Cap_THT_D6 | Bulk output 5V | - |
| C_OUT_5V_S | 1 | 100nF | C_0805 | Decoupling output | - |
| C_OUT_3V3 | 1 | 100µF 6.3V | Cap_THT_D6 | Bulk output 3.3V | - |
| C_OUT_3V3_S | 1 | 100nF | C_0805 | Decoupling output | - |
| JP_PWR | 1 | Jumper 2p | Jumper_2p | Selección Jack/USB | - |

### Monitor de corriente

| Ref | Cantidad | Valor/PN | Footprint | Descripción | Datasheet |
|-----|---|---|---|---|---|
| U_IMON | 1 | A9013 | SIP-3 | Sensor Hall 400mV/A | - |
| C_IMON | 1 | 100nF | C_0805 | Decoupling VCC | - |
| R_IMON | 1 | 10kΩ | R_0805 | Pull-down salida | - |

### Driver Motor MX1508

| Ref | Cantidad | Valor/PN | Footprint | Descripción | Datasheet |
|-----|---|---|---|---|---|
| U_MOT | 1 | MX1508 | MX1508_SOP8 (custom) | Dual H-Bridge 1.5A | [PDF](../datasheets/MX1515H_C5119046.pdf) |
| C_MOT_VM | 1 | 100µF 16V | Cap_THT_D6 | Bulk VM motor | - |
| C_MOT_VM_S | 1 | 100nF | C_0805 | Decoupling VM | - |
| C_MOT_VCC | 1 | 10µF 10V | C_0805 | Decoupling VCC logic | - |
| D_MOT_FLY | 4 | 1N5819 | SOD-123 | Flyback diodes (integradas en MX1508) | - |

### Sensores

| Ref | Cantidad | Valor/PN | Footprint | Descripción | Datasheet |
|-----|---|---|---|---|---|
| U_TEMP1 | 1 | DS18B20 | TO-92 / Waterproof probe | Temp digital 1-Wire | [PDF](https://datasheets.maximintegrated.com/en/ds/DS18B20.pdf) |
| U_TEMP2 | 1 | LM35DZ | TO-92 | Temp analógica 10mV/°C | [PDF](https://www.ti.com/lit/ds/symlink/lm35.pdf) |
| R_DS18B20 | 1 | 4.7kΩ | R_Axial_0207 | Pull-up 1-Wire | - |
| U_LDR | 1 | GL5528 / genérico | LDR_5mm | Fotoresistor | - |
| R_LDR | 1 | 10kΩ | R_Axial_0207 | Divisor tensión LDR | - |
| C_LDR | 1 | 100nF | C_0805 | Filtro ruido ADC | - |

### Actuadores

| Ref | Cantidad | Valor/PN | Footprint | Descripción | Datasheet |
|-----|---|---|---|---|---|
| BZ1 | 1 | Buzzer pasivo 5V | Buzzer_THT_12mm | Buzzer piezoeléctrico | [PDF](../datasheets/SS-12D1305-G2.PDF) |
| LED_USR1 | 1 | LED 3mm Red | LED_THT_3mm | Usuario GPIO0 | - |
| LED_USR2 | 1 | LED 3mm Blue | LED_THT_3mm | Usuario GPIO2/Built-in | - |
| LED_USR3 | 1 | LED 3mm Green | LED_THT_3mm | Usuario GPIO4 | - |
| LED_USR4 | 1 | LED 3mm Yellow | LED_THT_3mm | Usuario GPIO5 | - |
| LED_RGB | 1 | WS2812B 5050 | LED_SMD_5050 | LED RGB direccionable | - |
| R_LED_USR | 4 | 330Ω | R_Axial_0207 | Limitación LEDs usuario | - |
| C_RGB | 1 | 100nF | C_0805 | Decoupling WS2812B | - |
| J_SERVO | 1 | Header 3p M | Header_3p_M | Conector servo estándar | - |

### Entradas

| Ref | Cantidad | Valor/PN | Footprint | Descripción | Datasheet |
|-----|---|---|---|---|---|
| SW_DIP | 1 | DIP Switch 4pos | SW_DIP_4 | 4 switches configurables | [PDF](../datasheets/SS12D00.pdf) |
| SW_PUSH | 1 | Push button 6×6mm | SW_Push_6x6 | Botón momentáneo | - |
| SW_SPDT | 1 | SPDT Slide Switch | SS-12D13 | Switch deslizante 3 pos | [PDF](../datasheets/SS-12D1305-G2.PDF) |
| RV_POT | 1 | Potenciómetro 10k | Pot_THT_B10K | Potenciómetro lineal | [PDF](../datasheets/POTENTIOMETER_Trim_THT.step) |
| R_PU_DIP | 4 | 10kΩ | R_0805 | Pull-up DIP (opcional, usar interno) | - |

### Conectores

| Ref | Cantidad | Valor/PN | Footprint | Descripción |
|-----|---|---|---|---|
| J_PWR | 1 | Jack DC 2.1mm | PJ-002AH | Entrada 7-12V |
| J_USB | 1 | USB Micro-B | USB_Micro_B | Solo 5V (via diodo) |
| J_TERM | 1 | Terminal Block 4p | Terminal_Block_4p | Motor power out |
| J_ESP32_A | 1 | Header 2×19 M | Header_2x19_M | Socket ESP32 parte 1 |
| J_ESP32_B | 1 | Header 2×19 M | Header_2x19_M | Socket ESP32 parte 2 |
| J_SERVO | 1 | Header 3p M | Header_3p_M | Servo signal/VCC/GND |
| J_I2C | 1 | Header 4p M | Header_4p_M | Expansión I2C |
| J_SPI | 1 | Header 6p M | Header_6p_M | Expansión SPI |
| J_GPIO | 1 | Header 10p M | Header_10p_M | GPIO extra |
| MH1-MH4 | 4 | Mounting Hole M3 | MountingHole_3.2mm | Tornillos M3 |

### Pasivos generales (resumen)

| Tipo | Cantidad | Valores típicos |
|---|---|---|
| **Resistencias 0805** | 20+ | 10k, 4.7k, 1k, 330Ω, 100Ω |
| **Resistencias Axial** | 10+ | 1k, 330Ω, 4.7k, 10k |
| **Capacitores 0805** | 15+ | 100nF, 10µF, 1µF |
| **Capacitores THT** | 8+ | 470µF, 100µF, 10µF |
| **Diodos SOD-123** | 5+ | 1N5819 |

## Footprints personalizados

| Nombre | Ubicación | Descripción |
|---|---|---|
| `ESP32-DevKitC` | `assets/ESP32-DEVKIT-V1/ESP32-DEVKIT-V1.mod` | Socket 2×19 para DevKit V4 |
| `MX1508_SOP8` | `MX1508.kicad_mod` | Driver motor SOP-8 con pad térmico |
| `Logo_X` | `logo_footprint/logo_x.kicad_mod` | Logo Xizuth en silkscreen |
| `QR_Code` | `logo_footprint/qr.kicad_mod` | QR código GitHub |

## Símbolos personalizados

| Nombre | Ubicación | Descripción |
|---|---|---|
| `ESP32-DevKitC` | `assets/ESP32-DEVKIT-V1/ESP32-DevKitC.kicad_sym` | Símbolo socket DevKit |
| `MX1508` | `MX1508.kicad_sym` | Símbolo driver motor |

## Notas de montaje

1. **Orden recomendado**: Pasivos SMD → ICs SMD → THT bajos → THT altos → Conectores → Módulo ESP32
2. **LM7805**: Montar con disipador o usar pista cobre como heatsink (4 vias térmicas)
3. **MX1508**: Soldar pad térmico expuesto a polygon VCC_MOTOR + vias a GND
4. **ESP32**: Insertar al final, verificar orientación (antena hacia borde PCB)
5. **DS18B20**: Versión TO-92 en PCB o sonda waterproof por cables
6. **Terminal Block**: Apriete moderado, verificar continuidad
7. **Mounting holes**: Usar spacers M3 nylon para evitar cortos

## Proveedores sugeridos

| Componente | LCSC | Mouser | DigiKey | AliExpress |
|---|---|---|---|---|
| ESP32 DevKit V4 | ✅ | ✅ | ✅ | ✅ |
| LM7805CT | ✅ | ✅ | ✅ | ✅ |
| AMS1117-3.3 | ✅ | ✅ | ✅ | ✅ |
| MX1508 | ✅ | ❌ | ❌ | ✅ |
| DS18B20 | ✅ | ✅ | ✅ | ✅ |
| LM35DZ | ✅ | ✅ | ✅ | ✅ |
| WS2812B | ✅ | ✅ | ✅ | ✅ |
| Conectores/THT | ✅ | ✅ | ✅ | ✅ |

## Archivos BOM exportables

- `fabricacion/bom.csv` - CSV para JLCPCB/PCBWay
- `fabricacion/bom.xlsx` - Excel con columnas extra
- `fabricacion/pnp.csv` - Pick&Place para SMT

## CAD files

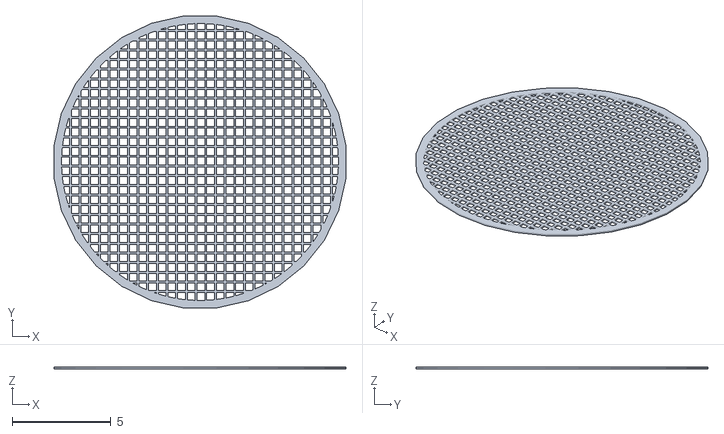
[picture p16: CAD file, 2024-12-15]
models/hc-sr04-13.snapshot.2/hc-sr04-gmesh.stl
14.8 x 14.8 x 0.1

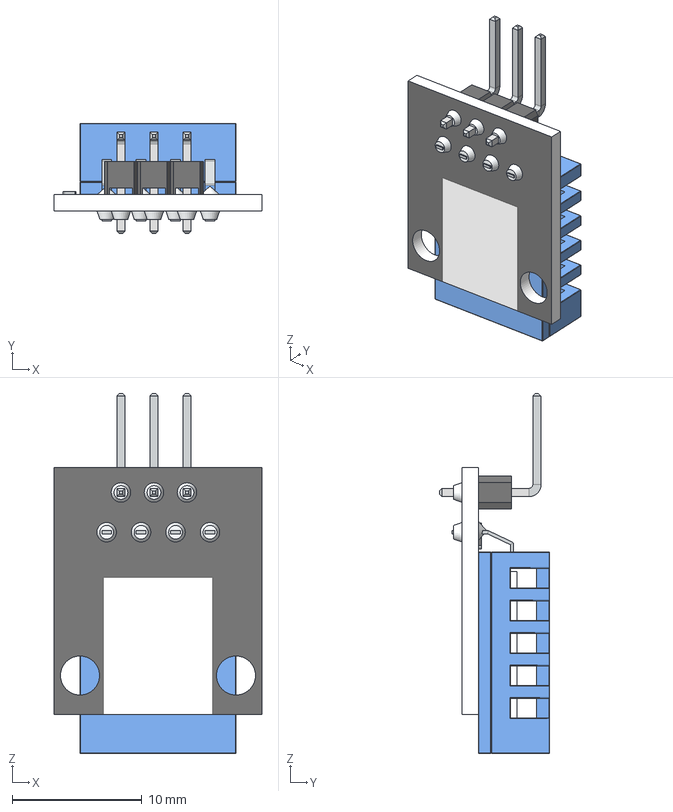
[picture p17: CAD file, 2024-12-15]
models/KY-015.step
16.0 x 8.50 x 27.7 mm

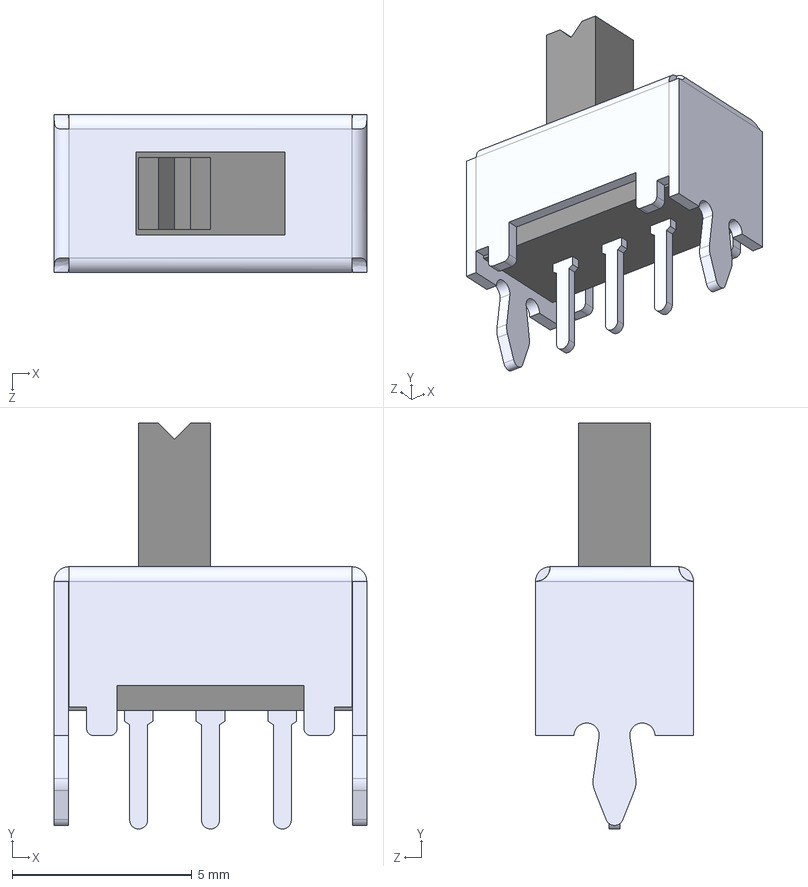
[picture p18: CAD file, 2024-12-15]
models/mini_switch_slider.STEP
8.70 x 11.3 x 4.40 mm

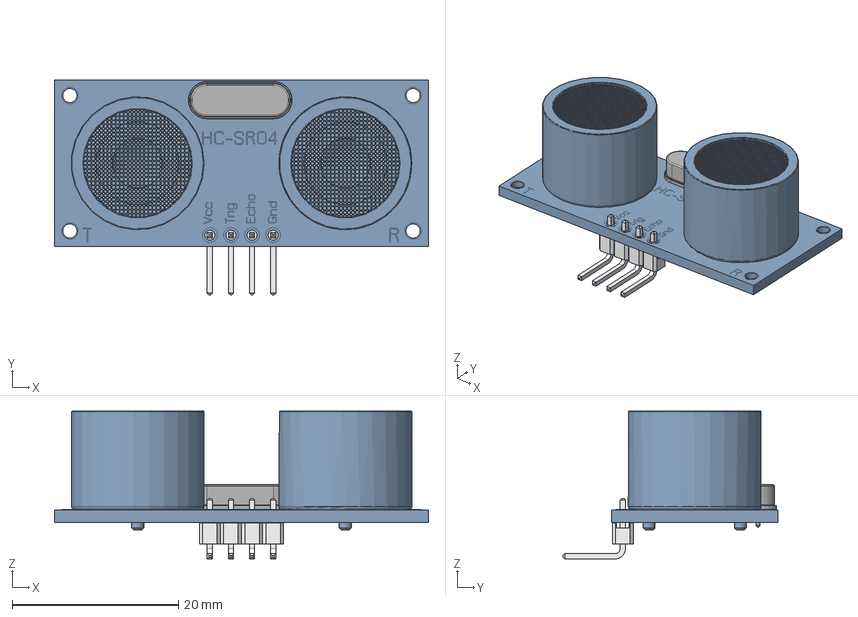
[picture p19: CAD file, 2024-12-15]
models/hc-sr04-13.snapshot.2/HC_SR04.FCStd
45.0 x 25.8 x 17.8 mm
Quarz
Platine
Pins_4fach_90Grad_001
HC_SR04_gitter_001
HC_SR04_gitter_002

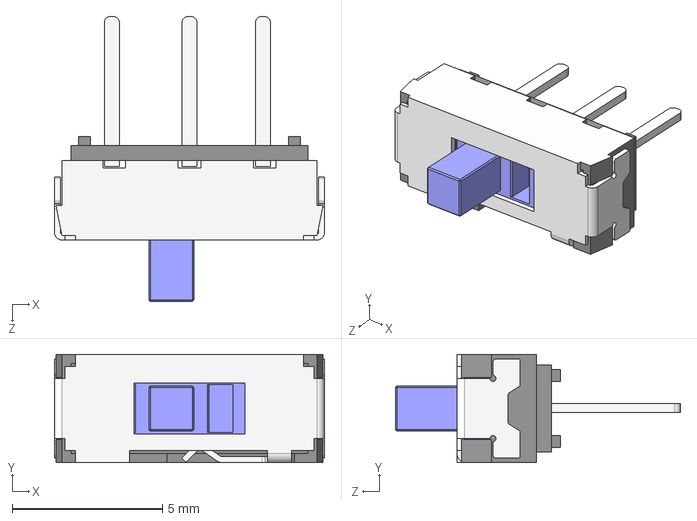
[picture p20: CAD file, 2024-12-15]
models/micro_switch_slider.STEP
9.00 x 3.60 x 9.50 mm

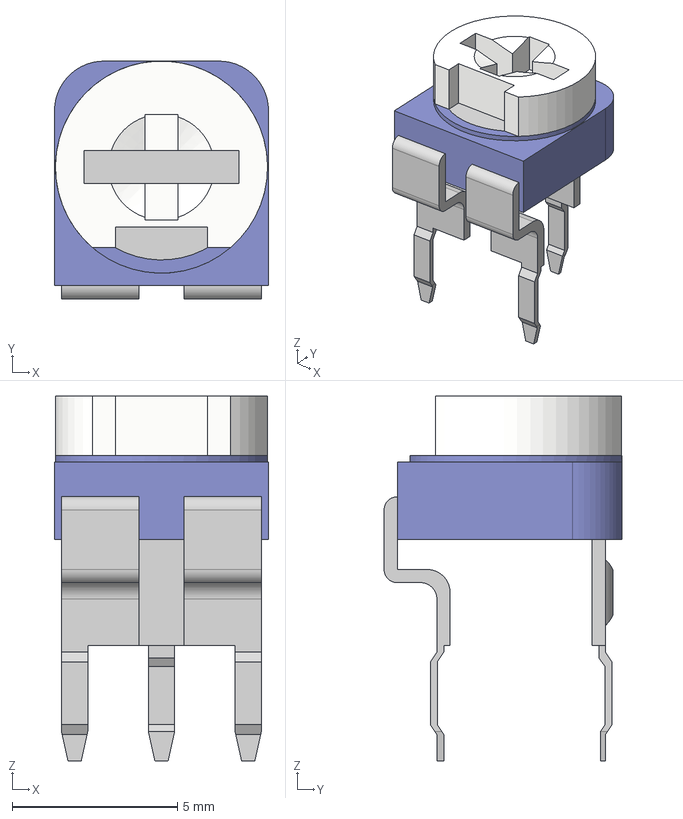
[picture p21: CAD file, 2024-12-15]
models/Potentiometer_Trim_THT.step
6.48 x 7.20 x 11.1 mm

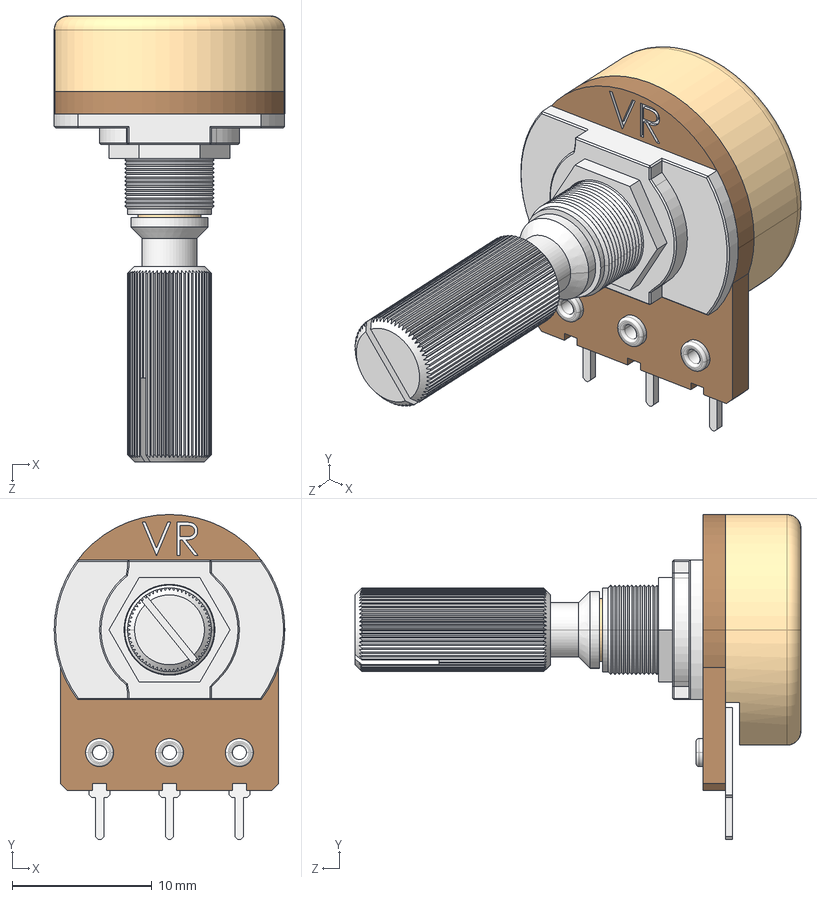
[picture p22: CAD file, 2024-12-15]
models/POTENTIOMETER.STEP
16.5 x 23.2 x 31.9 mm

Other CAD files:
models/hc-sr04-13.snapshot.2/hc-sr04-gmesh-r.stl
models/hc-sr04-13.snapshot.2/HC_SR04_gitter.FCStd

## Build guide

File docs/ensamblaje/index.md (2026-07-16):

# Ensamblaje - Visión general

## Herramientas necesarias

| Herramienta | Especificación | Imprescindible |
|---|---|---|
| **Soldador** | Punta fina 0.5-1mm, 40-60W control temp | ✅ |
| **Estaño** | Sn63/Pb37 o SAC305, 0.5-0.8mm, flux core | ✅ |
| **Flux** | Pasta o líquido (no-corrosivo) | ✅ |
| **Pinzas** | Puntas finas ESD-safe | ✅ |
| **Lupa/Visor** | 5-10x o microscopio USB | ✅ |
| **Multímetro** | Continuidad, voltaje, resistencia | ✅ |
| **Desoldador** | Bomba o malla desoldar | Recomendado |
| **Alicates corte** | Micro-corte flush | Recomendado |
| **Third hand** | Con lupa integrada | Útil |

## Componentes - Qué necesitas

Ver [Lista completa (BOM)](../hardware/componentes.md) con referencias y proveedores.

**Kits por nivel:**
| Nivel | Incluye | Coste aprox |
|---|---|---|
| **Básico** | Solo pasivos + headers + reguladores | ~$8 |
| **Completo** | Básico + sensores + actuadores + ESP32 | ~$25 |
| **Full** | Completo + MX1508 + WS2812B + servo | ~$30 |

## Orden de soldadura recomendado

```
1. Componentes SMD pequeños (0805, 0603, SOD-123, SOT-223)
   ├─ Resistencias 0805/0603
   ├─ Capacitores 0805
   ├─ Diodos SOD-123 (1N5819)
   └─ ICs SMD: AMS1117 (SOT-223), MX1508 (SOP-8)

2. Componentes THT bajos
   ├─ Headers hembra 2x19 (socket ESP32)
   ├─ Headers macho 2x19, 3p, 4p, 6p, 10p
   ├─ Terminal block 4p
   ├─ Jack DC 2.1mm
   ├─ USB Micro-B
   ├─ Switches DIP, Push, SPDT
   ├─ Potenciómetro 10k
   ├─ Buzzer
   ├─ LEDs 3mm (×4)
   └─ DS18B20 (TO-92) / LM35 (TO-92)

3. Componentes THT altos / gruesos
   ├─ LM7805 TO-220 (con disipador)
   ├─ Capacitores electrolíticos (470µF, 100µF)
   └─ Conector servo 3p

4. Módulo ESP32 DevKit V4
   └─ Insertar en socket hembra (ÚLTIMO)

5. Verificación y test
```

## Técnicas de soldadura

### SMD (0805, 0603, SOT-223, SOP-8)
1. **Flux** en pads
2. **Estañar un pad** (esquina)
3. **Posicionar componente** con pinzas
4. **Soldar pin esquina** (sujeta componente)
4. **Soldar resto pines** (arrastrar estaño)
5. **Inspeccionar** lupa: sin puentes, buena mojado

### THT (Through-Hole)
1. **Insertar componente** (doblar patillas si necesario)
2. **Voltear PCB**, apoyar en third-hand
3. **Calentar pad + pata** 2-3s
4. **Aplicar estaño** en unión (no en punta)
5. **Retirar estaño, luego soldador**
6. **Recortar patillas** flush cutters

### ICs sensibles (ESD)
- **Pulsera antiestática** o tocar metal antes
- **No tocar pines** directamente
- **Socket hembra** para ESP32 (no soldar directo)

## Puntos críticos PCB v0.4

| Componente | Cuidado |
|---|---|
| **MX1508 (U_MOT)** | Pad térmico expuesto → Soldar a polygon VCC_MOTOR + vias a GND |
| **AMS1117 (U_3V3)** | SOT-223 - Pin 2 (GND/Tab) soldar bien a GND pour |
| **LM7805 (U_5V)** | TO-220 - Disipador + pasta térmica + 4 vias térmicas |
| **Socket ESP32 (J1, J2)** | 2x19 pines - Alinear perfecto antes de soldar |
| **A9013 (U_IMON)** | SIP-3 - Orientación correcta (marca en silkscreen) |
| **WS2812B (LED_RGB)** | 5050 SMD - Orientación (esquina cortada = GND) |
| **DIP Switch** | 4 posiciones - Pin 1 marcado en silkscreen |

## Verificación post-soldadura

### 1. Inspección visual (Lupa 10x)
- [ ] Sin puentes de estaño (shorts)
- [ ] Sin soldaduras frías (grisáceas, rugosas)
- [ ] Todos los pines mojados (brillante, cóncavo)
- [ ] Componentes polarizados correctos (LED, Diode, Electro, IC)
- [ ] Sin patillas sueltas / components tombstoning

### 2. Continuidad / Cortos (Multímetro)
```
☐ GND ↔ +5V Rail (debe ser OL / >1MΩ)
☐ GND ↔ +3.3V Rail (debe ser OL)
☐ +5V ↔ +3.3V (debe ser OL)
☐ GND pins headers ↔ GND plane (0Ω)
☐ VIN Jack → LM7805 IN (0Ω)
☐ LM7805 OUT → +5V Rail (0Ω)
☐ AMS1117 OUT → +3.3V Rail (0Ω)
☐ ESP32 Socket GND pins → GND (0Ω)
☐ ESP32 Socket 3V3 pins → +3.3V (0Ω)
```

### 3. Pruebas alimentación (SIN ESP32 insertado)
```
☐ Conectar Jack 9-12V → LED 5V ON, LED 3.3V ON
☐ Medir +5V Rail: 4.9-5.1V
☐ Medir +3.3V Rail: 3.25-3.35V
☐ Conectar USB 5V (sin Jack) → LEDs ON
☐ Medir corrientes reposo: +5V < 50mA, +3.3V < 80mA
```

### 4. Test con ESP32
```
☐ Insertar ESP32 DevKit V4 en socket (orientación: USB hacia borde)
☐ Conectar USB a PC → PC detecta COM port
☐ Subir sketch "Blink" → LED D1 (GPIO0) parpadea
☐ Serial Monitor 115200 → "Hello ESP32"
☐ Test WiFi: Scan networks → Lista redes
```

### 5. Test periféricos (sketch test_all.ino)
```
☐ LED D1-D4: Blink sequence
☐ RGB: Rainbow cycle
☐ Buzzer: Tone sweep
☐ Botón: Serial "BTN Press"
☐ DIP: Leer 4 bits
☐ SPDT: Leer posición
☐ Potenciómetro: 0-4095 serial
☐ DS18B20: Temp °C
☐ LM35: Temp °C
☐ LDR: Valor luz
☐ Motor A/B: Forward/Reverse PWM
☐ Servo: Sweep 0-180
☐ A9013: Corriente reposo ~0A
```

## Solución problemas comunes

| Síntoma | Causa probable | Solución |
|---|---|---|
| LED 5V no enciende | LM7805 mal soldado / sin Vin | Revisar continuidad Jack→LM7805 IN, LM7805 OUT→+5V |
| LED 3.3V no enciende | AMS1117 mal soldado | Revisar pin 2 (Tab/GND), pin 3 (OUT) |
| ESP32 no detectado | Socket mal soldado / pines doblados | Revisar continuidad socket→pads, enderezar pines |
| Motor no gira | MX1508 pad térmico no soldado | Soldar pad central a polygon, verificar VM/VCC |
| Lecturas ADC ruidosas | Falta capacitor decoupling | Verificar 100nF cerca cada IC, 100nF en ADC inputs |
| Buzzer no suena | GPIO25 conflict / pin wrong | Verificar GPIO25 no usado por otra cosa |
| Servo vibra/no mueve | Alimentación 3.3V / PWM wrong | Verificar VCC=5V, PIN=18, 50Hz |

## Tips pro

1. **Flux is your friend** - Usa flux generosamente en SMD
2. **Solda todo SMD primero** - Antes de THT (acceso fácil)
3. **Socket ESP32** - Nunca sueldes el DevKit directo
4. **LM7805** - Montar con disipador ANTES de soldar (tornillo M3)
5. **Fotos** - Toma fotos a cada paso para referencia futura
6. **Test incremental** - Verifica cada rail antes de seguir

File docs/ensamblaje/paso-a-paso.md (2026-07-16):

# Ensamblaje - Paso a paso

## Sesión 1: SMD (30-45 min)

### 1.1 Preparación
- [ ] PCB limpia (alcohol IPA)
- [ ] Flux aplicado en pads SMD
- [ ] Componentes SMD organizados en cinta/bandeja
- [ ] Soldador 350°C (leaded) / 380°C (lead-free)

### 1.2 Resistencias 0805/0603
```
Orden sugerido (por zona PCB):
1. R_LED_USR (x4) - 330Ω cerca LEDs
2. R_LED_PWR (x2) - 1kΩ cerca LEDs power
3. R_IMON - 10kΩ cerca A9013
4. R_PU_DIP (x4) - 10kΩ cerca DIP switch
5. R_LDR - 10kΩ cerca LDR
6. R_DS18B20 - 4.7kΩ cerca DS18B20
7. Resto 0805 (decoupling cerca ICs)
```

### 1.3 Capacitores 0805
```
1. C_DEC_* (100nF) - Cerca de cada IC (prioridad)
2. C_MOT_VCC, C_RGB, C_LDR, C_IMON
3. Resto decoupling
```

### 1.4 Diodos SOD-123 (1N5819 x3)
```
Marcas en silkscreen: cátodo = raya
D_PWR: Jack → LM7805 (orientación: raya hacia LM7805)
D_PROT: USB → ORing (raya hacia ORing)
D_DISC: LM7805 OUT → IN (raya hacia IN)
```

### 1.5 ICs SMD
```
1. U_3V3 (AMS1117 SOT-223)
   - Pin 2 (Tab grande) = GND → Soldar bien a GND pour
   
2. U_MOT (MX1508 SOP-8)
   - Pad central térmico → Soldar a VCC_MOTOR polygon + vias GND
   - Pin 1 = marca punto/muesca
   
3. U_IMON (A9013 SIP-3)
   - 3 pines en línea
   - Marca en silkscreen indica pin 1 (VCC)
```

### 1.6 LED RGB WS2812B (5050)
```
- Esquina cortada = GND (pin 4)
- Orientar según silkscreen (marca esquina)
- Flux generoso en 4 pads
- Soldar 2 esquinas opuestas primero
```

---

## Sesión 2: THT Bajo perfil (45-60 min)

### 2.1 Socket ESP32 (J1, J2 - 2x19 hembra)
```
CRÍTICO: Alineación perfecta

1. Insertar socket en breadboard (2 breadboards paralelos)
2. Colocar PCB encima (pads atraviesan socket)
3. Presionar firmemente - socket plano contra PCB
4. Soldar 1 pin esquina → Verificar perpendicular
5. Soldar pin opuesto → Verificar
6. Soldar resto (38 pines total)
7. Continuidad: cada pin socket → pad PCB
```

### 2.2 Headers macho (2x19, 3p, 4p, 6p, 10p)
```
Mismo truco: Header en breadboard → PCB encima → Soldar
- J_ESP32_A (2x19) - ya en socket hembra
- J_ESP32_B (2x19) - ya en socket hembra  
- J_SERVO (3p)
- J_I2C (4p)
- J_SPI (6p)
- J_GPIO (10p)
```

### 2.3 Switches
```
SW_DIP (4 pos): Pin 1 marcado → hacia GPIO27
SW_PUSH (6x6): 4 patas, 2 pares internos
SW_SPDT: 3 patas, pin central = COM
```

### 2.4 Potenciómetro
```
RV_POT (B10K): 3 patas, cuerpo redondo
- Pata central = wiper → GPIO34
- Laterales = 3.3V y GND
```

### 2.5 Buzzer
```
BZ1: 2 patas, sin polaridad
- Pata + hacia GPIO25 (marca + en silkscreen)
```

### 2.6 LEDs 3mm (D1-D4)
```
Polaridad: Pata larga = Ánodo (+) → GPIO
           Pata corta / lado plano = Cátodo (-) → GND via R
D1 (Rojo) → GPIO0
D2 (Azul) → GPIO2  
D3 (Verde) → GPIO4
D4 (Amarillo) → GPIO5
```

---

## Sesión 3: THT Alto / Potencia (30 min)

### 3.1 LM7805 TO-220 (U_5V)
```
1. Montar disipador ANTES de soldar
   - Tornillo M3 + tuerca + pasta térmica
   - Disipador hacia arriba (fuera PCB)
   
2. Insertar LM7805 (patilla central = GND = Tab)
3. Soldar 3 patas
4. Verificar: Tab → GND plane (continuidad)
```

### 3.2 Capacitores electrolíticos
```
C_IN_5V (470µF 25V): Cerca Jack DC → LM7805 IN
C_OUT_5V (100µF 10V): Cerca LM7805 OUT
C_OUT_3V3 (100µF 6.3V): Cerca AMS1117 OUT
C_MOT_VM (100µF 16V): Cerca MX1508 VM

¡POLARIDAD! Raya = Negativo = Corto
```

### 3.3 Conectores potencia
```
J_PWR (Jack DC 2.1mm): 3 patas, una central +, laterales GND
J_USB (Micro-B): 5 patas, soldar bien carcasa (GND/shield)
J_TERM (Terminal block 4p): Tornillos arriba, pines atraviesan
```

### 3.4 Sensores TO-92
```
DS18B20 (U_TEMP1): Cara plana → según silkscreen
LM35 (U_TEMP2): Cara plana → según silkscreen
- Dejar 5-10mm altura (no pegar a PCB) para aire
```

### 3.5 Mounting holes + Separadores
```
MH1-MH4: 4 agujeros M3
- Solo plated holes (sin componente)
- Usar para atornillar separadores M3x10mm nylon
- Separadores = pies + aislamiento mesa
```

---

## Sesión 4: Inserción ESP32 + Test (15 min)

### 4.1 Insertar ESP32 DevKit V4
```
ORIENTACIÓN: Conector USB hacia BORDE EXTERNO PCB
(Antenna WiFi hacia fuera)

1. Alinear pines ESP32 con sockets hembra
2. Presionar firmemente uniforme
3. Verificar: Sin pines doblados, todo insertado
```

### 4.2 Test rápido alimentación
```
1. Conectar USB a PC
   → LED 5V (Rojo) ON
   → LED 3.3V (Verde) ON
   → PC detecta puerto COM
   
2. Medir con multímetro:
   +5V Rail: 4.9-5.1V
   +3.3V Rail: 3.25-3.35V
   GND: 0V referencias
```

### 4.3 Subir firmware test
```
Archivo: test_all.ino (ver verificacion.md)

1. Arduino IDE → Board: ESP32 Dev Module
2. Port: COMx (el nuevo)
3. Upload
4. Serial Monitor 115200
5. Verificar cada test pasa
```

---

## Checklist final

### Visual
- [ ] Sin puentes estaño
- [ ] Sin soldaduras frías
- [ ] Componentes polarizados correctos
- [ ] ESP32 orientación correcta
- [ ] Disipador LM7805 puesto
- [ ] Separadores M3 atornillados

### Eléctrico
- [ ] GND ↔ +5V: OL
- [ ] GND ↔ +3.3V: OL
- [ ] +5V ↔ +3.3V: OL
- [ ] +5V Rail: 5V ±0.1V
- [ ] +3.3V Rail: 3.3V ±0.05V
- [ ] Corriente reposo +5V: <50mA
- [ ] Corriente reposo +3.3V: <80mA

### Funcional
- [ ] PC detecta ESP32
- [ ] Blink LED D1 funciona
- [ ] WiFi scan redes
- [ ] Test_all.ino: Todo PASS

---

## Tiempo estimado total

| Sesión | Tiempo | Dificultad |
|---|---|---|
| 1. SMD | 30-45 min | Media |
| 2. THT Bajo | 45-60 min | Baja |
| 3. THT Potencia | 30 min | Media |
| 4. Test + ESP32 | 15 min | Baja |
| **TOTAL** | **2-2.5 horas** | - |

> **Principiante**: Duplicar tiempos. Hacer en 2-3 sesiones separadas.

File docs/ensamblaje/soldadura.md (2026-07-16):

# Ensamblaje - Técnicas de soldadura

## Soldadura SMD (0805, 0603, SOT-223, SOP-8)

### Preparación
```
1. Limpiar pads con alcohol isopropílico 99%
2. Aplicar FLUX (pasta o lápiz) en TODOS los pads
3. Pre-calentar placa 50-80°C (opcional, ayuda mojado)
```

### Pasos genéricos (Chip resistor/capacitor 0805/0603)
```
1. Estañar UN pad (preferiblemente esquina GND/negativo)
   - Punta limpia + poco estaño → pad
   
2. Posicionar componente con pinzas
   - Orientación correcta (polaridad si aplica)
   - Centrado en pads
   
3. Soldar pad estañado
   - Calentar pad + pata componente 2-3s
   - Retirar soldador, dejar enfriar 1s
   - Componente ya sujeto
   
4. Soldar pines restantes
   - Arrastrar estaño desde pad a pata
   - 1-2s por pin
   - No calentar excesivamente
   
5. Inspeccionar
   - Filete cóncavo, brillante, sin puentes
   - Componente plano contra PCB
```

### ICs SMD (SOT-223, SOP-8, etc.)
```
1. Flux generoso en todos los pads
2. Estañar pad esquina (pin 1 o GND)
3. Alinear IC (pin 1 = marca punto/muesca)
4. Soldar pin 1 → Sujeta IC
5. Soldar pin opuesto (esquina diagonal) → Alinea
6. Soldar resto pines (arrastrar estaño)
7. Revisar puentes entre pines adyacentes
   - Si hay puente: malla desoldar + flux + repasar
```

### Pad térmico expuesto (MX1508, AMS1117)
```
MX1508 (SOP-8 con pad central):
- Pad central = GND / térmico
- Debe soldar a polygon GND en bottom + vias
- Técnica: Estañar pad PCB → Flux → Posicionar IC → 
  Calentar desde abajo (placa caliente) o soldador grueso en pad
  + flux → Soldar pines laterales normal

AMS1117 (SOT-223, pin 2 = Tab = GND):
- Pin 2 grande = disipador
- Soldar bien a GND pour top + bottom + vias
- Calentar pin 2 más tiempo (masa térmica)
```

---

## Soldadura THT (Through-Hole)

### Componentes axiales (Resistencias, diodos, LEDs)
```
1. Doblar patillas a 90° (usar plantilla o alicates)
2. Insertar en PCB (cuerpo pegado a silkscreen)
3. Doblar ligeramente patillas hacia afuera (sujeta)
4. Voltear PCB
5. Calentar pad + pata 2-3s
6. Aplicar estaño en unión (no en punta)
7. Retirar estaño, luego soldador
8. Cortar patillas flush (1-2mm)
```

### Electrolíticos radiales
```
1. Identificar polaridad (raya negativa = cátodo)
2. Insertar (positivo = pata larga / marca +)
3. Mismo proceso THT
4. ¡No invertir! Explota / cortocircuito
```

### Conectores (Headers, Jack, USB, Terminal Block)
```
1. Insertar en PCB
2. Para headers: Usar breadboard o otro header como guía
   - Insertar header en breadboard → colocar PCB encima → soldar
   - Garantiza perpendicularidad y alineación
3. Jack DC / USB: Sujetar con cinta kapton o third-hand
4. Soldar 1 pin → revisar alineación → soldar resto
5. Terminal block: Soldar 1 pin → verificar orientación → resto
```

### ICs en Socket (ESP32 DevKit)
```
1. SOLDAR SOCKET HEMBRA (no el ESP32 directo)
2. Usar breadboard como guía para alinear 2x19
3. Soldar 1 pin esquina → revisar → soldar opuesto → resto
4. Verificar continuidad cada pin socket → pad PCB
5. INSERTAR ESP32 al final (orientación: USB hacia borde PCB)
```

---

## Perfiles de temperatura (Referencia)

### Estaño Sn63/Pb37 (Leaded - recomendado hobby)
| Fase | Temp | Tiempo |
|---|---|---|
| Precalentamiento | 100-150°C | 60-120s |
| Activación flux | 150-180°C | 30-60s |
| Refusión (pico) | 215-225°C | 15-30s |
| Enfriamiento | - | 2-4°C/s |

### Estaño SAC305 (Lead-free - RoHS)
| Fase | Temp | Tiempo |
|---|---|---|
| Precalentamiento | 150-180°C | 60-120s |
| Activación flux | 180-210°C | 30-60s |
| Refusión (pico) | 240-250°C | 20-40s |
| Enfriamiento | - | 2-4°C/s |

> **Con soldador manual**: No sigas perfil exacto. Calienta unión 2-3s, estaño fluye, retira. Si humea mucho = demasiado caliente.

---

## Defectos comunes y solución

| Defecto | Aspecto | Causa | Solución |
|---|---|---|---|
| **Puente (Short)** | Estaño une 2+ pads | Exceso estaño / pads cercanos | Malla desoldar + flux + repasar |
| **Soldadura fría** | Gris, rugoso, bola | Poca temp / movimiento al enfriar | Recalentar + flux + dejar quieto |
| **Poca mojado** | Estaño no cubre pad | Pad sucio / sin flux / temp baja | Limpiar + flux + temp adecuada |
| **Tombstoning** | Componente 0805 vertical | Desigual calentamiento pads | Pre-estañar ambos pads igual |
| **Pico/icicla** | Punta estaño afilada | Retirar soldador muy rápido | Retirar estaño, esperar 0.5s, retirar soldador |
| **Pad levantado** | Pad separado de PCB | Exceso calor / fuerza mecánica | Reparar con cable puente / jumper |
| **Componente quemado** | Negro, agrietado | Temp excesiva / tiempo largo | Reemplazar componente |

---

## Seguridad y buenas prácticas

| Regla | Por qué |
|---|---|
| **Ventilación / Extractor** | Humos flux + estaño tóxicos |
| **Gafas seguridad** | Proyecciones estaño caliente |
| **Pulsera antiestática** | ESD mata ICs (ESP32, AMS1117, MX1508) |
| **Punta limpia** | Estaño viejo = mala transferencia calor |
| **Estañar punta** | Previene oxidación, mejora mojado |
| **No tocar patas IC** | Aceite dedos = mala soldadura + ESD |
| **Temperatura controlada** | 350-380°C leaded / 380-420°C lead-free |
| **Apagar soldador** | Si >5min sin usar (ahorra punta) |

---

## Limpieza post-soldadura

```
Opcional pero recomendado para producción:

1. Cepillo suave + Alcohol isopropílico 99%
2. Frotar suavemente residuos flux
3. Secar aire comprimido / secador pelo (frío)
4. Inspección final lupa

No limpiar si:
- Flux "no-clean" (la mayoría modernos)
- Prueba rápida hobby
```

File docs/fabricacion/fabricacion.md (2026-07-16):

# Fabricación - Cómo fabricar y pedir PCBs

## Opciones de fabricación

| Proveedor | Precio 5 uds | Envío ESP | Tiempo total | Calidad | SMT opcional |
|---|---|---|---|---|---|
| **JLCPCB** | ~$2 + $8 envío | 5-10 días | 2-3 sem | Buena | Sí ($8+comp) |
| **PCBWay** | ~$5 + $10 envío | 5-12 días | 2-3 sem | Muy buena | Sí |
| **AISLER** | ~€15 + €8 | 3-5 días | 1-2 sem | Excelente | No |
| **OSH Park** | ~$15 (3 uds) | 2-3 sem | 3-4 sem | Muy buena | No |
| **Eurocircuits** | ~€40 | 5-7 días | 1-2 sem | Profesional | Sí |

> **Recomendación**: JLCPCB para prototipos (precio/calidad), PCBWay para calidad, AISLER para urgencia UE.

---

## Paso a paso: JLCPCB (Recomendado)

### 1. Preparar archivos
```bash
# En KiCad 8/9:
# File → Fabrication Outputs → Gerbers (.gbr)
#   ✓ Plot: F.Cu, B.Cu, F.SilkS, B.SilkS, F.Mask, B.Mask, F.Paste, B.Paste, Edge.Cuts
#   ✓ Use Protel filename extensions
#   ✓ Generate Drill Files: PTH + NPTH, Excellon, mm, decimal format
# File → Fabrication Outputs → BOM / Footprint Position (para SMT)
```

### 2. Subir a JLCPCB
1. Ir a https://jlcpcb.com/quote
2. **Add Gerber file** → Arrastrar `base_esp32_v4.zip`
3. Revisar preview (visor integrado)
4. Configurar:
   ```
   PCB Qty: 5
   Layers: 2
   Thickness: 1.6mm
   Min Track/Space: 0.15/0.15mm
   Min Hole: 0.3mm
   Surface Finish: HASL (Lead Free)
   Solder Mask: Green
   Silkscreen: White
   Via Process: Tented
   Remove Order Number: Yes
   ```

### 3. (Opcional) Ensamblaje SMT
1. Pestaña **SMT Assembly** → **Add SMT**
2. Subir `bom.csv` y `pnp.csv`
3. Revisar componentes:
   - **Confirm** para componentes en librería JLC (Basic/Extended)
   - **Omit** para componentes no disponibles (ESP32 socket, MX1508, conectores THT)
4. Seleccionar **Top side only** (Bottom solo pads THT)

### 4. Pagar y esperar
- Pago: PayPal, tarjeta, transferencia
- Tracking: Email + web
- Tiempo: 2-5 días fabricación + 5-10 días envío estándar

---

## Paso a paso: PCBWay

1. https://www.pcbway.com/orderonline.aspx
2. **Quick-order PCB** → Upload Gerber
3. Mismos parámetros que JLCPCB
4. **Assembly** → Upload BOM + Centroid
5. PCBWay revisa manualmente → Quote en 2-24h
6. Confirmar y pagar

---

## Pedido solo PCB + compra componentes aparte

### Lista compras (LCSC / Mouser / DigiKey)
Ver [BOM completa](../ensamblaje/componentes.md)

**Tip**: Pedir componentes en **LCSC** junto con PCB JLCPCB → Envío combinado, ahorras flete.

### LCSC + JLCPCB (Workflow integrado)
1. En JLCPCB quote → **Parts** → **Add from LCSC**
2. Buscar cada componente por LCSC Part Number
3. **Add to cart** → Se añade a pedido PCB
4. **Combined shipping** → Un solo envío

---

## Fabricación casera (No recomendado para v0.4)

| Método | Viabilidad | Comentario |
|---|---|---|
| **Toner transfer** | ❌ | 2 capas, vias, SMD fino = muy difícil |
| **Fotolitografía** | ⚠️ | Requiere equipo, químicos, experiencia |
| **CNC milling** | ⚠️ | Vías manuales, aislamiento tracks difícil |
| **PCB prototipo FR-1** | ❌ | No aguanta calor LM7805, pistas finas |

> **Conclusión**: Para PCB 2 capas con SMD 0805, SOP-8, vias, pistas 6mil → **Fabricación profesional obligatoria**.

---

## Certificaciones y normativa

| Aspecto | Estándar | Nota |
|---|---|---|
| **RoHS** | 2011/65/EU | HASL-LF, componentes sin plomo |
| **REACH** | 1907/2006 | Sin SVHC en materiales |
| **UL 94V-0** | FR-4 | Autoextinguible |
| **IPC-A-600** | Clase 2 | Calidad estándar comercial |
| **IPC-6012** | Tipo 2 | Rigidez, espesor cobre |

---

## Control de calidad recepción

Al recibir PCBs:
```
1. □ Cantidad correcta (5 + 1-2 spare)
2. □ Dimensiones: 100×80mm ±0.2mm
3. □ Espesor: 1.6mm ±0.1mm
4. □ Bordes: Suaves, sin rebabas, esquinas R2mm
5. □ Agujeros: Mounting M3 (3.2mm), PTH 0.3-1.0mm limpios
6. □ Cobre: Sin rasguños, tracks continuos
7. □ Máscara: Uniforme, sin burbujas, pads expuestos
8. □ Silkscreen: Legible, alineado, sin sobre pads
9. □ Vías: Tentadas (cubiertas mask) o abiertas según spec
9. □ Marcado: UL, fabricante, fecha (lado B)
10. □ Test eléctrico: Continuidad nets críticos (opcional flying probe)
```

---

## Archivos para siguiente revisión (v0.5)

Mantén en repo:
```
fabricacion/
├── gerber_v0.4.zip          # Gerbers v0.4
├── gerber_v0.4_sources/     # Carpeta descomprimida
├── bom_v0.4.csv             # BOM JLCPCB
├── pnp_v0.4.csv             # Pick&Place
├── stackup_v0.4.png         # Captura stackup KiCad
├── drc_report_v0.4.txt      # Reporte DRC
└── quotes/
    ├── jlcpcb_v0.4.pdf
    ├── pcbway_v0.4.pdf
    └── aisler_v0.4.pdf
```

---

## Coste total estimado (v0.4, 5 uds)

| Concepto | JLCPCB | PCBWay | AISLER |
|---|---|---|---|
| PCB 5 uds | $2.00 | $5.00 | €15.00 |
| Envío estándar | $8.00 | $10.00 | €8.00 |
| **Solo PCB** | **$10.00** | **$15.00** | **€23.00** |
| SMT Básico (10 comp) | +$8.00 | +$15.00 | N/A |
| Componentes LCSC | ~$12.00 | ~$12.00 | ~€15.00 |
| **Total completo** | **~$30** | **~$42** | **~€38** |

*Precios 2024, IVA no incluido, envío España peninsular*

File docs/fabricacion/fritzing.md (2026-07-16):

# Fritzing - Visualización y prototipado

## Archivos disponibles

| Archivo | Descripción |
|---|---|
| `base_esp32.fzpz` | Parte completa Fritzing (schematic + PCB + breadboard) |
| `base_esp32.fzp` | Definición parte (XML) |
| `board.svg` | Vista PCB vectorial |
| `breadboard.svg` | Vista protoboard |
| `schematic.svg` | Vista esquemático |
| `board_render_*.png` | Renders 3D (rojo/azul/blanco) |
| `icon.svg` | Icono parte |
| `connector.json` | Definición conectores |
| `artifact_validation.json` | Validación FZ |

---

## Uso en Fritzing

### Importar parte
1. **File → Import → Part** → Seleccionar `base_esp32.fzpz`
2. La parte aparece en **My Parts** (corazón)
3. Arrastrar a vista **Breadboard**, **Schematic** o **PCB**

### Vistas disponibles

#### Breadboard (Prototipado)
```
Conexiones físicas reales:
- ESP32 DevKit en socket
- Componentes sueltos en protoboard
- Cables jumper macho-hembra
- Alimentación USB/Jack visible
```

#### Schematic (Esquemático)
```
Símbolos normalizados:
- ESP32 como MCU genérico (38 pines)
- Reguladores, driver, sensores con símbolos IEC
- Nets etiquetados: +5V, +3V3, GND, GPIOxx
- Anotaciones: valores, referencias
```

#### PCB (Layout)
```
Vista real PCB fabricada:
- Capas: Top/Bottom copper, Silk, Mask
- Footprints exactos (incluye SMD 0805, SOP-8)
- Mounting holes M3
- Edge cuts 100×80mm R2mm
```

---

## Renders 3D

| Archivo | Vista |
|---|---|
| `board_render_red.png` | PCB rojo (máscara roja) |
| `board_render_blue.png` | PCB azul (máscara azul) |
| `board_render_white.png` | PCB blanco |
| `base_esp32_w.png` | Wireframe |

Útiles para:
- Documentación
- Presentaciones
- Verificación visual pre-fabricación

---

## Personalizar parte

### Editar `base_esp32.fzp` (XML)
```xml
<part>
  <title>Base ESP32 DevKit V4</title>
  <description>Training board for ESP32 DevKit V4</description>
  <author>Xizuth</author>
  <date>2024-11-27</date>
  <views>
    <breadboard>breadboard.svg</breadboard>
    <schematic>schematic.svg</schematic>
    <pcb>board.svg</pcb>
  </views>
  <connectors>
    <!-- Definición pines GPIO, power, etc. -->
  </connectors>
  <bus>
    <name>GPIO</name>
    <description>ESP32 GPIOs</description>
  </bus>
</part>
```

### Actualizar SVGs
- **Inkscape** (gratis) para editar `.svg`
- Mantener `viewBox` y IDs de conectores
- `connector*.svg` en `fritzing/` para pines individuales

---

## Exportar para documentación

### Imágenes alta resolución
```
File → Export → as Image
  → Breadboard / Schematic / PCB
  → Resolution: 300 DPI
  → Transparent background: Yes
```

### PDF vectorial
```
File → Export → as PDF
  → Seleccionar vistas
  → Útil para datasheets, manuales
```

---

## Limitaciones conocidas

| Issue | Workaround |
|---|---|
| No simula circuito | Usar SPICE externo (KiCad/Ngspice) |
| Librería SMD limitada | Crear footprints custom SVG |
| No exporta Gerbers | Solo visual - usar KiCad para fabricación |
| Buses parciales | Definir buses en .fzp manualmente |
| No 3D STEP export | Usar KiCad 3D viewer / STEP export |

---

## Integración con KiCad

```
KiCad (Fuente verdad) → Exportar SVG → Fritzing (Visual)
     ↑                                         ↓
     └─────────────── No bidireccional ────────┘
```

**Flujo recomendado**:
1. Diseñar en KiCad (esquemático + PCB)
2. Exportar PCB → SVG (File → Export → SVG)
3. Importar SVG en Fritzing como imagen base
4. Añadir conectores y buses en .fzp
5. Usar Fritzing solo para docs visuales / protoboard

---

## Archivos fuente Fritzing

Ubicación: `/fritzing/` y `/fritzing_out/`

```bash
# Regenerar desde KiCad (si tienes plugin)
# No hay export directo KiCad→Fritzing automático fiable

# Workflow manual:
1. KiCad: Plot → SVG (PCB layers)
2. Inkscape: Limpiar SVG, separar capas
3. Fritzing Parts Editor: Nuevo parte → Importar SVGs
4. Definir conectores (pin mapping ESP32)
5. Guardar .fzpz
```

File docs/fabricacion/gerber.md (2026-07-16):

# Fabricación - Archivos Gerber

## Archivos generados (v0.4)

```
gerber/
├── base_esp32_v4.zip           # Paquete completo para JLCPCB/PCBWay
├── base_esp32-F_Cu.gtl         # Top Copper
├── base_esp32-B_Cu.gbl         # Bottom Copper
├── base_esp32-F_Silkscreen.gto # Top Silkscreen
├── base_esp32-B_Silkscreen.gbo # Bottom Silkscreen
├── base_esp32-F_Mask.gts       # Top Solder Mask
├── base_esp32-B_Mask.gbs       # Bottom Solder Mask
├── base_esp32-F_Paste.gtp      # Top Paste (stencil)
├── base_esp32-B_Paste.gbp      # Bottom Paste (stencil)
├── base_esp32-Edge_Cuts.gm1    # Board Outline
├── base_esp32-PTH.drl          # Plated holes (vias, THT)
├── base_esp32-PTH-drl_map.gbr  # Drill map PTH
├── base_esp32-NPTH.drl         # Non-plated holes (mounting)
├── base_esp32-NPTH-drl_map.gbr # Drill map NPTH
```

## Especificaciones PCB

| Parámetro | Valor | Estándar |
|---|---|---|
| **Dimensiones** | 100mm × 80mm | - |
| **Capas** | 2 | FR-4 |
| **Espesor** | 1.6mm | ±10% |
| **Cobre** | 35µm (1oz) | Interior/exterior |
| **Track min** | 0.15mm (6mil) | 0.15mm estándar |
| **Via min** | 0.3mm / 0.6mm pad | 0.3/0.6mm |
| **Clearance** | 0.15mm (6mil) | 0.15mm |
| **Hole size** | 0.3-3.2mm | PTH/NPTH |
| **Silkscreen** | Blanco | Top + Bottom |
| **Solder Mask** | Verde | Top + Bottom |
| **Finish** | HASL sin plomo / ENIG | HASL-LF estándar |
| **UL** | 94V-0 | FR-4 |

## Capas incluidas en Gerber

| Archivo | Capa KiCad | Descripción |
|---|---|---|
| `*_F_Cu.gtl` | F.Cu | Pistas y pads Top |
| `*_B_Cu.gbl` | B.Cu | Pistas y pads Bottom (GND pour) |
| `*_F_Silkscreen.gto` | F.SilkS | Referencias, polaridad, logos Top |
| `*_B_Silkscreen.gbo` | B.SilkS | Referencias Bottom |
| `*_F_Mask.gts` | F.Mask | Aberturas pads Top |
| `*_B_Mask.gbs` | B.Mask | Aberturas pads Bottom |
| `*_F_Paste.gtp` | F.Paste | Aperturas stencil Top (SMD) |
| `*_B_Paste.gbp` | B.Paste | Aperturas stencil Bottom |
| `*_Edge_Cuts.gm1` | Edge.Cuts | Contorno PCB + mounting holes |
| `*_PTH.drl` | - | Taladros plated (vias, THT pads) |
| `*_NPTH.drl` | - | Taladros non-plated (mounting holes) |

## Visualizador online

Sube `base_esp32_v4.zip` a:
- **JLCPCB**: https://jlcpcb.com/quote (arrastrar zip)
- **PCBWay**: https://www.pcbway.com/orderonline.aspx
- **Gerber Viewer**: https://gerber-viewer.easyeda.com/ o https://www.ucamco.com/en/gerber-viewer

## Pedido típico (JLCPCB)

```
Quantity: 5 (mínimo)
Layers: 2
Dimensions: 100×80mm
PCB Thickness: 1.6mm
Min Track/Space: 0.15/0.15mm
Min Hole: 0.3mm
Surface Finish: HASL (Lead Free)
Solder Mask: Green
Silkscreen: White
Via Process: Tented
Remove Order Number: Yes
```

**Coste aprox**: $2-5 por 5 unidades + envío

## Stencil (opcional, para SMD)

```
Stencil Type: Framed / Frameless
Stencil Thickness: 0.12mm (recomendado 0805/SOP-8)
Stencil Size: 370×470mm (framed) / 150×150mm (frameless)
```

## BOM y Pick&Place (para ensamblaje SMT)

### `fabricacion/bom.csv`
```csv
Designator,Value,Footprint,LCSC Part,Qty
U_ESP32,ESP32-DevKitC-V4,ESP32-DevKitC,C132755,1
U_5V,LM7805CT,TO-220-3_Vertical,C17332,1
U_3V3,AMS1117-3.3,SOT-223-4,C2882143,1
U_MOT,MX1508,MX1508_SOP8,C2882143,1
U_IMON,A9013,SIP-3,C2882143,1
U_TEMP1,DS18B20,TO-92,C17829,1
U_TEMP2,LM35DZ,TO-92,C2882143,1
D_PWR,1N5819,SOD-123,C23272,1
D_PROT,1N5819,SOD-123,C23272,1
D_DISC,1N5819,SOD-123,C23272,1
LED_D1,LED 3mm Red,LED_THT_3mm,C17434,1
LED_D2,LED 3mm Blue,LED_THT_3mm,C17434,1
LED_D3,LED 3mm Green,LED_THT_3mm,C17434,1
LED_D4,LED 3mm Yellow,LED_THT_3mm,C17434,1
LED_RGB,WS2812B,LED_SMD_5050,C2882143,1
BZ1,Buzzer Passive 5V,Buzzer_THT_12mm,C17434,1
SW_DIP,DIP Switch 4pos,SW_DIP_4,C17434,1
SW_PUSH,Push Button 6x6,SW_Push_6x6,C17434,1
SW_SPDT,SPDT Slide,SS-12D13,C17434,1
RV_POT,Pot 10k,Pot_THT_B10K,C17434,1
J_PWR,Jack DC 2.1mm,PJ-002AH,C17434,1
J_USB,USB Micro-B,USB_Micro_B,C17434,1
J_TERM,Terminal Block 4p,Terminal_Block_4p,C17434,1
J_SERVO,Header 3p M,Header_3p_M,C17434,1
J_I2C,Header 4p M,Header_4p_M,C17434,1
J_SPI,Header 6p M,Header_6p_M,C17434,1
J_GPIO,Header 10p M,Header_10p_M,C17434,1
MH1-MH4,Mounting Hole M3,MountingHole_3.2mm,,4
```

### `fabricacion/pnp.csv` (Pick&Place)
```csv
Designator,Footprint,Mid X,Mid Y,Rotation,Layer
U_3V3,SOT-223-4,45.2,32.1,90,Top
U_MOT,MX1508_SOP8,67.8,45.3,0,Top
U_IMON,SIP-3,23.4,78.9,180,Top
LED_RGB,LED_SMD_5050,12.3,15.6,0,Top
D_PWR,SOD-123,5.5,85.2,90,Top
D_PROT,SOD-123,7.8,82.1,270,Top
D_DISC,SOD-123,48.2,35.4,0,Top
... (resto componentes SMD)
```

> Generar en KiCad: **File → Fabrication Outputs → BOM / Footprint Position (.csv)**

---

## Checklist pre-pedido

- [ ] DRC sin errores (KiCad: Inspect → DRC)
- [ ] Netlist coincide esquemático (Netlist → Verify)
- [ ] Footprints correctos (3D viewer revisar)
- [ ] Mounting holes M3 (4 esquinas)
- [ ] Edge cuts correcto (100×80mm, R2mm corners)
- [ ] Silkscreen: Referencias, Pin 1, Polaridad, Logos
- [ ] No silkscreen sobre pads
- [ ] Vías tienda bajo LM7805, MX1508, AMS1117
- [ ] Polygons GND +5V +3.3V regenerados (B key)
- [ ] Gerbers generados (Plot → Generate Drill Files)
- [ ] Gerbers verificados en visor online
- [ ] ZIP creado con todos archivos requeridos

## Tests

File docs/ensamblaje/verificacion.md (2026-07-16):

# Ensamblaje - Verificación y Test

## Test automático: `test_all.ino`

Sube este sketch tras ensamblar para verificar todo:

```cpp
/*
  Test All - Verificación completa Base ESP32
  Sube tras ensamblar, abre Serial Monitor 115200
*/

#define LED_D1 0
#define LED_D2 2
#define LED_D3 4
#define LED_D4 5
#define MOT_A_IN1 12
#define MOT_A_IN2 13
#define MOT_B_IN3 14
#define MOT_B_IN4 15
#define BUZZER 25
#define DS18B20_PIN 17
#define SERVO_PIN 18
#define POT_PIN 34
#define LDR_PIN 39
#define LM35_PIN 36
#define DIP1 27
#define DIP2 32
#define DIP3 33
#define DIP4 35
#define BTN_PIN 25
#define SPDT_PIN 26

#include <OneWire.h>
#include <DallasTemperature.h>
#include <ESP32Servo.h>

OneWire oneWire(DS18B20_PIN);
DallasTemperature ds18b20(&oneWire);
DeviceAddress dsAddr;
Servo servo;

int testNum = 0;
int passed = 0, failed = 0;

void setup() {
  Serial.begin(115200);
  delay(1000);
  
  // Pines
  pinMode(LED_D1, OUTPUT); pinMode(LED_D2, OUTPUT);
  pinMode(LED_D3, OUTPUT); pinMode(LED_D4, OUTPUT);
  pinMode(MOT_A_IN1, OUTPUT); pinMode(MOT_A_IN2, OUTPUT);
  pinMode(MOT_B_IN3, OUTPUT); pinMode(MOT_B_IN4, OUTPUT);
  pinMode(BUZZER, OUTPUT);
  pinMode(DIP1, INPUT_PULLUP); pinMode(DIP2, INPUT_PULLUP);
  pinMode(DIP3, INPUT_PULLUP); pinMode(DIP4, INPUT_PULLUP);
  pinMode(BTN_PIN, INPUT_PULLUP);
  pinMode(SPDT_PIN, INPUT_PULLUP);
  
  analogReadResolution(12);
  analogSetAttenuation(ADC_11db);
  
  // DS18B20
  ds18b20.begin();
  ds18b20.getAddress(dsAddr, 0);
  ds18b20.setResolution(dsAddr, 12);
  
  // Servo
  servo.setPeriodHertz(50);
  servo.attach(SERVO_PIN, 500, 2500);
  
  // PWM Motor
  ledcAttachPin(MOT_A_IN1, 0); ledcAttachPin(MOT_A_IN2, 1);
  ledcAttachPin(MOT_B_IN3, 2); ledcAttachPin(MOT_B_IN4, 3);
  for(int i=0;i<4;i++) { ledcSetup(i, 20000, 8); ledcWrite(i, 0); }
  
  Serial.println("\n=== BASE ESP32 - TEST COMPLETO ===");
  Serial.println("Iniciando tests...\n");
  
  runAllTests();
  printSummary();
}

void loop() {
  // Blink LED D1 indicando fin
  digitalWrite(LED_D1, millis()%1000<500);
}

void runTest(String name, bool (*test)()) {
  testNum++;
  Serial.printf("[%02d] %s... ", testNum, name.c_str());
  bool ok = test();
  if(ok) { Serial.println("PASS"); passed++; }
  else { Serial.println("FAIL"); failed++; }
}

void runAllTests() {
  // 1. LEDs
  runTest("LED D1 (GPIO0)", testLED_D1);
  runTest("LED D2 (GPIO2)", testLED_D2);
  runTest("LED D3 (GPIO4)", testLED_D3);
  runTest("LED D4 (GPIO5)", testLED_D4);
  
  // 2. PWM LEDs
  runTest("PWM LED D3", testPWM_D3);
  runTest("PWM LED D4", testPWM_D4);
  
  // 3. Motor Driver
  runTest("Motor A Forward", testMotorA_Fwd);
  runTest("Motor A Reverse", testMotorA_Rev);
  runTest("Motor B Forward", testMotorB_Fwd);
  runTest("Motor B Reverse", testMotorB_Rev);
  
  // 4. Buzzer
  runTest("Buzzer Tone", testBuzzer);
  
  // 5. Sensores Temp
  runTest("DS18B20 Detect", testDS18B20);
  runTest("LM35 Read", testLM35);
  
  // 6. LDR
  runTest("LDR Read", testLDR);
  
  // 7. Potenciómetro
  runTest("Pot Read", testPot);
  
  // 8. Switches
  runTest("DIP Switch Read", testDIP);
  runTest("Push Button", testButton);
  runTest("SPDT Switch", testSPDT);
  
  // 9. Servo
  runTest("Servo Sweep", testServo);
  
  // 10. ADC channels
  runTest("ADC1 Channels", testADC);
  runTest("ADC2 Channels", testADC2);
  
  // 11. I2C Scan
  runTest("I2C Scan", testI2C);
}

void printSummary() {
  Serial.printf("\n=== RESUMEN ===\n");
  Serial.printf("Total: %d  Pass: %d  Fail: %d\n", testNum, passed, failed);
  if(failed == 0) Serial.println(">>> TODO OK <<<");
  else Serial.println(">>> REVISAR FALLOS <<<");
}

// === TESTS INDIVIDUALES ===

bool testLED_D1() {
  digitalWrite(LED_D1, HIGH); delay(50); 
  bool ok = digitalRead(LED_D1) == HIGH;
  digitalWrite(LED_D1, LOW);
  return ok;
}

bool testLED_D2() {
  digitalWrite(LED_D2, HIGH); delay(50);
  bool ok = digitalRead(LED_D2) == HIGH;
  digitalWrite(LED_D2, LOW);
  return ok;
}

bool testLED_D3() {
  digitalWrite(LED_D3, HIGH); delay(50);
  bool ok = digitalRead(LED_D3) == HIGH;
  digitalWrite(LED_D3, LOW);
  return ok;
}

bool testLED_D4() {
  digitalWrite(LED_D4, HIGH); delay(50);
  bool ok = digitalRead(LED_D4) == HIGH;
  digitalWrite(LED_D4, LOW);
  return ok;
}

bool testPWM_D3() {
  ledcAttachPin(LED_D3, 4); ledcSetup(4, 5000, 8);
  ledcWrite(4, 128); delay(50);
  int v = digitalRead(LED_D3);
  ledcWrite(4, 0); ledcDetachPin(LED_D3);
  return v == HIGH;  // PWM alto = HIGH en lectura digital
}

bool testPWM_D4() {
  ledcAttachPin(LED_D4, 5); ledcSetup(5, 5000, 8);
  ledcWrite(5, 128); delay(50);
  int v = digitalRead(LED_D4);
  ledcWrite(5, 0); ledcDetachPin(LED_D4);
  return v == HIGH;
}

bool testMotorA_Fwd() {
  ledcWrite(0, 100); ledcWrite(1, 0); delay(50);
  bool ok = (digitalRead(MOT_A_IN1)==HIGH && digitalRead(MOT_A_IN2)==LOW);
  ledcWrite(0, 0); ledcWrite(1, 0);
  return ok;
}

bool testMotorA_Rev() {
  ledcWrite(0, 0); ledcWrite(1, 100); delay(50);
  bool ok = (digitalRead(MOT_A_IN1)==LOW && digitalRead(MOT_A_IN2)==HIGH);
  ledcWrite(0, 0); ledcWrite(1, 0);
  return ok;
}

bool testMotorB_Fwd() {
  ledcWrite(2, 100); ledcWrite(3, 0); delay(50);
  bool ok = (digitalRead(MOT_B_IN3)==HIGH && digitalRead(MOT_B_IN4)==LOW);
  ledcWrite(2, 0); ledcWrite(3, 0);
  return ok;
}

bool testMotorB_Rev() {
  ledcWrite(2, 0); ledcWrite(3, 100); delay(50);
  bool ok = (digitalRead(MOT_B_IN3)==LOW && digitalRead(MOT_B_IN4)==HIGH);
  ledcWrite(2, 0); ledcWrite(3, 0);
  return ok;
}

bool testBuzzer() {
  tone(BUZZER, 1000, 50); delay(60);
  noTone(BUZZER);
  return true;  // No hay feedback eléctrico fácil
}

bool testDS18B20() {
  ds18b20.requestTemperatures();
  float t = ds18b20.getTempC(dsAddr);
  return (t != DEVICE_DISCONNECTED_C && t > -40 && t < 125);
}

bool testLM35() {
  long sum = 0;
  for(int i=0;i<16;i++) { sum += analogRead(LM35_PIN); delayMicroseconds(100); }
  float v = (sum/16.0) * 3.3 / 4095.0;
  float t = v * 100.0;
  return (t >= 0 && t <= 100);  // Rango razonable
}

bool testLDR() {
  int raw = analogRead(LDR_PIN);
  float v = raw * 3.3 / 4095.0;
  return (v >= 0.1 && v <= 3.2);  // No rail-to-rail
}

bool testPot() {
  int raw = analogRead(POT_PIN);
  return (raw >= 0 && raw <= 4095);
}

bool testDIP() {
  uint8_t v = (!digitalRead(DIP1)<<0) | (!digitalRead(DIP2)<<1) | 
              (!digitalRead(DIP3)<<2) | (!digitalRead(DIP4)<<3);
  return true;  // Solo lectura, siempre OK
}

bool testButton() {
  bool pressed = digitalRead(BTN_PIN) == LOW;
  return true;  // Solo lectura
}

bool testSPDT() {
  bool state = digitalRead(SPDT_PIN);
  return true;
}

bool testServo() {
  servo.write(0); delay(300);
  servo.write(90); delay(300);
  servo.write(180); delay(300);
  servo.write(90);
  return true;
}

bool testADC() {
  // ADC1: GPIO36,39,34,35,32,33
  int pins[] = {36, 39, 34, 35, 32, 33};
  for(int p : pins) {
    int r = analogRead(p);
    if(r < 0 || r > 4095) return false;
  }
  return true;
}

bool testADC2() {
  // ADC2: GPIO0,2,4,12,13,14,15,25,26,27
  // Nota: ADC2 no usable con WiFi activo
  int pins[] = {0, 2, 4, 12, 13, 14, 15, 25, 26, 27};
  for(int p : pins) {
    int r = analogRead(p);
    if(r < 0 || r > 4095) return false;
  }
  return true;
}

bool testI2C() {
  Wire.begin(21, 19);
  byte count = 0;
  for(byte addr=1; addr<127; addr++) {
    Wire.beginTransmission(addr);
    if(Wire.endTransmission() == 0) count++;
  }
  Wire.end();
  Serial.printf("    Dispositivos I2C: %d\n", count);
  return true;  // OK aunque 0
}
```

---

## Verificación con Multímetro

### Antes de encender (PCB sola)
```
□ Continuidad GND: Todos GND pads conectados (beep)
□ Continuidad +5V: Jack DC → LM7805 IN → LM7805 OUT → MX1508 VM → Terminal + → Servo VCC
□ Continuidad +3.3V: AMS1117 OUT → ESP32 3V3 pins → Sensores VCC
□ NO continuidad: +5V ↔ GND, +3.3V ↔ GND, +5V ↔ +3.3V (OL = Open Loop)
□ Resistencia LM7805 IN-GND: >1kΩ (no corto)
□ Resistencia AMS1117 IN-GND: >1kΩ
□ Diodos 1N5813: Diodo test → ~0.3V forward, OL reverse
```

### Alimentado (USB o Jack 9V)
```
□ +5V Rail: 4.90 - 5.10V
□ +3.3V Rail: 3.25 - 3.35V
□ LM7805 Temp: <60°C (tocable)
□ AMS1117 Temp: <50°C
□ MX1508 Temp: <50°C (sin motor)
□ Corriente USB: 80-120mA (reposo)
□ Corriente Jack 9V: 50-100mA (reposo)
```

### Con ESP32 insertado + firmware test_all
```
□ Serial Monitor: 115200 baud, texto legible
□ Test LEDs: 4 parpadeos secuenciales
□ Test PWM: D3/D4 fade in/out
□ Test Motor: Terminal block MOT_A+/-, MOT_B+/- pulsos
□ Test Buzzer: Beep 1kHz 50ms
□ Test Temp: DS18B20 ~20-30°C, LM35 similar
□ Test LDR: Valor cambia tapando/exponiendo
□ Test Pot: Valor 0-4095 girando
□ Test DIP: Cambia valor moviendo switches
□ Test Button: "Button pressed" al pulsar
□ Test SPDT: Cambia estado moviendo
□ Test Servo: Barrido 0-180-0
□ Test I2C: "Dispositivos I2C: 0" (o >0 si hay externo)
□ Resumen final: "TODO OK" (0 FAIL)
```

---

## Debug común

| Síntoma | Causa probable | Verificación |
|---|---|---|
| LED power OFF | LM7805 / AMS1117 mal soldado | Voltaje IN/OUT reguladores |
| ESP32 no detectado | Socket pines doblados / mal soldado | Continuidad cada pin socket→pad |
| Motor no gira | MX1508 VM sin alimentación | +5V en pin 8 MX1508 |
| DS18B20 -127°C | Pull-up 4.7k faltante / cableado | 4.7k Data-3.3V, continuidad |
| LM35 0V / 3.3V | ADC saturado / pin mal | analogRead raw, voltaje pin |
| LDR siempre 4095 | LDR abierto / GND faltante | Resistencia LDR multímetro |
| Pot siempre 0/4095 | Cursor roto / patas invertidas | Resistencia entre extremos |
| DIP siempre 1111 | Pull-up faltante GPIO35 | 10kΩ ext GPIO35-3.3V |
| Servo vibra/no mueve | PWM 50Hz mal / alimentación | ledcSetup 50Hz, +5V en servo |
| Buzzer mudo | GPIO25 conflicto / pin mal | tone() en pin correcto |

---

## Firmware de producción sugerido

Tras verificación, flashea tu aplicación real. Ejemplo estructura:

```cpp
// main.cpp
#include "config.h"
#include "wifi_mgr.h"
#include "sensor_mgr.h"
#include "motor_ctrl.h"
#include "web_server.h"

void setup() {
  Serial.begin(115200);
  hw_init();        // Pines, ADC, PWM
  sensors_init();   // DS18B20, LM35, LDR
  motor_init();     // MX1508
  wifi_init();      // STA + AP fallback
  webserver_init(); // API REST + OTA
}

void loop() {
  sensors_update();
  motor_update();
  webserver_handle();
  watchdog_feed();
}
```

Ver [Prácticas](../practicas/index.md) para ejemplos completos.

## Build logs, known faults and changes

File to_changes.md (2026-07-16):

# Cambios en la pcb

- colocar nombre a donde a un lado del footprint de los reguladores de 3.3
- cambiar el driver por un L293D, a THT y SMD
- Agregar un LED RGB,
- Los primeros 3 leds a positivo, invertir para que no choquen con el RGB
- invertir la terminal de tornillos
- licencia CERN-OHL-S v2.0.
- Agregar github action y dar permiso en repo

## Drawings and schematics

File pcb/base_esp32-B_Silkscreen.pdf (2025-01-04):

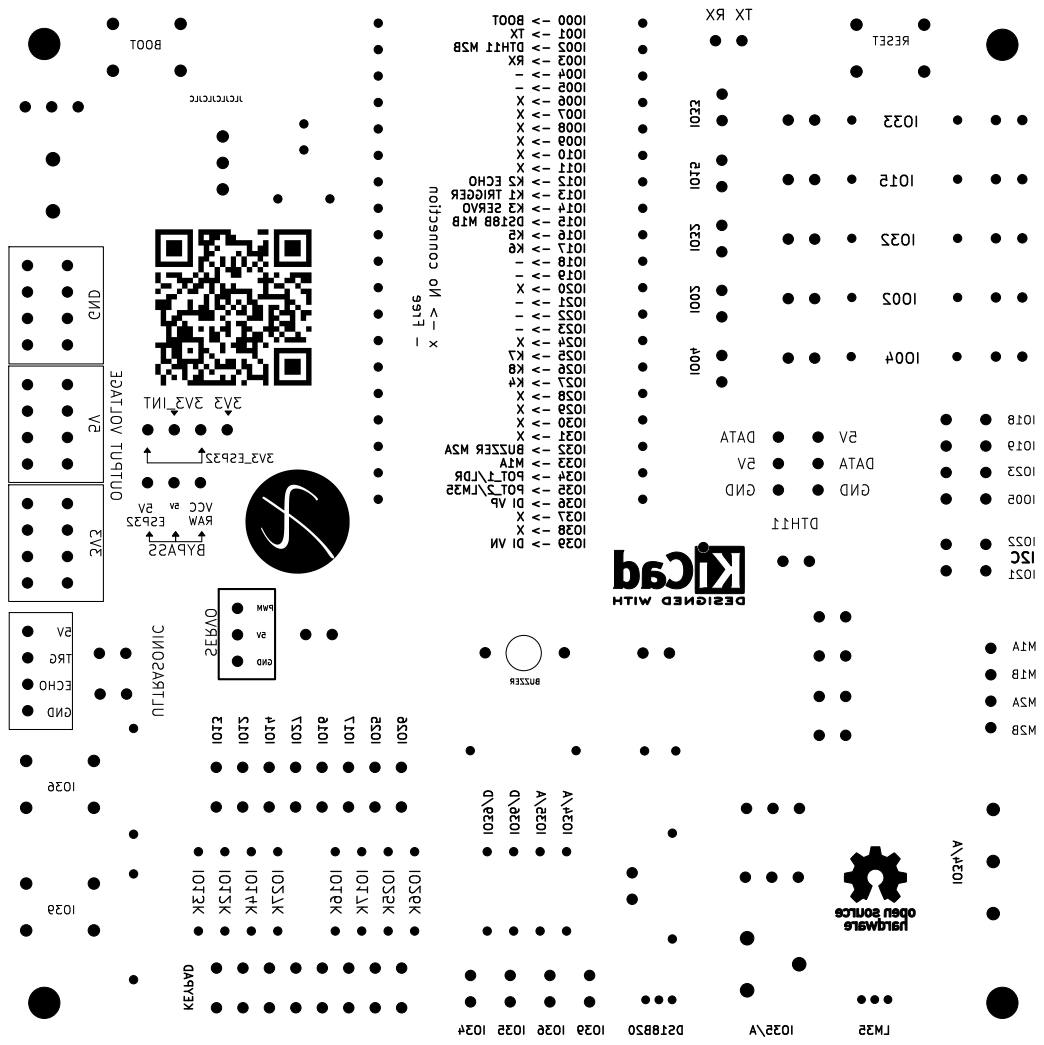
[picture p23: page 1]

IO39 GND IO33 BOOT -> IO00 TX -> IO01 M2B DTH11 -> IO02 RX -> IO03 - -> IO04 - -> IO05 X -> IO06 X -> IO07 X -> IO08 X -> IO09 X -> IO10 X -> IO11 ECHO K2 -> IO12 TRIGGER K1 -> IO13 SERVO K3 -> IO14 M1B DS18B -> IO15 K5 -> IO16 K6 -> IO17 - -> IO18 - -> IO19 X -> IO20 - -> IO21 - -> IO22 - -> IO23 X -> IO24 K7 -> IO25 K8 -> IO26 K4 -> IO27 X -> IO28 X -> IO29 X -> IO30 X -> IO31 M2A BUZZER -> IO32 M1A -> IO33 POT_1/LDR -> IO34 POT_2/LM35 -> IO35 VP DI -> IO36 X -> IO37 X -> IO38 VN DI -> IO39 VCC

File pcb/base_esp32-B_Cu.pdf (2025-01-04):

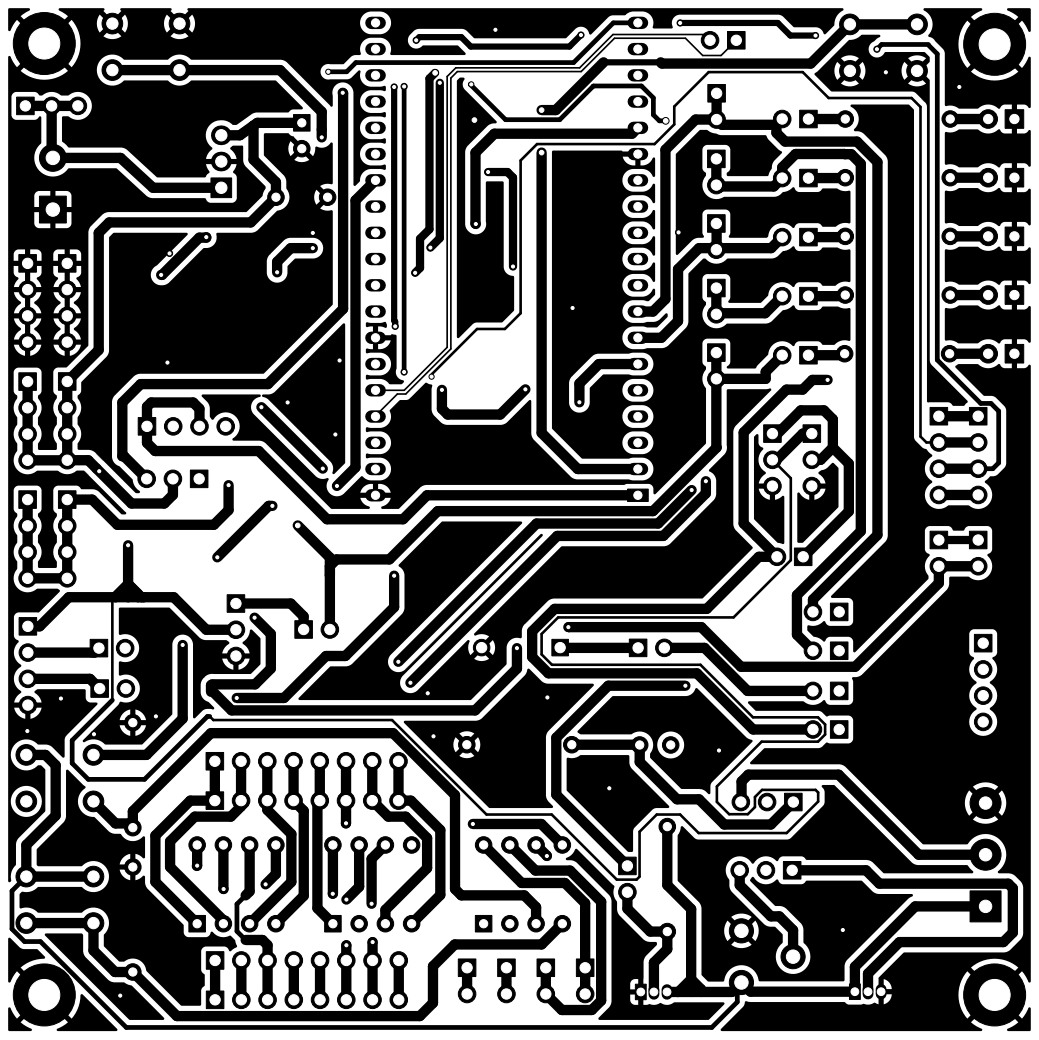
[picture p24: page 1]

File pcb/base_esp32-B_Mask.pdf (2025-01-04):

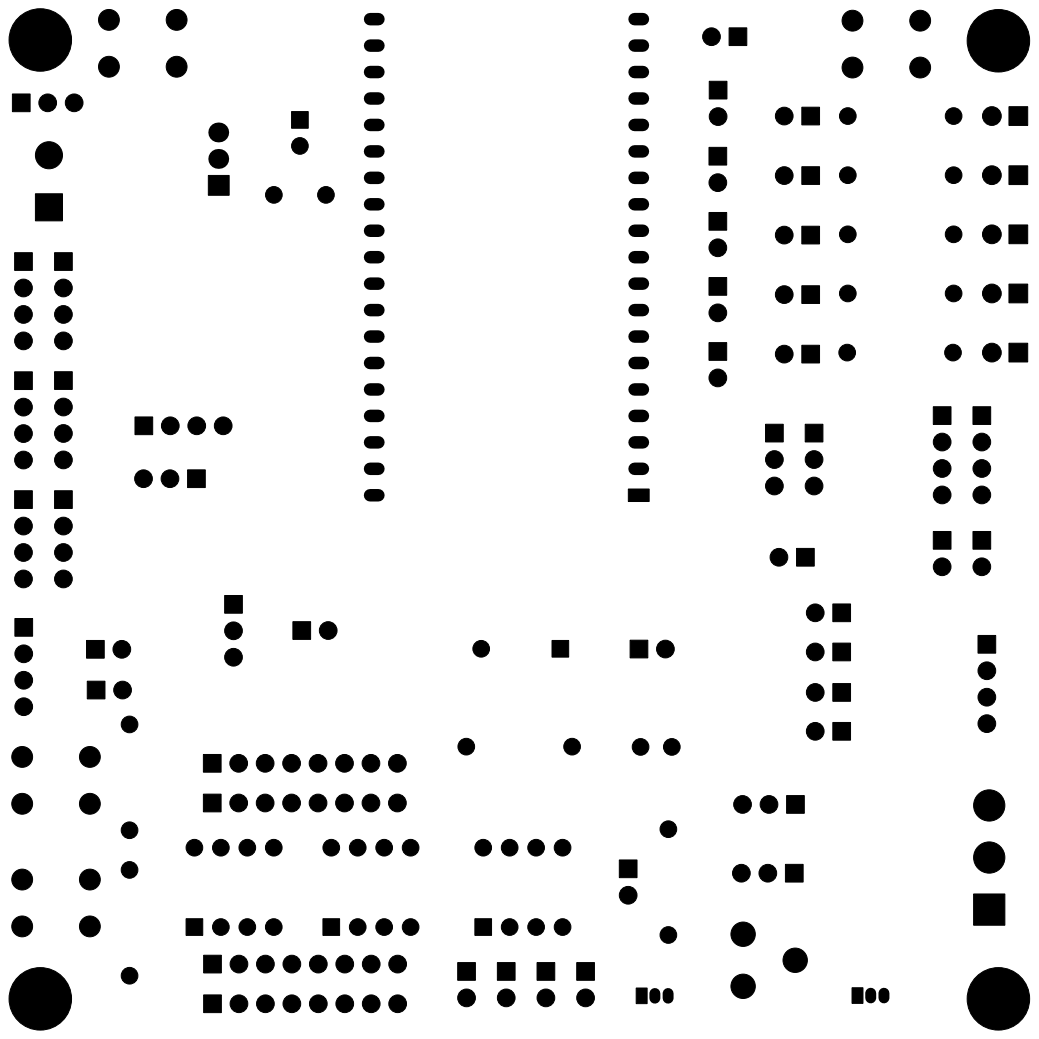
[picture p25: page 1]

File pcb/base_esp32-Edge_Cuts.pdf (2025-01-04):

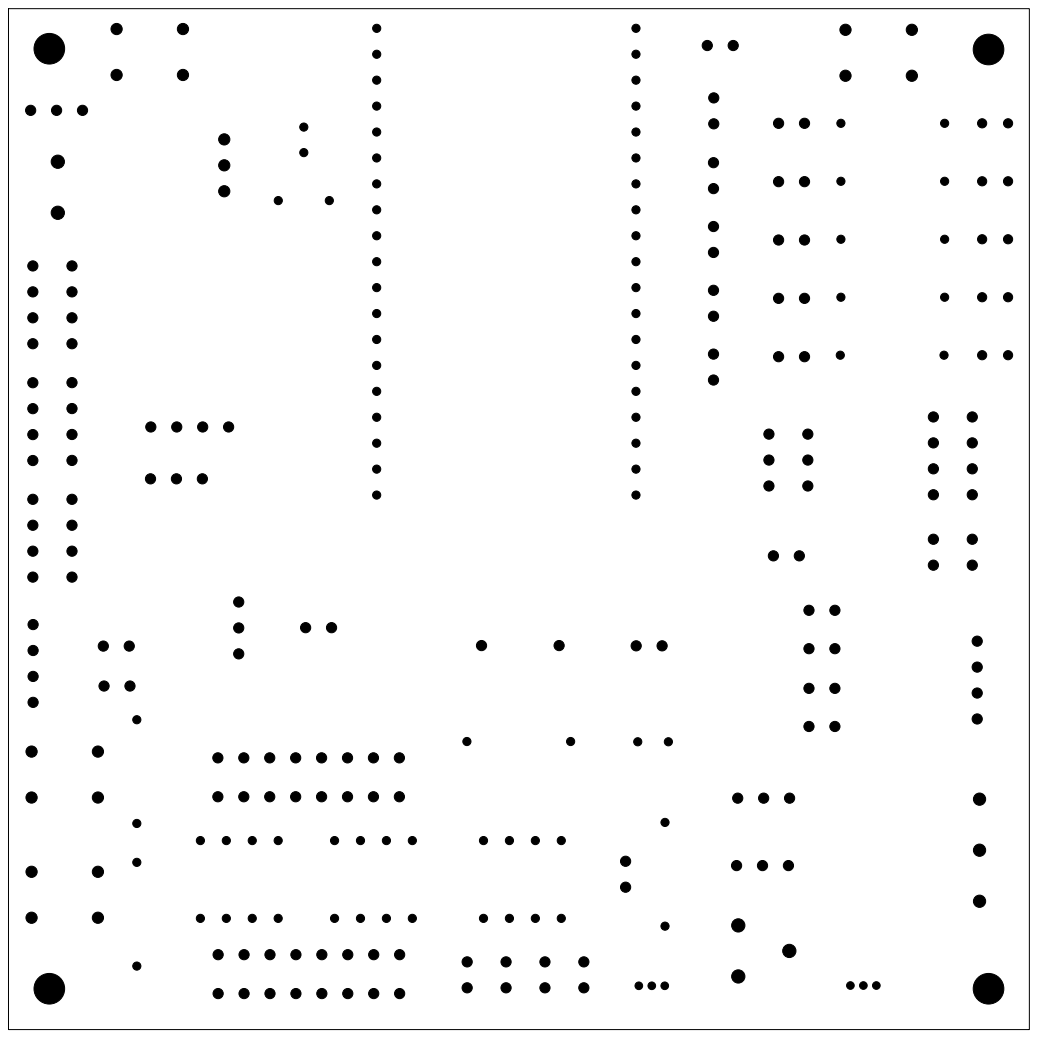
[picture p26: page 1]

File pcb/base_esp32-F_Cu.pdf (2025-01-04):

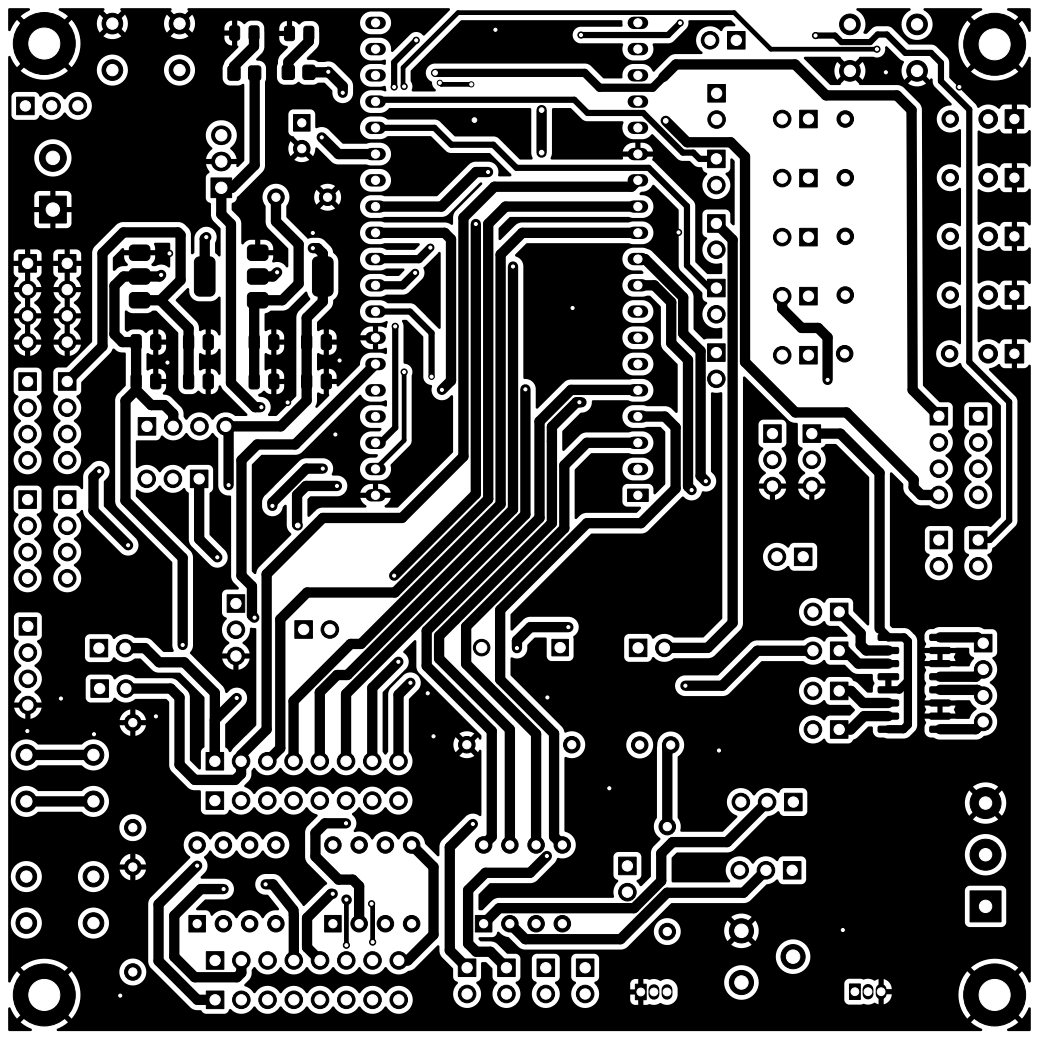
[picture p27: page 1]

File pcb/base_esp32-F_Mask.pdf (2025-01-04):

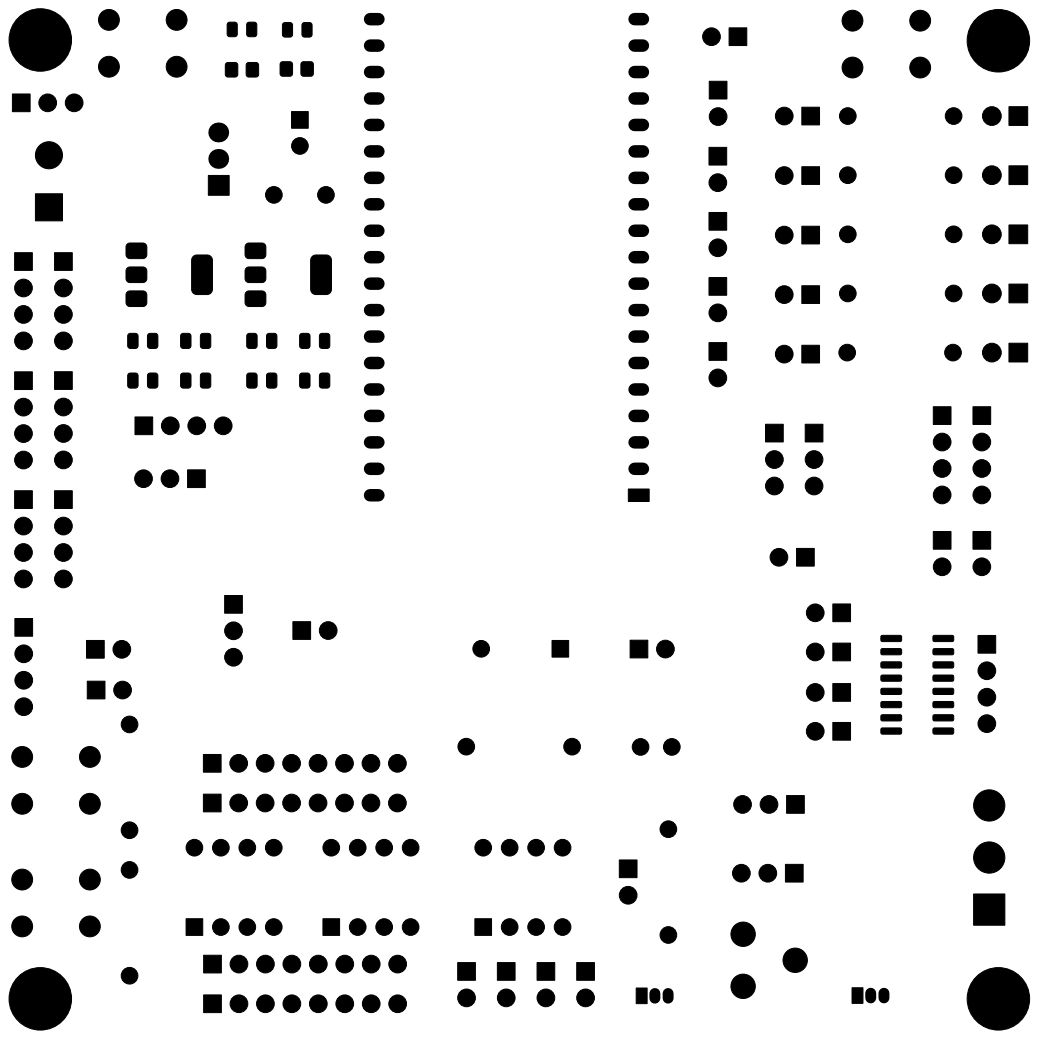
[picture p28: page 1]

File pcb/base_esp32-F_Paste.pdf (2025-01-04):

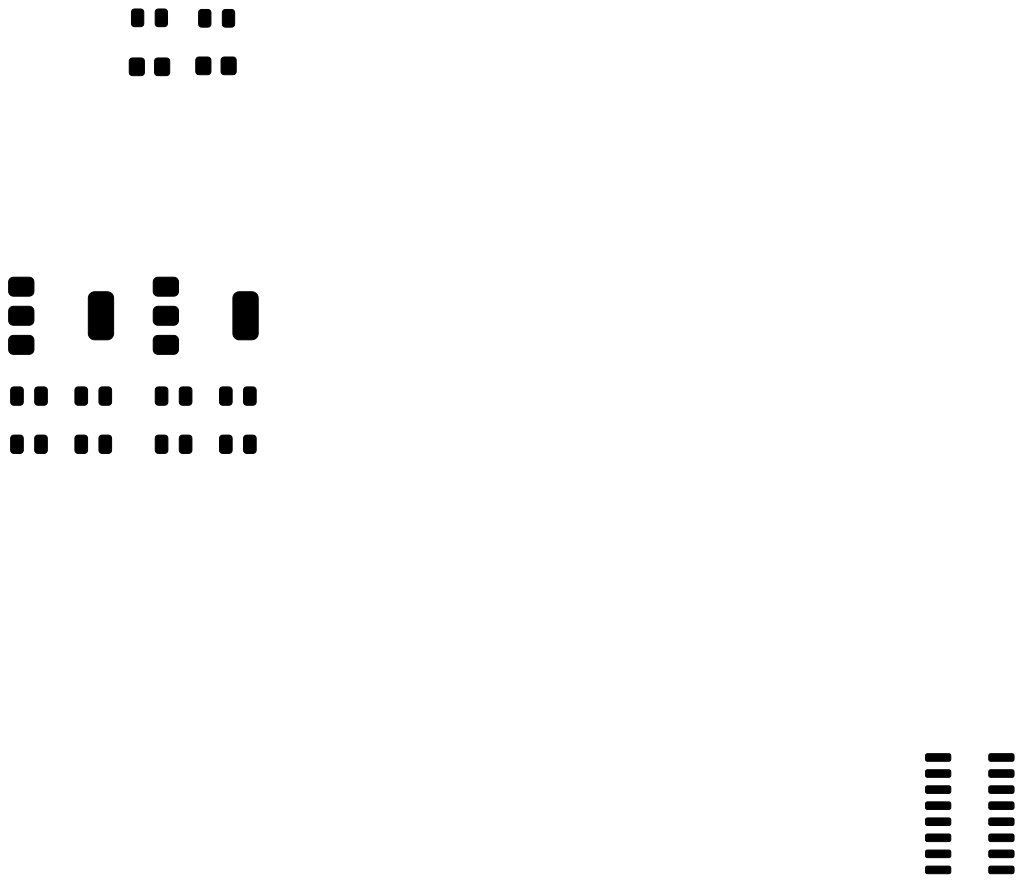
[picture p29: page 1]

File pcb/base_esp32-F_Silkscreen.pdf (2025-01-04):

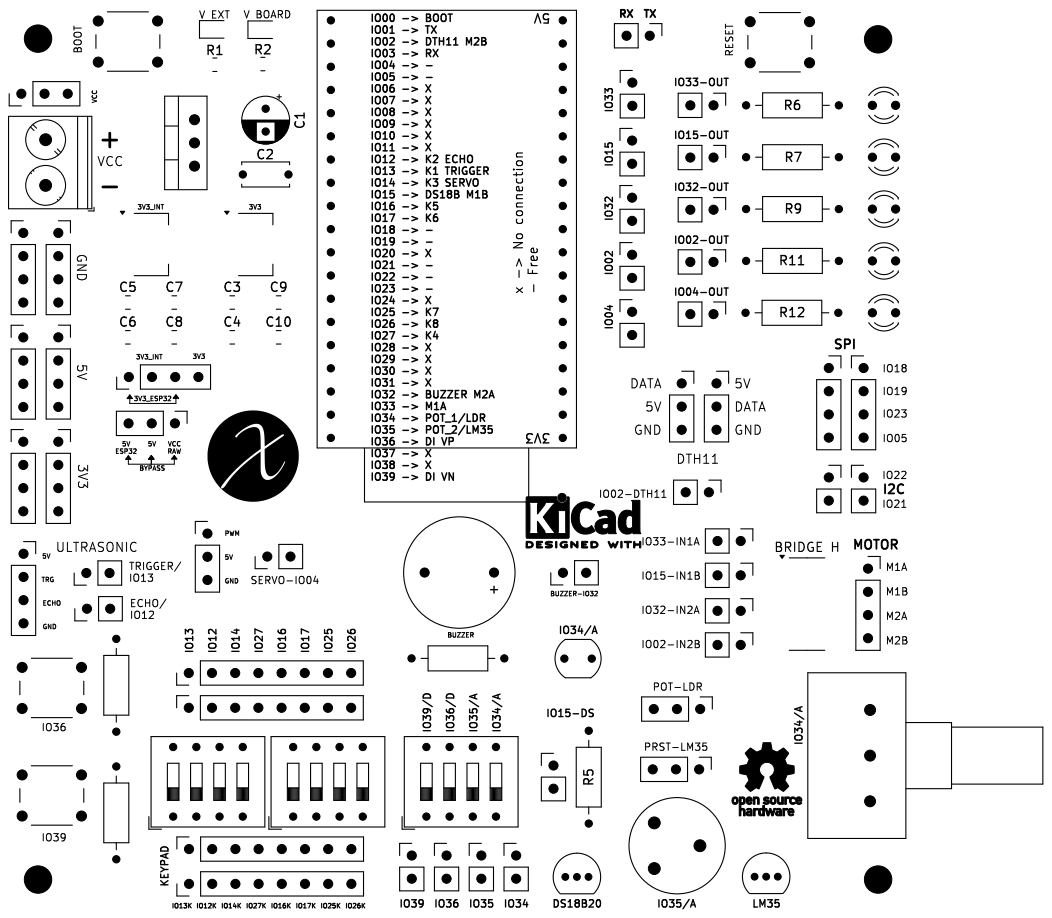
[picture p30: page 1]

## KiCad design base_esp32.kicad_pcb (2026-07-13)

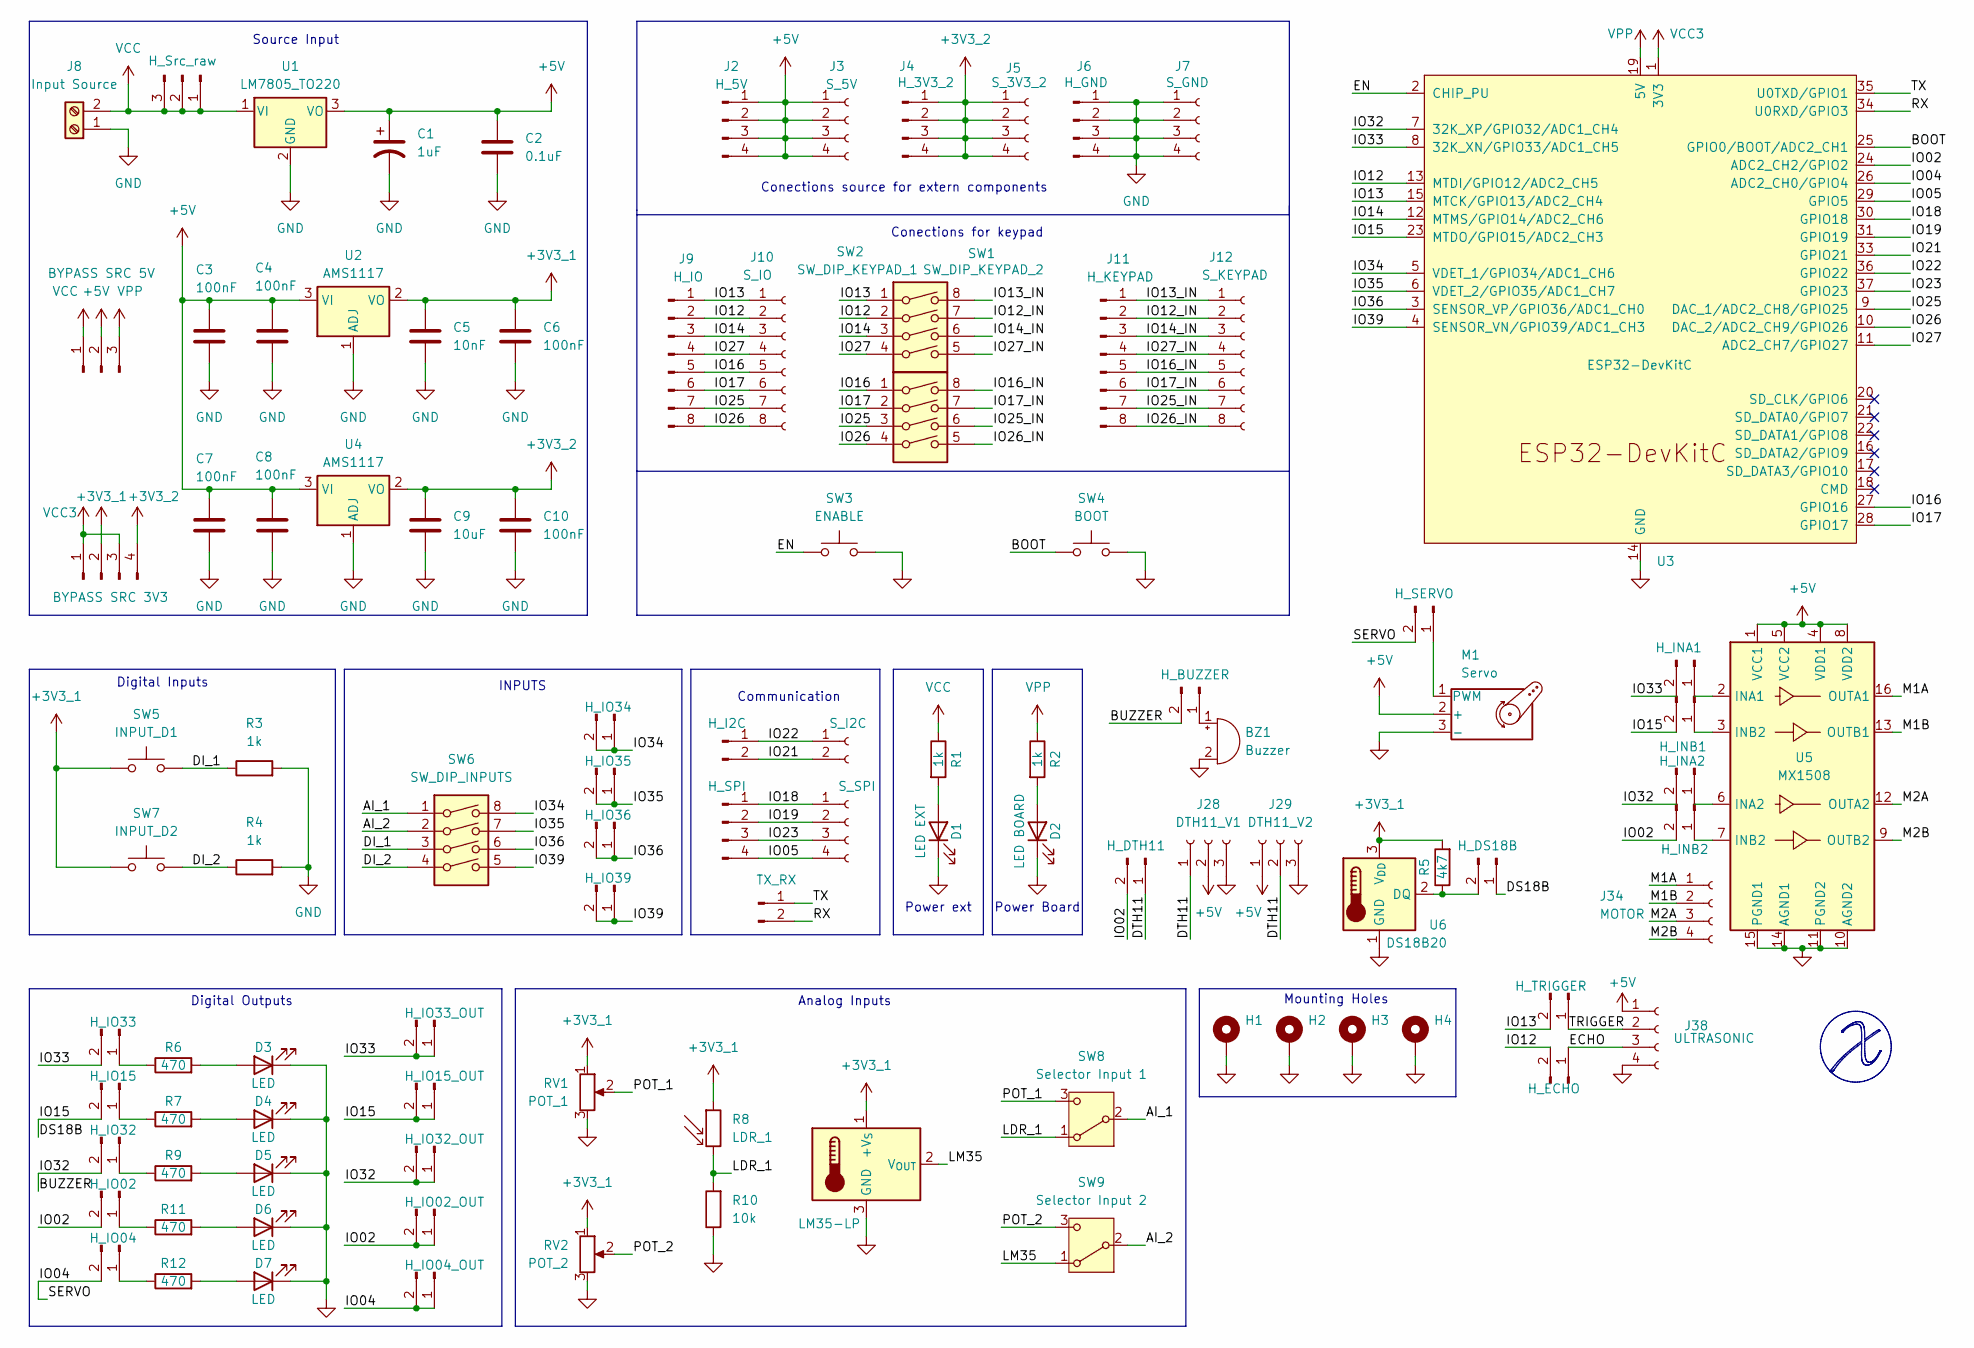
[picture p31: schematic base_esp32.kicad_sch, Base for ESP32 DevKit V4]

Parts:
BZ1: Buzzer; MagneticBuzzer_ProSignal_ABI-010-RC
C1: 1uF; CP_Radial_D5.0mm_P2.50mm
C2: 0.1uF; C_Disc_D5.0mm_W2.5mm_P5.00mm
C3, C4, C6, C7, C8, C10: 100nF; C_0805_2012Metric
C5: 10nF; C_0805_2012Metric
C9: 10uF; C_0805_2012Metric
D1: LED EXT; LED_0805_2012Metric
D2: LED BOARD; LED_0805_2012Metric
D3, D4, D5, D6, D7: LED; LED_D3.0mm
H1, H2, H3, H4: MountingHole_Pad; MountingHole_3mm_Pad_TopBottom
J1: H_Src_raw; PinHeader_1x03_P2.54mm_Vertical
J2: H_5V; PinHeader_1x04_P2.54mm_Vertical
J3: S_5V; PinSocket_1x04_P2.54mm_Vertical
J4: H_3V3_2; PinHeader_1x04_P2.54mm_Vertical
J5: S_3V3_2; PinSocket_1x04_P2.54mm_Vertical
J6: H_GND; PinHeader_1x04_P2.54mm_Vertical
J7: S_GND; PinSocket_1x04_P2.54mm_Vertical
J8: Input Source; TerminalBlock_Phoenix_PT-1,5-2-5.0-H_1x02_P5.00mm_Horizontal
J9: H_IO; PinHeader_1x08_P2.54mm_Vertical
J10: S_IO; PinSocket_1x08_P2.54mm_Vertical
J11: H_KEYPAD; PinHeader_1x08_P2.54mm_Vertical
J12: S_KEYPAD; PinSocket_1x08_P2.54mm_Vertical
J13: BYPASS SRC 5V; PinHeader_1x03_P2.54mm_Vertical
J14: BYPASS SRC 3V3; PinHeader_1x04_P2.54mm_Vertical
J15: H_SERVO; PinHeader_1x02_P2.54mm_Vertical
J16: H_INA1; PinHeader_1x02_P2.54mm_Vertical
J17: H_BUZZER; PinHeader_1x02_P2.54mm_Vertical
J18: H_INB1; PinHeader_1x02_P2.54mm_Vertical
J19: H_IO34; PinHeader_1x02_P2.54mm_Vertical
J20: H_I2C; PinHeader_1x02_P2.54mm_Vertical
J21: S_I2C; PinSocket_1x02_P2.54mm_Vertical
J22: H_IO35; PinHeader_1x02_P2.54mm_Vertical
J23: H_INA2; PinHeader_1x02_P2.54mm_Vertical
J24: H_INB2; PinHeader_1x02_P2.54mm_Vertical
J25: H_IO36; PinHeader_1x02_P2.54mm_Vertical
J26: H_SPI; PinHeader_1x04_P2.54mm_Vertical
J27: S_SPI; PinSocket_1x04_P2.54mm_Vertical
J28: DTH11_V1; PinSocket_1x03_P2.54mm_Vertical
J29: DTH11_V2; PinSocket_1x03_P2.54mm_Vertical
J30: H_DTH11; PinHeader_1x02_P2.54mm_Vertical
J31: H_DS18B; PinHeader_1x02_P2.54mm_Vertical
J32: H_IO39; PinHeader_1x02_P2.54mm_Vertical
J33: TX_RX; PinHeader_1x02_P2.54mm_Vertical
J34: MOTOR; PinSocket_1x04_P2.54mm_Vertical
J35: H_TRIGGER; PinHeader_1x02_P2.54mm_Vertical
J36: H_IO33_OUT; PinHeader_1x02_P2.54mm_Vertical
J37: H_IO33; PinHeader_1x02_P2.54mm_Vertical
J38: ULTRASONIC; PinSocket_1x04_P2.54mm_Vertical
J39: H_IO15; PinHeader_1x02_P2.54mm_Vertical
J40: H_IO15_OUT; PinHeader_1x02_P2.54mm_Vertical
J41: H_ECHO; PinHeader_1x02_P2.54mm_Vertical
J42: H_IO32; PinHeader_1x02_P2.54mm_Vertical
J43: H_IO32_OUT; PinHeader_1x02_P2.54mm_Vertical
J44: H_IO02; PinHeader_1x02_P2.54mm_Vertical
J45: H_IO02_OUT; PinHeader_1x02_P2.54mm_Vertical
J46: H_IO04; PinHeader_1x02_P2.54mm_Vertical
J47: H_IO04_OUT; PinHeader_1x02_P2.54mm_Vertical
M1: Servo; PinHeader_1x03_P2.54mm_Vertical
R1, R2: 1k; R_0805_2012Metric_Pad1.20x1.40mm_HandSolder
R3, R4: 1k; R_Axial_DIN0207_L6.3mm_D2.5mm_P10.16mm_Horizontal
R5: 4k7; R_Axial_DIN0207_L6.3mm_D2.5mm_P10.16mm_Horizontal
R6, R7, R9, R11, R12: 470; R_Axial_DIN0207_L6.3mm_D2.5mm_P10.16mm_Horizontal
R8: LDR_1; R_LDR_5.0x4.1mm_P3mm_Vertical
R10: 10k; R_Axial_DIN0207_L6.3mm_D2.5mm_P10.16mm_Horizontal
RV1: POT_1; Potentiometer_Alps_RK163_Single_Horizontal
RV2: POT_2; Potentiometer_Piher_PT-10-V05_Vertical
SW1: SW_DIP_KEYPAD_1; SW_DIP_SPSTx04_Slide_9.78x12.34mm_W7.62mm_P2.54mm
SW2: SW_DIP_KEYPAD_2; SW_DIP_SPSTx04_Slide_9.78x12.34mm_W7.62mm_P2.54mm
SW3: ENABLE; SW_PUSH_6mm
SW4: BOOT; SW_PUSH_6mm
SW5: INPUT_D1; SW_PUSH_6mm
SW6: SW_DIP_INPUTS; SW_DIP_SPSTx04_Slide_9.78x12.34mm_W7.62mm_P2.54mm
SW7: INPUT_D2; SW_PUSH_6mm
SW8: Selector Input 1; PinHeader_1x03_P2.54mm_Vertical
SW9: Selector Input 2; PinHeader_1x03_P2.54mm_Vertical
U1: LM7805_TO220; TO-220-3_Vertical
U2, U4: AMS1117; SOT-223-3_TabPin2; LCSC Part C22458961
U3: ESP32-DevKitC
U5: MX1508; SOP-16_3.9x9.9mm_P1.27mm
U6: DS18B20; TO-92_Inline
U7: LM35-LP; TO-92_Inline

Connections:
+3V3_1: C5.1, C6.1, J14.2, R5.2, R8.1, RV1.1, RV2.1, SW5.1, SW7.1, U2.2 (VO), U6.3 (V_{DD}), U7.1 (+V_{S})
+3V3_2: C9.1, C10.1, J4.1, J4.2, J4.3, J4.4, J5.1, J5.2, J5.3, J5.4, J14.4, U4.2 (VO)
+5V: C1.1, C2.1, C3.1, C4.1, C7.1, C8.1, J2.1, J2.2, J2.3, J2.4, J3.1, J3.2, J3.3, J3.4, J13.2, J28.2, J29.1, J38.1, M1.2 (+), U1.3 (VO), U2.3 (VI), U4.3 (VI), U5.1 (VCC1), U5.4 (VDD1), U5.5 (VCC2), U5.8 (VDD2)
/AI_1: SW6.1, SW8.2 (B)
/AI_2: SW6.2, SW9.2 (B)
/BOOT: SW4.1, U3.25 (GPIO0/BOOT/ADC2_CH1)
/BUZZER: J17.2, J23.2, J42.2, J43.1, J43.2, U3.7 (32K_XP/GPIO32/ADC1_CH4)
/DI_1: R3.1, SW5.2, SW6.3
/DI_2: R4.1, SW6.4, SW7.2
/DS18B: J18.2, J31.1, J39.2, J40.1, J40.2, U3.23 (MTDO/GPIO15/ADC2_CH3)
/DTH11: J28.1, J29.2, J30.1
/ECHO: J38.3, J41.1
/EN: SW3.1, U3.2 (CHIP_PU)
/IO02: J24.2, J30.2, J44.2, J45.1, J45.2, U3.24 (ADC2_CH2/GPIO2)
/IO04: J15.2, J46.2, J47.1, J47.2, U3.26 (ADC2_CH0/GPIO4)
/IO05: J26.4, J27.4, U3.29 (GPIO5)
/IO12: J9.2, J10.2, J41.2, SW1.2, U3.13 (MTDI/GPIO12/ADC2_CH5)
/IO12_IN: J11.2, J12.2, SW1.7
/IO13: J9.1, J10.1, J35.2, SW1.1, U3.15 (MTCK/GPIO13/ADC2_CH4)
/IO13_IN: J11.1, J12.1, SW1.8
/IO14: J9.3, J10.3, SW1.3, U3.12 (MTMS/GPIO14/ADC2_CH6)
/IO14_IN: J11.3, J12.3, SW1.6
/IO16: J9.5, J10.5, SW2.1, U3.27 (GPIO16)
/IO16_IN: J11.5, J12.5, SW2.8
/IO17: J9.6, J10.6, SW2.2, U3.28 (GPIO17)
/IO17_IN: J11.6, J12.6, SW2.7
/IO18: J26.1, J27.1, U3.30 (GPIO18)
/IO19: J26.2, J27.2, U3.31 (GPIO19)
/IO21: J20.2, J21.2, U3.33 (GPIO21)
/IO22: J20.1, J21.1, U3.36 (GPIO22)
/IO23: J26.3, J27.3, U3.37 (GPIO23)
/IO25: J9.7, J10.7, SW2.3, U3.9 (DAC_1/ADC2_CH8/GPIO25)
/IO25_IN: J11.7, J12.7, SW2.6
/IO26: J9.8, J10.8, SW2.4, U3.10 (DAC_2/ADC2_CH9/GPIO26)
/IO26_IN: J11.8, J12.8, SW2.5
/IO27: J9.4, J10.4, SW1.4, U3.11 (ADC2_CH7/GPIO27)
/IO27_IN: J11.4, J12.4, SW1.5
/IO33: J16.2, J36.1, J36.2, J37.2, U3.8 (32K_XN/GPIO33/ADC1_CH5)
/IO34: J19.1, J19.2, SW6.8, U3.5 (VDET_1/GPIO34/ADC1_CH6)
/IO35: J22.1, J22.2, SW6.7, U3.6 (VDET_2/GPIO35/ADC1_CH7)
/IO36: J25.1, J25.2, SW6.6, U3.3 (SENSOR_VP/GPIO36/ADC1_CH0)
/IO39: J32.1, J32.2, SW6.5, U3.4 (SENSOR_VN/GPIO39/ADC1_CH3)
/LDR_1: R8.2, R10.2, SW8.1 (A)
/LM35: SW9.1 (A), U7.2 (V_{OUT})
/M1A: J34.1, U5.16 (OUTA1)
/M1B: J34.2, U5.13 (OUTB1)
/M2A: J34.3, U5.12 (OUTA2)
/M2B: J34.4, U5.9 (OUTB2)
/POT_1: RV1.2, SW8.3 (C)
/POT_2: RV2.2, SW9.3 (C)
/RX: J33.2, U3.34 (U0RXD/GPIO3)
/TRIGGER: J35.1, J38.2
/TX: J33.1, U3.35 (U0TXD/GPIO1)
GND: BZ1.2 (-), C1.2, C2.2, C3.2, C4.2, C5.2, C6.2, C7.2, C8.2, C9.2, C10.2, D1.1 (K), D2.1 (K), D3.1 (K), D4.1 (K), D5.1 (K), D6.1 (K), D7.1 (K), H1.1, H2.1, H3.1, H4.1, J6.1, J6.2, J6.3, J6.4, J7.1, J7.2, J7.3, J7.4, J8.1, J28.3, J29.3, J38.4, M1.3 (-), R3.2, R4.2, R10.1, RV1.3, RV2.3, SW3.2, SW4.2, U1.2 (GND), U2.1 (ADJ), U3.14 (GND), U3.32 (GND), U3.38 (GND), U4.1 (ADJ), U5.10 (AGND2), U5.11 (PGND2), U5.14 (AGND1), U5.15 (PGND1), U6.1 (GND), U7.3 (GND)
unnamed: BZ1.1 (+), J17.1
unnamed: D1.2 (A), R1.2
unnamed: D2.2 (A), R2.2
unnamed: D3.2 (A), R6.2
unnamed: D4.2 (A), R7.2
unnamed: D5.2 (A), R9.2
unnamed: D6.2 (A), R11.2
unnamed: D7.2 (A), R12.2
unnamed: J15.1, M1.1 (PWM)
unnamed: J16.1, U5.2 (INA1)
unnamed: J18.1, U5.3 (INB2)
unnamed: J23.1, U5.6 (INA2)
unnamed: J24.1, U5.7 (INB2)
unnamed: J31.2, R5.1, U6.2 (DQ)
unnamed: J37.1, R6.1
unnamed: J39.1, R7.1
unnamed: J42.1, R9.1
unnamed: J44.1, R11.1
unnamed: J46.1, R12.1
VCC: J1.1, J1.2, J1.3, J8.2, J13.1, R1.1, U1.1 (VI)
VCC3: J14.1, J14.3, U3.1 (3V3)
VPP: J13.3, R2.1, U3.19 (5V)

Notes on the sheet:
Conections for keypad
Conections source for extern components
Source Input
Digital Inputs
INPUTS
Digital Outputs
Power ext
Power Board
Analog Inputs
Mounting Holes
Communication

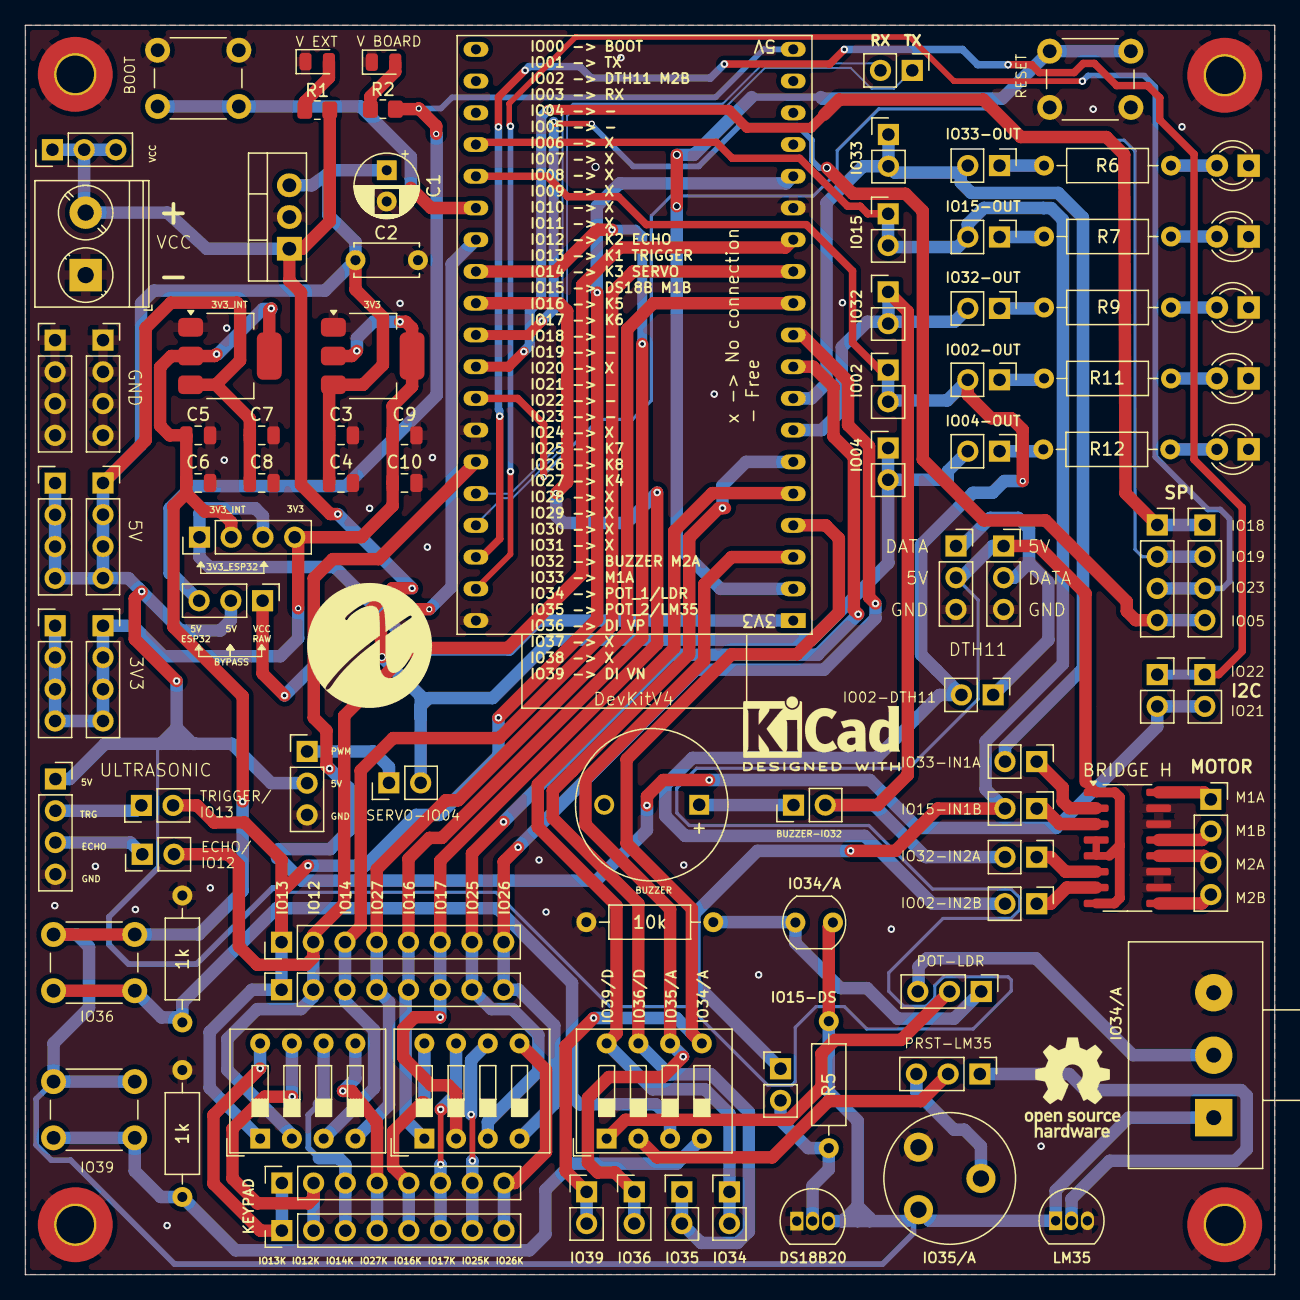
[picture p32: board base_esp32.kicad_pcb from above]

Board: 2 copper layers, 100.0 x 100.0 mm, 100 parts (0 on the bottom side), 76 nets.

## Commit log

2024-11-28 add: schematic
    [base_esp32.kicad_sch]
2024-11-28 add: bypass source
    [base_esp32.kicad_sch]
2024-11-28 fix: vpp for board
    [base_esp32.kicad_sch]
2024-11-28 fix: ERC
    [base_esp32.kicad_sch]
2024-11-28 add: footprints, not done yet
    [base_esp32.kicad_sch]
2024-11-30 fix: schematic & footprint done
    [base_esp32.kicad_sch]
2024-11-30 update: schematic pdf
2024-11-30 add: led to power board
    [base_esp32.kicad_sch]
2024-11-30 add: mounting holes
    [base_esp32.kicad_pcb, base_esp32.kicad_sch]
2024-11-30 fix: package to sw5 dip
    [base_esp32.kicad_pcb, base_esp32.kicad_sch]
2024-12-01 fix: footprints
    [base_esp32.kicad_pcb, base_esp32.kicad_sch]
2024-12-01 fix: pot2 and change footprint
    [base_esp32.kicad_sch]
2024-12-01 fix: some tags for pcb, sorting elements
    [base_esp32.kicad_pcb, base_esp32.kicad_sch]
2024-12-08 add: some components to schematic
    [base_esp32.kicad_pcb, base_esp32.kicad_sch]
2024-12-15 rm: header
    [POTENTIOMETER.STEP, Potentiometer_Trim_THT.step, base_esp32 copy.kicad_pcb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]
2024-12-15 add: ultrasonic
    [HC_SR04.FCStd, HC_SR04_gitter.FCStd, KY-015.step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]
2024-12-19 add: router
    [base_esp32.kicad_pcb, base_esp32.kicad_sch]
2024-12-30 add: mark
    [base_esp32 copy.kicad_pcb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]
2024-12-31 add: svg to fritzing in progress
    [base_esp32-B_Cu.gbl, base_esp32-B_Mask.gbs, base_esp32-B_Paste.gbp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]
2025-01-03 add: esp32 devkit v1
2025-01-04 add: esp32 devkit v1 schematic
2025-01-04 add: finish v0.1 devkit v4
    [base_esp32-B_Cu.gbl, base_esp32-B_Mask.gbs, base_esp32-B_Paste.gbp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]
2026-07-13 update: to kicad10
    [base_esp32.kicad_pcb, base_esp32.kicad_sch]
